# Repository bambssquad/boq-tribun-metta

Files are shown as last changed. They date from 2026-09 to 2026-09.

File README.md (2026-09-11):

# METTA — arsip desain, BOQ dan penawaran

RAB 11 September 2026: `tools.html#rab-11sep` compares all 50x100 hollow members at 1.6, 2.0 and 2.3 mm. Independent editable quantities/prices, stock audit, original Excel comparison and PDF/XLSX exports are available. The 361-cut schedule uses 101 six-metre bars at every thickness; section changes are budget studies and are not applied to Revit. The 6-mm connection plate uses five 1200x2400 sheets with unchanged connection blanks. `assets/r05/analisis-R05.md` records assumptions, sources and unresolved structural checks.

R04 (9 September 2026): `r04.html` is the selected all-in budget, with material, consumables, labor, logistics, overhead, profit and configurable output tax. Its purchasing-weight basis drives the Rp6,000/kg service toggle. Net theoretical and catalog purchasing weights have separate ledgers; unmeasured backing and concrete ties remain explicit provisional sums. Connections and stair supports are design proposals, not a fabrication release.

The current 3D projection contains 165 RHS members, 80 columns, 20 diagonals (10 X sets), 176 native stair plate parts and 310 native 2-mm cover parts. R04 overlays use saved Revit IDs/cut-length readbacks and common plate geometry; R03 source snapshots are retained unchanged. Rear/bottom covers are excluded. Four concrete columns are clipped from the 2-mm panel layout with 3-mm clearance. The archive opens on six current R04 CAD/PDF sheets followed by twelve clearly labeled R03 sheets. Revit sheet previews are under `assets/r04/revit/`.

R04 nesting compares 160 deterministic guillotine heuristics with 10-mm trim and 3-mm kerf: eight 3-mm sheets and twenty-six 2-mm sheets for the fixed current part list. This is the best searched arrangement, not a global optimality proof. `check_r04.py` verifies coverage, kerf/trim, stock capacity, native plate/cover dimensions and mass; `check_r04_web.py` verifies published IDs/counts and links. `r04_controller.test.cjs` checks loading, filters, service toggle, complete printing, sheet dialogs, exports and reset. Run these along with the existing validation and interaction tests. Browser visual parity is not asserted.

Web: https://bambssquad.github.io/boq-tribun-metta/

Halaman utama memuat Timeline, Surf, Indeks dan Proyek dalam hitam-putih tanpa musik. Menu membuka model 3D, gambar teknik interaktif, BOQ dan penawaran pada `tools.html`.

## BOQ dan jasa per kg

Buka **Menu → BOQ & biaya**, lalu aktifkan **Hitung jasa per kg**. Tarif awal Rp6.000/kg mencakup jasa fabrikasi dan pemasangan; material dihitung terpisah. Tarif dapat diubah. Menonaktifkan toggle mengeluarkan jasa dari total tanpa mengubah kuantitas atau harga material.

Dasar penagihan adalah berat pembelian: jumlah lonjor dibulatkan × panjang stok × kg/m, ditambah jumlah lembar dibulatkan × luas lembar × kg/m². Sisa potong termasuk sekali melalui jumlah stok. Saat input R02 dan allowance bawaan digunakan: 7.940,076 kg × Rp6.000 = Rp47.640.456 sebelum material, overhead dan pajak. Rincian setiap komponen dapat dibuka di panel jasa. Berat motif bordes belum terukur; sebagian item masih estimasi sebagaimana catatan BOQ.

**Buka template penawaran** menampilkan surat yang dapat diisi nama perusahaan, klien, nomor, tanggal, lingkup dan termin pembayaran. Nilai jasa mengikuti BOQ. Menu Ekspor menyediakan Excel berumus dengan lembar PENAWARAN, REKAP, INPUT, BOQ dan BERAT; sakelar Excel ada di INPUT!B14 (1 aktif, 0 nonaktif) dan tarif di INPUT!B13. PDF dibuat melalui dialog cetak browser.

Harga material yang kosong belum masuk total. Overhead dan pajak adalah input terpisah; tarif Rp6.000/kg bukan harga material. Spesifikasi dan validasi struktur tetap berada dalam lampiran teknis.

## Pengembangan

Gunakan Python 3.12+ dan Node 22+:

```sh
python -m pip install -r requirements.txt
python build_preview.py
python validate.py
node kg_pricing.test.cjs
node lookback.test.cjs
node panzoom.test.cjs
python publish_public.py
```

Commit sumber beserta hasil publikasi. GitHub Pages memakai berkas statis di root. Workflow memeriksa bahwa halaman terbit sesuai hasil build. Generator `src/` dipertahankan; `build_preview.py` menerapkan data model revisi, `kg_pricing.py` menambahkan tarif jasa, dan `lookback.py` membuat halaman arsip terpisah. `data/` mencatat kuantitas dan asal geometri. `assets/technical/` memuat 12 DXF/SVG, PDF gabungan dan ekspor sheet Revit.

Referensi visual: https://tlb.betteroff.studio/. Implementasi interaksi dan konten METTA dibuat terpisah; musik, font komersial dan kode referensi tidak disertakan.

R03: seluruh 12 gambar kini memiliki 136 dimensi CAD dan label LOD 200. Dimensi terdaftar pada assets/technical/dimensions-R03.json; python check_dimensions.py memeriksa entitas CAD, satuan, PDF dan dasar angka. Jalankan python technical.py untuk memperbarui gambar, lalu build_preview.py. URL unduhan R02 dipertahankan agar tautan lama tetap berfungsi; isi dokumennya telah direvisi R03. Geometri dan harga BOQ tetap. Revit menerima anotasi garis/teks native dan skema dimensi pendamping; belum berupa dimensi asosiatif ke model.

SAP branding: nama lengkap SELARAS ADHI PERKASA tampil pada awal, lalu beralih menjadi SAP ketika scroll dan navigasi; scroll balik mengembalikan nama lengkap. Judul proyek dua baris: ARSIP DESAIN METTA dan (09/2026). Header halaman teknis memakai SAP. Pengujian meliputi wheel, touch, keyboard, menu dan navigasi.

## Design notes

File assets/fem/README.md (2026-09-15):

# METTA - FEM rangka primer tersambung

Ini studi elastis linier 3D dengan enam derajat kebebasan per simpul. Implementasi Python memakai matriks balok Euler-Bernoulli 12 x 12, kekakuan aksial EA/L, torsi Saint-Venant GJ/L, dan dua sumbu lentur. Solver sparse langsung memakai penskalaan diagonal. Tidak ada weak spring atau penambahan tumpuan otomatis saat matriks singular.

## Lingkup dan batas

V1 berasal dari 245 batang RHS native R04. V2 Dasar mengambil native yang dipertahankan dan 54 batang infill R08 selebar 1.400 mm. A/C menambahkan jalur semua 30 tapak melalui 60 girder B02 yang sudah dihitung dalam RAB, 40 riser lap dan dukungan per tier. SHS B03 ditransfer sebagai balok sederhana tanpa kekakuan global. Luas A/C mencakup tambahan 5.999915 m² tapak; Dasar tidak memasukkan beban tangga sehingga bukan perbandingan luas identik. Matriks seluruh geometri singular: 14 batang V1 dan 6 batang V2 tidak memiliki jalur sambungan geometris ke kolom. `excludedSourceIds` mencatat setiap batang tersebut. Submodel yang dihitung hanya jaringan terhubung ke kolom. `grossDeckAreaM2`, `areaM2`, dan `excludedTributaryAreaM2` membedakan seluruh dek, area yang membebani submodel, dan area yang terlewat.

Sambungan dalam jarak sumbu 110 mm diidealkan kaku penuh, termasuk eksentrisitas. Transformasi offset eksak memakai u_slave = u_master + theta cross r. Node pada sumbu yang berjarak kurang dari 5 mm disatukan untuk menghindari elemen numerik sangat pendek; kedua ujung sumber tetap. Semua kontak ini tercantum di `rigidOffsets`. Kedekatan dua solid bukan bukti las atau sambungan: detail sambungan tetap perlu diperiksa insinyur. Kaki kolom dianggap jepit penuh untuk skenario utama, yaitu perkiraan kekakuan atas. Ini bukan bukti lantai atau angkur dapat memberi penjepitan. Sensitivitas `boundarySensitivity` membebaskan rotasi kaki namun tetap menahan semua translasi; skenario ini juga memerlukan angkur, bukan kaki bebas geser/angkat.

Penampang sudut tajam RHS 50x100 memakai tebal nominal 1.6, 2.0, 2.3 mm, E=200000 MPa dan nu=0.3. Orientasi batang horizontal tinggi 100 mm vertikal; kolom lebar 50 mm global X, tinggi penampang 100 mm global Y. Tebal efektif, radius sudut, variasi mutu, tekuk lokal, sambungan dan korosi tidak dihitung. V1/V2 Dasar mengecualikan tangga. A/C memasukkan B02 dan semua tapak, tetapi anggota sekunder SHS, pagar dan mesh tidak memberi kekakuan global; perubahan SHS tidak boleh diklaim mengubah hasil global ini.

Beban D=1.5 kPa dan L=5 kPa adalah skenario yang dipertahankan dari studi R06. D merupakan allowance total termasuk berat sendiri, sehingga berat rangka tidak ditambah lagi. Empat kasus D, L, D+L, 1.2D+1.6L tersedia untuk tiap versi dan tebal. Nilai 1.2D+1.6L hanya satu kombinasi gravitasi, bukan seluruh kombinasi desain. Permukaan dek disatukan per elevasi agar area tumpang tindih tidak dihitung dua kali, kemudian dikurangi footprint beton dengan celah 3 mm. Luas geometris ini tidak menggantikan kuantitas RAB. Permukaan dek dipotong pada batas tributari tengah antar batang yang menyentuh dek (sumbu sekitar 54 mm di bawah permukaan), dengan ukuran sel sepanjang batang maksimum 100 mm pada keluaran utama. Pelat penutup kecil tanpa batang kontak menggunakan sumbu terdekat. Gaya dan kopel dari centroid sel diteruskan ke simpul rangka agar gaya total dan momen global tekanan tetap persis. Transfer ini mengasumsikan pelat dapat memindahkan beban dan kopel tersebut; kekuatan/kekakuan pelat tidak diperiksa. Sensitivitas sel 400, 200 dan 100 mm tersedia di manifest. Konvergensi numerik tidak membuktikan jalur beban atau sambungan aktual; jangan pakai hasil ini untuk fabrikasi.

Tidak termasuk P-delta, nonlinearitas, tekuk global/lokal, kekuatan penampang, sambungan/angkur, gempa, angin, getaran, pondasi atau kapasitas beton. Tidak ada status aman atau lulus SNI. Hasil adalah studi kondisional, bukan analisis SAP2000/Tekla, dan bukan sertifikasi struktur.

## Koreksi sumbu dan diskretisasi

Empat balok diagonal dekat beton dahulu diambil dari bounding box sebagai batang lurus. Hal itu memutus hubungan numerik dan menghasilkan angka sekitar 24 mm. Sumbu sekarang direkonstruksi dari panjang potong, panjang sistem dan grid kolom; empat pengaku lama juga memakai offset ujung native. Bukti tersimpan dalam `data/member-axis-corrections.json`. Perbaikan model hitung ini bukan bukti bangunan pernah mengalami deformasi tersebut. Bounding box empat balok cocok dalam 0.022 mm; empat pengaku memakai panjang/offset audit dengan selisih terhadap kotak visual lama maksimum 2.72 mm.

RHS 2.3 mm, D+L=6.5 kPa, asumsi tumpuan seperti dijelaskan:

| Model | Sel 100 mm (tampilan) | Sel 50 mm (pembanding) | Perubahan |
|---|---:|---:|---:|
| V1 primer | 2.0802 mm | 2.0793 mm | 0.0403% |
| V2 Dasar primer | 1.2665 mm | 1.2696 mm | 0.2417% |
| V2 A termasuk dua tangga | 1.2674 mm | 1.2705 mm | 0.2401% |
| V2 C termasuk dua tangga | 1.2656 mm | 1.2687 mm | 0.2479% |

Semua 48 kasus memakai sel 100 mm. Ini sensitivitas numerik terhadap pembagian beban, bukan pembuktian kapasitas. Riser lap berada di luar sisi tapak supaya tidak menembus pelat; sambungan las sisi, cope antar batang dan kapasitas dinding RHS tetap perlu detail.

## Konvensi keluaran

Panjang mm, gaya N, momen Nmm, rotasi rad. Sumbu lokal x dari a ke b; z mengikuti global Z sejauh mungkin (kolom menggunakan global Y); y=z cross x. `i` dan `j` adalah gaya nodal lokal [N,Vy,Vz,T,My,Mz] di kedua ujung, sesuai matriks elemen. Scalar tiap komponen memilih nilai ujung dominan dengan tanda gaya ujung asli. Ini envelope gaya ujung, bukan diagram internal sepanjang batang kontinu. Deformasi display dapat dibesarkan tetapi data tetap mm aktual. Animasi perubahan faktor skala bukan analisis dinamik.

Model geometri tersedia dalam `model.json.gz`. Dua belas file `solution-v*-h*.json.gz` dikompresi gzip deterministik (mtime=0) dan berisi hasil untuk tekanan 1 kPa. Manifest `results.json` memuat 48 kasus, `solutionId` dan `resultScale`. Hasil perpindahan, gaya dan reaksi dikalikan faktor ini; summary kasus sudah diskalakan. Ini superposisi elastis linier eksak, bukan interpolasi hasil ketebalan.

## Reproduksi

Manifest menyimpan hash sumber solver dan geometri. `check_fem.py` menolak hasil lama bila sumber berubah; jalankan generator kembali setelah revisi geometri.

Dependensi: Python, numpy, scipy, shapely; sumber r04_model.py dan data R04/R08 di repositori.

```
python fem_model.py
python check_fem.py
```

Uji mencakup enam rigid-body modes, simetri, kantilever aksial/torsi/lentur dua arah, balok sendi-rol beban titik tengah, transformasi offset kaku, penolakan mekanisme bebas, keseimbangan gaya dan momen seluruh 48 kasus, area-tekanan, tren tebal dan perbedaan geometri V1/V2. Uji analitik membuktikan formulasi solver; tidak membuktikan asumsi sambungan dan beban bangunan.

## Referensi primer metode

- TU Delft, Euler-Bernoulli beam elements: https://interactivetextbooks.citg.tudelft.nl/computational-modelling/structural_linear/euler_bernouilli.html
- numgeo, beam formulation and local/global transformation: https://j-machacek.github.io/numgeo/theory/elements/beam.html
- TU Delft, 3D Euler beam stiffness research: https://pure.tudelft.nl/ws/portalfiles/portal/55207149/6.2019_3272.pdf

Referensi metode diperiksa pada 15 September 2026. Numgeo menjelaskan pula deformasi geser Timoshenko; implementasi ini memakai batas Euler-Bernoulli tanpa deformasi geser.

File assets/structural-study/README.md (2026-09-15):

# Perbandingan A/C - dua tangga penuh

Koreksi sumbu native menghilangkan putus sambungan numerik yang menghasilkan angka lama sekitar 24 mm. A/C bukan klaim bahwa penambahan material itu yang menghilangkan 24 mm.

A memakai rangka utama, 40 penghubung riser las, 10 cleat pendek dan dua header ke kolom beton pada landing tengah. C memakai 40 penghubung riser serta lima kotak penopang per tangga (40 kolom, 40 balok, 40 diagonal). Sebanyak 60 girder sisi B02 tetap berasal dari RAB dasar; tidak dihitung dua kali. Seluruh 30 tapak masuk beban A/C, sebesar 5.999915 m². Ini menggantikan percobaan kasar menumpuk seluruh beban flight hanya pada satu landing.

`options-spec.json` merupakan geometri usulan dan input RAB. `analysis.json` berisi tiga tebal RHS, tegangan gross, reaksi angkur (demand saja), pemeriksaan benturan, pemeriksaan SHS lokal serta beban horizontal fiktif 0.2%. Beban horizontal tersebut hanya uji kekakuan elastis orde pertama; bukan analisis langsung AISC, gempa, angin atau P-delta.

## Batas keputusan

- RHS1.6 mendekati Fy235 pada screening tegangan gross gabungan. Nilai di bawah Fy tidak membuktikan kapasitas setelah tekuk lokal/global, reduksi tebal, las dan sambungan.
- Semua kaki (80 kolom utama, infill dan kaki C) mengandalkan kapasitas lantai/angkur yang belum diketahui. Budget angkur tidak membuktikan tumpuan jepit. Pad karet10mm perlu verifikasi tekan dan slip.
- Railing SHS40x40 kantilever1100mm belum memenuhi target lendutan11mm untuk keempat tebal. Kandidat berikutnya A=SHS60x60x2.3; C=pengaku atau distribusi beban pegangan yang dihitung. Kandidat ini belum mengganti gambar/RAB pagar.
- SHS B03 diperiksa lokal sebagai balok550mm dengan tributari115mm dan kasus beban titik1.334kN. Pelat3mm, lipatan, luas kontak beban titik dan sambungan masih membutuhkan pemeriksaan pelat terpisah.
- Las pada riser lap166.7mm dan cleat45mm harus dibuktikan mampu meneruskan momen. Hardware/konsumsi las dalam RAB hanya allowance.
- Analisis stabilitas orde kedua, beban lokasi, gempa/angin, getaran kerumunan dan kapasitas beton belum lengkap. Tidak ada status siap fabrikasi atau aman terverifikasi.

## Reproduksi

```
python geometry_axes.py
python structural-study.py
python fem_model.py
python structural-study.py --analyse
python check_fem.py
node check_fem_viewer.cjs
```

Sumber primer metode dan pemeriksaan tersedia di analysis.json dan assets/fem/README.md. Semua asumsi harus ditinjau sebelum keputusan pelaksanaan.

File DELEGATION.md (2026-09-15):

# Delegation plan
Units: 3

Gate open: three independent units; user requested colony. Current correction replaces the sketched right stair strip with seating deck, and investigates structural improvements. V1 design remains archived, with corrected interpretation of native diagonal axes.

| # | Unit | Files (mine) | Worker | Acceptance | Status |
|---|---|---|---|---|---|
| 1 | Geometry, quantities, PDF, integration and publication | r08.py, r08_options.py, boq_revision_web.py, check_r08.py, r08.test.cjs, pdf-mass.test.cjs, r08-pdf.cjs, generated assets/r08 data/geometry/audit/csv/pdf, DELEGATION.md, workflow, publication copies | root | Sketched strip has no stairs; geometry and quantities reconcile; PDF and publication payload match | verified |
| 2 | Version display and technical drawings | r04_model.py, site_version.py, site-version.js, site-version-viewer.js, boq-revision.js, boq-revision-controller.js, r08_drawings.py, detail_drawings.py, check_site_version.cjs, check_detail_drawings.py, drawing-viewer.js, generated SVG and drawing manifests | drawings + root integration | V2 infill 1400 mm and two stair strips; V1 geometry retained with corrected member axes; browser and drawing tests pass | verified |
| 3 | Structural diagnosis and verified improvement study | fem_model.py, check_fem.py, geometry_axes.py, data/member-axis-corrections.json, assets/fem/*, fem-viewer.js, check_fem_viewer.cjs, structural-study.py, assets/structural-study/* | fem | Numerical benchmarks and equilibrium pass; improvement compared under identical loads; limitations explicit | verified |

## Evidence
User selected comparison A (main concrete columns) and C (independent frame). All three local acceptance units are verified; publication follows. No safety or fabrication approval is inferred from elastic deformation alone.

- Root independently ran `node check_site_version.cjs` and `python check_detail_drawings.py`; actual A/C member vertices, column counts, independent edits and XML sheets match. Browser front view confirms precisely two stair strips and continuous seating at the sketched strip. Root applied final component-label integration for main-floor anchors.
- Root independently checked eight reconstructed axis lengths against native Cut Length; four bearer bounding residuals below0.022mm and four brace residuals below2.712mm. Corrections describe geometry interpretation, not new steel.
- Root rendered and inspected all26 portrait RAB pages (base8,A9,C9). `python check_r08.py` reconciles source cut deltas, all thickness masses, removed struts, shared plate nesting, floor/RC anchor counts, and every PDF row and total.

- Root independently passed all 38 workflow checks, including 48 equilibrium/benchmark FEM cases, 540 RAB combinations and 30 PDF exports. Browser confirms A/C service displacements 1.267/1.266 mm at RHS 2.3, and 1.777 mm A at 1.6. Fixed stale FEM fetch and missing-model failure gating; targeted viewer tests passed again.

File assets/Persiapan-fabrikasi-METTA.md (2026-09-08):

# METTA — persiapan fabrikasi, belum terbit untuk produksi

## Revisi model 3D

Enam belas diagonal diberi Mark X01-A sampai X08-B. Titik bawah diubah dari +18 menjadi +150 mm terhadap LT4; titik atas tetap +2350 mm. Tujuannya memberi ruang dari zona dudukan. Potongan C-C telah diperiksa secara visual. Ini koreksi koordinasi, bukan ukuran sambungan yang sudah dihitung. Delapan pasangan dikelompokkan sebagai assembly koordinasi; jangan mengelas kedua diagonal pada persilangan hanya karena berada dalam satu assembly.

Daftar potong optimal diperbarui dari parameter model sesudah perubahan: 161 framing memerlukan minimum 75 batang stok 6 m untuk input studi ini. Panjang potongan 415.239 mm, kerf 483 mm, sisa 34.278 mm. Sisa termasuk kerf 7,725%. Hasil sebelumnya 7,389% sudah digantikan. Kolom, railing, plat, trimming stok dan allowance sambungan belum termasuk.

## Ketentuan dari web Bam

Sumber: https://bambssquad.github.io/boq-tribun-metta/ , salinan proyek dengan DATA.rev 9056af5e6b. Pembacaan daring ulang gagal; ketentuan di bawah dibaca dari salinan yang sudah tersimpan.

| Detail web | Isi sumber | Perlakuan pada revisi |
|---|---|---|
| Tumpuan | Base 150×150×8, karet 10; duduk lepas, tanpa angkur pelat lantai | Pertahankan prinsip tanpa pengeboran lantai; verifikasi reaksi dan geser/angkat melalui jalur ikatan kolom |
| D1 balok-kolom | 2 M12 grade 4.6 + pelat siku 6, atau las a=4 dua kali 80 | Pilihan detail harus sesuai gaya dan dinding RHS; belum instruksi produksi |
| D2 bracing-kolom | Buhul 6 mm 200×200; las a=4 dua sisi 40 | Web semula untuk bracing 40×40×2, kini model 50×100×2,3; tidak bisa langsung dianggap detail lolos |
| D3 strut-beton | Pelat 6, 2 dynabolt M10, kedalaman 80 | Hanya ke kolom beton. Produk, tulangan, tepi, kapasitas dan beban masih harus diverifikasi |
| D4 railing-dek | Las a=4 keliling | Dek berkurang 8 menjadi 4 mm; periksa transfer momen railing ke rangka, bukan plat saja |

Istilah las a=4 pada web perlu dipastikan: tebal tenggorokan atau panjang kaki las. Jangan menerjemahkannya diam-diam ke spesifikasi lain. Tidak ada gusset, lubang angkur atau simbol las final yang ditambahkan atas dasar angka web saja.

## Data yang ditunggu

Bam menyatakan spesifikasi material sudah dikonfirmasi dan akan memberikan sertifikat. Dokumen belum diterima pada saat pembaruan ini. Perlu tebal dasar bordes tanpa motif, standar/grade hollow, tebal aktual dan sertifikat yang terkait material yang dibeli. Untuk ikatan kolom beton diperlukan data struktur eksisting dan verifikasi insinyur struktur. Gambar arsitektur dan BOQ tidak menyediakan kapasitas tersebut.

Model dan daftar potong boleh dipakai untuk koordinasi dan estimasi. Jangan mulai pemotongan, pengelasan atau pengeboran dari paket ini sebelum detail serta perhitungan diselesaikan.

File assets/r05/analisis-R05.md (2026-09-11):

# METTA — verifikasi batang, kilogram dan RAB 11 September 2026

Status: perbandingan anggaran dan penyaringan awal struktur. Belum menjadi desain pelaksanaan yang telah memenuhi seluruh pemeriksaan standar.

## Keputusan yang digunakan

- Toggle 1,6 / 2,0 / 2,3 mm berlaku pada seluruh hollow 50×100: kolom, balok, pengaku, bracing dan usulan penyangga tangga. Dimensi luar, posisi, panjang potong dan jumlah tempat duduk tetap.
- Model Revit masih 2,3 mm. Versi 1,6 dan 2,0 mm adalah skenario perbandingan, belum diterapkan ke model native.
- Ukuran stok pelat sambungan 6 mm adalah 120×240 cm. Potongan kupingan 90×120 mm dan buhul 200×200 mm tetap.

## Mengapa 54 batang di Excel berbeda dari 101 di web

Lima baris hollow 50×100 pada Excel berjumlah 1.620 kg. Dibagi asumsi 30 kg/batang menghasilkan 54 batang. Dengan massa katalog 32,5 kg/batang, nilainya 49,85 batang ekuivalen. Keduanya belum membuktikan jumlah batang yang dapat dipotong menjadi seluruh anggota model.

| Lingkup | Potongan | Panjang bersih | Stok 6 m bila dipotong terpisah | Berat pembelian 2,3 mm |
|---|---:|---:|---:|---:|
| Rangka dan kolom Revit | 245 | 552,301 m | 97 | 3.152,50 kg |
| Penyangga tangga usulan | 116 | 37,837 m | 7 | 227,50 kg |
| Seluruhnya, sisa potong dipakai bersama | 361 | 590,138 m | 101 | 3.282,50 kg |

97 + 7 menjadi 101 saat dipotong bersama; sisa batang dari kelompok pertama digunakan untuk potongan kelompok lain. Angka 101 adalah solusi pola potong yang layak, bukan bukti optimum global. Sebanyak 361 ID potongan unik telah diperiksa. Tidak ada geometri RHS duplikat persis atau pengaku memanjang segaris yang menumpuk pada arsip geometri yang direkonsiliasi.

| Komponen | Potongan | Panjang model | Kg bersih penampang 2,3 mm | Kg pembelian teralokasi | Kg Excel |
|---|---:|---:|---:|---:|---:|
| Kolom tribun | 80 | 133,560 m | 686,96 | 738,95 | 637 |
| Balok tepi tier | 15 | 73,710 m | 379,12 | 409,49 | 416 |
| Pengaku longitudinal dek | 45 | 226,069 m | 1.162,78 | 1.243,32 | 416 |
| Rangka belakang | 4 | 17,396 m | 89,48 | 95,11 | 98 |
| Strut ke kolom beton | 16 | 2,172 m | 11,17 | 11,85 | 53 |
| Bracing X | 20 | 42,388 m | 218,02 | 235,70 | 62 (40×40×2) |
| Balok silang penumpu dek | 65 | 57,006 m | 293,21 | 314,04 | Tidak terpisah |
| Penyangga tangga / usulan | 116 | 37,837 m | 194,61 | 234,03 | Tidak terpisah |

Perbedaan utama adalah pengaku longitudinal: Excel 416 kg, sedangkan 45 anggota model memiliki panjang 226,069 m dan massa penampang bersih sekitar 1.162,78 kg. Sebanyak 65 balok silang dihitung terpisah. Bracing Excel memakai 40×40×2 mm, sedangkan bracing model aktif memakai 50×100×2,3 mm. Penyangga tangga 116 potongan masih usulan tambahan dan diberi label tersebut.

Berat bersih penampang memakai dimensi luar dan sudut membulat; berat pembelian memakai massa katalog stok. Nilai ini tidak boleh dicampur saat mengonversi kg menjadi jumlah batang. Berat timbang, sertifikat dan tebal aktual produk belum tersedia.

## Perbandingan tebal seluruh hollow 50×100

| Tebal | Jumlah stok | Kg/batang 6 m | Total kg pembelian | Harga/batang untuk anggaran | Dasar |
|---|---:|---:|---:|---:|---|
| 1,6 mm | 101 | 22,61 | 2.283,61 | Rp 302.278 | Estimasi: massa interpolasi katalog 1,5/1,8 mm dan harga/kg Excel 2,3 mm; bukan penawaran 1,6 mm. |
| 2,0 mm | 101 | 28,26 | 2.854,26 | Rp 373.900 | Katalog SMS Perkasa, harga tayang 27 Agustus; dibaca 11 September 2026. |
| 2,3 mm | 101 | 32,50 | 3.282,50 | Rp 434.500 | Katalog SMS Perkasa; sama dengan tarif Excel. |

Untuk 1,6 mm, massa 22,61 kg merupakan interpolasi katalog 1,5 dan 1,8 mm. Harga/kg memakai tarif 2,3 mm dalam Excel. Harga tersebut belum menjadi harga pemasok 1,6 mm. Untuk 2,0 dan 2,3 mm, massa dan harga berasal dari katalog SMS Perkasa yang menampilkan tanggal harga 27 Agustus 2026, dibaca 11 September 2026.

| Versi | Upah/jasa | Material | Total tanpa pelengkap | Total dengan pelengkap |
|---|---:|---:|---:|---:|
| 1,6 mm / studi | Rp 62.493.320 | Rp 159.639.227 | Rp 222.132.547 | Rp 251.647.547 |
| 2,0 mm / studi | Rp 65.917.221 | Rp 166.873.018 | Rp 232.790.239 | Rp 262.305.239 |
| 2,3 mm / model | Rp 68.486.661 | Rp 172.993.619 | Rp 241.480.280 | Rp 270.995.280 |

Semua total sebelum overhead, laba dan pajak tambahan. Pelengkap proyek Rp 29.515.000 mencakup backing/hardware, antiselip, clear coat, tekuk, transportasi, alat angkat, perancah, pengukuran, proteksi dan cadangan pemeriksaan desain/tumpuan. Alat kerja dan kawat las mengikuti pembagian biaya sumber; listrik disediakan METTA. Perubahan desain sambungan atau penguatan dapat mengubah biaya tersebut.

## Pelat sambungan: lembar 120×240 cm

- Stok: 5 lembar × 1,2 m × 2,4 m × 0,006 m × 7.850 kg/m³ = 678,24 kg teoritis.
- Potongan tetap: 464 kupingan tangga + 548 kupingan rangka berukuran 90×120 mm, serta 40 buhul 200×200 mm; total 1.052 bagian.
- Luas potongan 12,5296 m²; berat bersih 590,144 kg sebelum lubang. Berat beli mencakup seluruh sisa lembar sekali.
- Lima lembar dibuktikan dengan pola penempatan. Batas tepi 10 mm, celah potong 3 mm, semua bagian berada dalam lembar dan tidak bertumpuk.
- Nilai lama 700 kg menggunakan 5 × 140 kg katalog. Untuk stok tepat 1200×2400 mm, massa dihitung ulang menjadi 678,24 kg; tarif/kg tetap dari Excel. Ukuran buhul tidak diganti menjadi ukuran lembar.
- Berkas pola pelat dan pola batang tersedia sebagai CSV; berat batang dicantumkan hanya sekali per stok agar penjumlahan tidak berulang.

## Audit sumber model

- Revit 2027: 385 elemen dibaca, termasuk 175 framing, 165 kolom/tiang railing, 30 dek dan 15 papan pinus. Seluruh 165 ID RHS dan panjang potongnya cocok dengan R04.
- SHA256 model tersimpan sama dengan checkpoint R04. Ekspor IFC baru gagal transaksi; geometri arsip yang direkonsiliasi dan registri native tetap disebut sebagai sumber.
- Luas dek 82,345049121 m². Dua elemen 1686791 dan 1686827 mengembalikan luas nol; tidak diberikan luas fiktif.
- Pelat tangga 176 bagian dan penutup 310 bagian memakai registri native R04. Sebagian penyangga dan detail sambungan masih usulan anggaran.
- Family 10 rail horizontal masih bernama M_W Shapes dan menyimpan properti profil lama. Beberapa properti A/W kolom juga lama; biaya memakai panjang, penampang dan massa katalog yang dijelaskan, bukan berat family tersebut.

## Batas penyaringan struktur

Asumsi: E 200.000 MPa, Fy 235 MPa, massa jenis 7.850 kg/m³, radius luar 2t dan radius dalam t. Beban mati 1,5 kN/m², hidup 5 kN/m², titik 1,334 kN. Beban merata dan titik diperiksa sebagai alternatif bersama beban mati. Kombinasi gravitasi 1,2D+1,6L; batas lendutan L/360. Tebal 93% nominal hanya sensitivitas, bukan toleransi produk yang telah dibuktikan.

| Tebal nominal | Rasio lentur pengaku, 2 m | Rasio lentur balok silang | Kesimpulan terbatas |
|---|---:|---:|---|
| 1,6 mm | 0,533 | 1,004 | Balok silang melewati batas kasus |
| 2,0 mm | 0,435 | 0,820 | Lolos kasus batang ini; belum membuktikan rangka |
| 2,3 mm | 0,384 | 0,724 | Lolos kasus batang ini; belum membuktikan rangka |

Pengaku memakai lebar tributari 250 mm dan bentang minimal 2 m. Balok silang diuji bentang 1.060 mm dengan lebar tributari 1,77 m. Tumpuan dan pengekangan lateral disimpulkan dari geometri untuk studi; keduanya harus dibuktikan pada detail. Kapasitas kolom hanya dihitung untuk sensitivitas tekan murni K=1 dan K=2, tanpa rasio kelulusan karena gaya rangka belum ditentukan.

Versi 1,6/2,0/2,3 mm adalah perbandingan biaya untuk susunan yang sama. Versi seluruh rangka 1,6 mm tidak lolos kasus penyaringan balok silang pada tebal asumsi 1,488 mm. Tidak satu pun versi dinyatakan memenuhi seluruh pemeriksaan struktur.

Belum selesai: analisis rangka tiga dimensi, stabilitas/goyang, gempa, getaran akibat aktivitas serempak, diafragma, pelat/tapak lokal, dinding hollow pada reaksi, las/baut, angkur, transfer gaya melalui base plate/karet, dan kapasitas beton LT4. Data sertifikat baja, tebal aktual, mutu beton serta tulangan dibutuhkan untuk menutup pemeriksaan tersebut.

## Koreksi terhadap Excel sumber

- Subtotal upah I32 dan material J32 berhenti di baris 30, sehingga cat pada baris 31 terlewat. Rekap sumber lengkap: upah Rp 62.143.000, material Rp 156.653.686, total Rp 218.796.686.
- Label paket baut + mur + ring dipecah supaya tidak ditafsirkan ganda. Tangga memakai 488 baut, 488 mur dan 976 ring; rangka 693 baut, 693 mur dan 1.386 ring masih berdasarkan usulan sambungan.
- Karet mengikuti 80 titik dudukan. Pinus mengikuti volume 1,197016252 m³, menjadi 74,813516 m bersih dan 82,294867 m pembelian dengan sisa 10%.
- Cat mengikuti luas estimasi 626,0562 m². Nilai paket Excel Rp 28.885.500 dinormalisasi menjadi tarif/m²; penipisan dinding hollow tidak menurunkan luas permukaan cat.
- Angkur 32 buah M10 pada Excel diganti cadangan biaya ikatan beton karena jumlah dan kapasitasnya belum ditetapkan.

## Sumber primer

SNI 1727:2020 menjadi acuan beban; SNI 1729:2020 mengadopsi AISC 360-16 untuk baja struktural. SNI 7971:2013 digunakan bila produk/sistem berada dalam ruang lingkup baja canai dingin. Jalur standar harus mengikuti spesifikasi produk, bukan tebal saja. Gempa dan beton juga memerlukan SNI 1726:2019 serta SNI 2847:2019. Studi ini tidak menyatakan seluruh persyaratan tersebut telah dipenuhi.

- [SNI 1727:2020](https://pesta.bsn.go.id/produk/detail/12927-sni17272020)
- [SNI 1729:2020, adopsi AISC360-16](https://pesta.bsn.go.id/produk/detail/12882-sni17292020)
- [SNI 7971:2013; bila standar produk canai dingin berlaku](https://pesta.bsn.go.id/produk/detail/9714-sni79712013)
- [AISC360-16 B4, E3/E7, F7, G5](https://www.aisc.org/globalassets/aisc/publications/standards/a360-16-spec-and-commentary_june-2019_linked.pdf)
- [ICC300-2017 303; pembanding beban tribun](https://codes.iccsafe.org/content/ICC3002017/chapter-3-construction?site_type=public)
- [Katalog hollow50x100x1,6; tanpa harga/sertifikat](https://jualbesi.com/produk/besi-hollow-hitam-50x100x1-6/)
- [Harga dan massa stok pembanding1,5/1,8/2,3mm, 11 September2026](https://www.smsperkasa.com/produk/besi-hollow-hitam)

Tidak ada pemasok yang dihubungi dan tidak ada pembelian yang dilakukan.

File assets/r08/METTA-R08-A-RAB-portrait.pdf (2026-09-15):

# SAP / SELARAS ADHI PERKASA

## RENCANA ANGGARAN BIAYA - METTA

R08 - Infill sesuai gambar + mesh sisi / Hollow 2,3 mm / model / SHS acuan 2,0 / 2,8 mm / A / bantuan kolom beton / Mesh 25x25 /
2,0 mm | 2026-09-15 | Pembelian | Dengan biaya pelengkap

STUDI OPTIMASI. BELUM UNTUK FABRIKASI.

No. | Pekerjaan / spesifikasi | Volume | Sat. | Upah/sat. | Material/sat. | Jumlah upah | Jumlah material | Total
1 | Kolom tribun Hollow 50x100x2,3 mm | 738,9357 | kg | 6.000 | 13.369 | 4.433.614 | 9.879.002 | 14.312.616
2 | Balok tepi tier Hollow 50x100x2,3 mm | 405,2193 | kg | 6.000 | 13.369 | 2.431.316 | 5.417.470 | 7.848.786
3 | Pengaku longitudinal dek Hollow 50x100x2,3 mm | 1.249,7162 | kg | 6.000 | 13.369 | 7.498.297 | 16.707.745 | 24.206.042
4 | Rangka belakang Hollow 50x100x2,3 mm | 94,7112 | kg | 6.000 | 13.369 | 568.267 | 1.266.216 | 1.834.483
5 | Strut ke kolom beton Hollow 50x100x2,3 mm | 0 | kg | 6.000 | 13.369 | 0 | 0 | 0
6 | Bracing X Hollow 50x100x2,3 mm | 234,0089 | kg | 6.000 | 13.369 | 1.404.054 | 3.128.519 | 4.532.573
7 | Balok silang penumpu dek Hollow 50x100x2,3 mm | 312,9445 | kg | 6.000 | 13.369 | 1.877.667 | 4.183.827 | 6.061.494
Subtotal Rangka utama | | | | | | 18.213.215 | 40.582.779 | 58.795.994
8 | Penyangga tangga / usulan Hollow 50x100x2,3 mm | 108,1501 | kg | 6.000 | 13.369 | 648.901 | 1.445.884 | 2.094.785
9 | Pelat tekuk tangga Pelat polos 3 mm | 271,296 | kg | 6.000 | 12.286 | 1.627.776 | 3.333.065 | 4.960.841
10 | Pengaku tapak tangga / usulan SHS 40x40x2 mm | 168,1487 | kg | 6.000 | 12.987 | 1.008.892 | 2.183.691 | 3.192.583
11 | Baut tangga M12x40 kelas 8.8 | 84 | bh | 1.000 | 4.500 | 84.000 | 378.000 | 462.000
12 | Mur tangga M12 kelas 8 | 84 | bh | 1.000 | 1.500 | 84.000 | 126.000 | 210.000
13 | Ring tangga Ring datar keras M12 | 168 | bh | 50 | 750 | 8.400 | 126.000 | 134.400
Subtotal Tangga | | | | | | 3.461.969 | 7.592.640 | 11.054.609
14 | Rail atas / elemen horizontal SHS 40x40x2 mm | 30,14 | kg | 6.000 | 12.987 | 180.840 | 391.418 | 572.258
15 | Tiang railing dan pegangan SHS 40x40x2,8 mm | 379,8 | kg | 6.000 | 13.128 | 2.278.800 | 4.986.000 | 7.264.800
Subtotal Railing | | | | | | 2.459.640 | 5.377.418 | 7.837.058
16 | Pelat dek Bordes 4 mm | 3.074,688 | kg | 5.000 | 12.937 | 15.373.440 | 39.777.239 | 55.150.679
17 | Riser, fascia dan return Pelat polos 2 mm | 904,32 | kg | 6.000 | 12.296 | 5.425.920 | 11.119.787 | 16.545.707
18 | Papan pinus dudukan Lebar 400 mm; tebal 40 mm | 89,6765 | m | 25.000 | 90.000 | 2.241.913 | 8.070.887 | 10.312.800
19 | Panel kayu sandaran Lebar 400 mm; tebal 40 mm | 20,0475 | m | 25.000 | 90.000 | 501.188 | 1.804.275 | 2.305.463
20 | Cat dan coating baja Persiapan + cat; luas permukaan | 617,039 | m² | 13.183 | 32.956 | 8.134.131 | 20.335.327 | 28.469.458
Subtotal Dek, penutup dan finishing | | | | | | 31.676.592 | 81.107.515 | 112.784.107
21 | Base plate Pelat 150x150x8 mm | 146,6465 | kg | 6.000 | 11.695 | 879.879 | 1.715.058 | 2.594.937
22 | Pelat sambungan rangka, tangga dan buhul Pelat 6 mm; lembar 120x240 cm | 542,592 | kg | 5.000 | 12.543 | 2.712.960 | 6.805.654 | 9.518.614
23 | Baut rangka dan X M12x40 kelas 8.8 | 777 | bh | 1.000 | 4.500 | 777.000 | 3.496.500 | 4.273.500
24 | Mur rangka dan X M12 kelas 8 | 777 | bh | 1.000 | 1.500 | 777.000 | 1.165.500 | 1.942.500
25 | Ring rangka dan X Ring datar keras M12 | 1.554 | bh | 50 | 750 | 77.700 | 1.165.500 | 1.243.200
26 | Ikatan ke kolom beton / cadangan Angkur dan pelat: belum ditetapkan | 0 | ls | 0 | 2.500.000 | 0 | 0 | 0
METTA / Hollow 2,3 mm / model | 1 / 9

No. | Pekerjaan / spesifikasi | Volume | Sat. | Upah/sat. | Material/sat. | Jumlah upah | Jumlah material | Total
27 | Sekrup kayu ke baja + ring #12x65 / usulan | 540 | set | 300 | 1.500 | 162.000 | 810.000 | 972.000
28 | Sekrup penutup + ring EPDM #12x32 / usulan | 3.909 | set | 300 | 800 | 1.172.700 | 3.127.200 | 4.299.900
29 | Karet dudukan 150x150x10 mm | 80 | bh | 500 | 25.000 | 40.000 | 2.000.000 | 2.040.000
Subtotal Sambungan dan pengikat | | | | | | 6.599.239 | 20.285.412 | 26.884.651
30 | Backing riser depan dan hardware railing Backing penutup dan hardware railing / provisional sum | 1 | ls | 0 | 3.500.000 | 0 | 3.500.000 | 3.500.000
31 | Sistem antiselip tangga Sistem antiselip permukaan tangga | 5,9999 | m2 | 0 | 125.000 | 0 | 749.989 | 749.989
32 | Clear coat kayu Clear coat kayu | 20 | L | 0 | 100.000 | 0 | 2.000.000 | 2.000.000
33 | Jasa tekuk pelat Jasa press brake | 60 | tekuk | 20.000 | 0 | 1.200.000 | 0 | 1.200.000
34 | Angkut bengkel-lokasi + bongkar Biaya pelengkap proyek | 2 | rit | 1.500.000 | 0 | 3.000.000 | 0 | 3.000.000
35 | Hoist dan alat angkat LT4 Biaya pelengkap proyek | 7 | hari | 500.000 | 0 | 3.500.000 | 0 | 3.500.000
36 | Perancah dan penyangga sementara Biaya pelengkap proyek | 1 | ls | 2.500.000 | 0 | 2.500.000 | 0 | 2.500.000
37 | Pengukuran + kontrol mutu las/cat Biaya pelengkap proyek | 1 | ls | 2.000.000 | 0 | 2.000.000 | 0 | 2.000.000
38 | Pembersihan, APD dan proteksi Biaya pelengkap proyek | 1 | ls | 1.500.000 | 0 | 1.500.000 | 0 | 1.500.000
39 | Verifikasi desain + investigasi tumpuan Biaya pelengkap proyek | 1 | ls | 7.500.000 | 0 | 7.500.000 | 0 | 7.500.000
Subtotal Biaya pelengkap | | | | | | 21.200.000 | 6.249.989 | 27.449.989
40 | Kolom tambahan infill Hollow 50x100x2,3 mm | 140,2376 | kg | 6.000 | 13.369 | 841.425 | 1.874.868 | 2.716.293
41 | Balok memanjang infill Hollow 50x100x2,3 mm | 105,6237 | kg | 6.000 | 13.369 | 633.742 | 1.412.107 | 2.045.849
42 | Pengaku silang infill Hollow 50x100x2,3 mm | 185,4528 | kg | 6.000 | 13.369 | 1.112.717 | 2.479.362 | 3.592.079
43 | Base plate infill Pelat 8 mm / 140x150 mm | 34,2175 | kg | 6.000 | 11.695 | 205.305 | 400.180 | 605.485
44 | Angkur lantai infill M12 / allowance sambungan, mutu dan penanaman belum dipilih | 84 | set | 15.000 | 35.000 | 1.260.000 | 2.940.000 | 4.200.000
45 | Karet dudukan infill Karet 140x150x3 mm / allowance | 20 | bh | 500 | 25.000 | 10.000 | 500.000 | 510.000
46 | Angkur lantai kolom utama M12 / allowance; spesifikasi dan kapasitas belum ditetapkan | 336 | set | 15.000 | 35.000 | 5.040.000 | 11.760.000 | 16.800.000
Subtotal Infill baru | | | | | | 9.103.189 | 21.366.517 | 30.469.706
47 | Rangka panel mesh SHS 40x40x2 mm | 299,0213 | kg | 6.000 | 12.987 | 1.794.128 | 3.883.290 | 5.677.418
48 | Kawat loket penutup sisi Galvanis 25x25 mm / kawat 2.0 mm | 70 | kg | 0 | 30.000 | 0 | 2.100.000 | 2.100.000
49 | Strip penjepit tepi mesh Flat bar 30x3 mm / dua sisi vertikal dan horizontal per panel | 84,78 | kg | 6.000 | 15.000 | 508.680 | 1.271.700 | 1.780.380
50 | Pengikat mesh dan rangka panel M6 galvanis + mur + ring / allowance | 1.218 | set | 1.000 | 2.500 | 1.218.000 | 3.045.000 | 4.263.000
51 | Pemasangan dan potong mesh Panel kawat loket; ujung kawat ditutup strip | 13,8739 | m2 | 35.000 | 0 | 485.585 | 0 | 485.585
Subtotal Penutup mesh | | | | | | 4.006.393 | 10.299.990 | 14.306.383
52 | Angkur tambahan struktur / tangga M12 / allowance; produk dan kapasitas belum ditetapkan | 9 | set | 15.000 | 35.000 | 135.000 | 315.000 | 450.000

No. | Pekerjaan / spesifikasi | Volume | Sat. | Upah/sat. | Material/sat. | Jumlah upah | Jumlah material | Total
53 | Bahan habis pakai sambungan las tambahan Allowance bahan las; detail prosedur dan ukuran las belum disahkan | 30 | m | 0 | 10.000 | 0 | 300.000 | 300.000
Subtotal Pekerjaan lain | | | | | | 135.000 | 615.000 | 750.000
TOTAL | | | | | | 96.855.237 | 193.477.260 | 290.332.497

## SUBTOTAL PER KOMPONEN - REKAP BIAYA YANG SAMA

Komponen | Upah | Material | Gabungan
Kolom | 5.275.039 | 11.753.870 | 17.028.909
Balok | 5.510.992 | 12.279.620 | 17.790.612
Pengaku dek dan strut | 8.611.014 | 19.187.107 | 27.798.121
Bracing | 1.404.054 | 3.128.519 | 4.532.573
Tangga dan penyangga | 3.461.969 | 7.592.640 | 11.054.609
Rail horizontal | 180.840 | 391.418 | 572.258
Tiang railing dan pegangan | 2.278.800 | 4.986.000 | 7.264.800
Pelat dek | 15.373.440 | 39.777.239 | 55.150.679
Penutup | 5.425.920 | 11.119.787 | 16.545.707
Pelat sambungan dan base plate | 3.592.839 | 8.520.712 | 12.113.551
Sambungan dan pengikat | 3.006.400 | 11.764.700 | 14.771.100
Dek, penutup dan finishing | 10.877.232 | 30.210.489 | 41.087.721
Biaya pelengkap | 21.200.000 | 6.249.989 | 27.449.989
Penutup mesh dan rangkanya | 4.006.393 | 10.299.990 | 14.306.383
Tumpuan kolom tambahan | 1.475.305 | 3.840.180 | 5.315.485
Tumpuan kolom utama | 5.040.000 | 11.760.000 | 16.800.000
Pekerjaan lain | 135.000 | 615.000 | 750.000

## SUBTOTAL KG DAN BATANG PER PROFIL

Berat pembelian dari RAB aktif; kg = batang x kg/batang.

Profil / ketebalan terpilih | Kg / batang 6 m | Batang 6 m / ekuivalen | Subtotal kg
Hollow 50x100x2,3 mm | 32,5 | 110 | 3.575
SHS 40x40x2 mm | 15,07 | 33 | 497,31
SHS 40x40x2,8 mm | 21,1 | 18 | 379,8
Flat bar 30x3 mm / dua sisi vertikal dan horizontal per panel | 4,239 | 20 | 84,78
SUBTOTAL PROFIL BATANG | | 181 | 4.536,89
PELAT / BARIS KG LAIN | - | - | 5.043,76
TOTAL SEMUA BARIS KG | - | - | 9.580,65

Lingkup R08: pola 110 batang RHS. Tebal mengikuti pilihan aktif. Stok SHS dipisahkan per profil. Pecahan setelah edit atau pada berat bersih adalah ekuivalen, bukan pesanan stok. Pelat tidak dikonversi menjadi batang. Edit manual RAB tetap ikut; subtotal ini tidak menambah biaya.

## SUBTOTAL KG DAN ALOKASI BATANG PER KOMPONEN

Komponen (baris satuan kg) | Subtotal kg | Alokasi batang profil 6 m
Kolom | 879,173 | 27,0515
Balok | 918,499 | 28,2615
Pengaku dek dan strut | 1.435,169 | 44,159
Bracing | 234,009 | 7,2003
Tangga dan penyangga | 547,595 | 14,4855
Rail horizontal | 30,14 | 2
Tiang railing dan pegangan | 379,8 | 18
Pelat dek | 3.074,688 | -
Penutup | 904,32 | -
Pelat sambungan dan base plate | 689,238 | -
Penutup mesh dan rangkanya | 453,801 | 39,8422
Tumpuan kolom tambahan | 34,218 | -
TOTAL | 9.580,65 | 181

Alokasi batang komponen boleh pecahan karena satu stok dipakai bersama; jangan bulatkan tiap komponen.

## DASAR KUANTITAS DAN CATATAN

Kode | Pekerjaan | Dasar hitungan / status
X01 | Kolom tribun | R08 A: 133.559800 m; alokasi dari 110 stok bersama x 32.5 kg/batang. Minimum belum terbukti. Panjang Revit; berat dari penampang/katalog
X02 | Balok tepi tier | R08 A: 73.710000 m; alokasi dari 110 stok bersama x 32.5 kg/batang. Minimum belum terbukti. Panjang Revit; berat dari penampang/katalog
X03 | Pengaku longitudinal dek | R08 A: 226.069001 m; alokasi dari 110 stok bersama x 32.5 kg/batang. Minimum belum terbukti. Panjang Revit; berat dari penampang/katalog
X04 | Rangka belakang | R08 A: 17.396000 m; alokasi dari 110 stok bersama x 32.5 kg/batang. Minimum belum terbukti. Panjang Revit; berat dari penampang/katalog
X05 | Strut ke kolom beton | R08 A: 0.000000 m; alokasi dari 110 stok bersama x 32.5 kg/batang. Minimum belum terbukti. Panjang Revit; berat dari penampang/katalog
X06 | Bracing X | R08 A: 42.388000 m; alokasi dari 110 stok bersama x 32.5 kg/batang. Minimum belum terbukti. Panjang Revit; berat dari penampang/katalog
B01 | Balok silang penumpu dek | R08 A: 57.005998 m; alokasi dari 110 stok bersama x 32.5 kg/batang. Minimum belum terbukti. Panjang Revit; berat dari penampang/katalog
B02 | Penyangga tangga / usulan | R08 A: 19.639757 m; alokasi dari 110 stok bersama x 32.5 kg/batang. Minimum belum terbukti. Usulan belum dimodelkan
X07 | Rail atas / elemen horizontal | 10 elemen; 8.425400 m; 2 stok x6 m. Family aktif masih M_W Shapes; volume family tidak dipakai sebagai berat hollow. Model + pembelian
X08 | Tiang railing dan pegangan | 85 elemen; 97.498388 m; 18 stok. Harga 2,8 mm mengikuti katalog R04 karena spesifikasi Excel 2 mm berbeda. Model + pembelian
X09 | Pelat dek | R08: Dek 88.913631 m2; pembelian ceil(luas x 1,10 / 2,88) lembar 4 mm. Allowance luas, bukan nesting dek. Studi koordinasi; ukur dan sahkan sebelum fabrikasi
X10 | Riser, fascia dan return | R08: 286 potongan pelat depan/sisi infill; 20 lembar 2 mm 1200x2400 dari nesting. Studi koordinasi; ukur dan sahkan sebelum fabrikasi
X11 | Pelat tekuk tangga | R08: 30 tapak tekuk; 4 lembar 3 mm dari blank konservatif. Uji kupon tekuk diperlukan. Studi koordinasi; ukur dan sahkan sebelum fabrikasi
B03 | Pengaku tapak tangga / usulan | R08: 65.999868 m; alokasi pola 31 batang SHS bersama untuk tangga + panel. Railing lama tetap kelompok terpisah. Usulan belum dimodelkan
X13 | Base plate | R08 A: Base lama dan tambahan dinesting bersama; alokasi kg pembelian menurut luas. Studi koordinasi; ukur dan sahkan sebelum fabrikasi
X14 | Pelat sambungan rangka, tangga dan buhul | R08 A: Pelat ujung 90x120x6 mm dan buhul dinesting ulang. Ukuran allowance; tebal/las/baut dan penyaluran gaya belum disahkan. Studi koordinasi; ukur dan sahkan sebelum fabrikasi
X15 | Baut rangka dan X | R08 A: 2 baut per ujung tambahan; ujung batang yang dihapus dikurangi; 5% cadangan, 2 ring per baut beli. Studi koordinasi; ukur dan sahkan sebelum fabrikasi
X17 | Mur rangka dan X | R08 A: 2 baut per ujung tambahan; ujung batang yang dihapus dikurangi; 5% cadangan, 2 ring per baut beli. Studi koordinasi; ukur dan sahkan sebelum fabrikasi
X18 | Ring rangka dan X | R08 A: 2 baut per ujung tambahan; ujung batang yang dihapus dikurangi; 5% cadangan, 2 ring per baut beli. Studi koordinasi; ukur dan sahkan sebelum fabrikasi
B04 | Baut tangga | R08 A: Ujung penyangga yang diganti sambungan las dikurangi dari baut; 5% cadangan, dua ring per baut beli. Studi koordinasi; ukur dan sahkan sebelum fabrikasi
B05 | Mur tangga | R08 A: Ujung penyangga yang diganti sambungan las dikurangi dari baut; 5% cadangan, dua ring per baut beli. Studi koordinasi; ukur dan sahkan sebelum fabrikasi
B06 | Ring tangga | R08 A: Ujung penyangga yang diganti sambungan las dikurangi dari baut; 5% cadangan, dua ring per baut beli. Studi koordinasi; ukur dan sahkan sebelum fabrikasi
X16 | Ikatan ke kolom beton / cadangan | R08 A: Cadangan ikatan RC lama diganti daftar usulan A/C di bawah; kapasitas belum disahkan. Studi koordinasi; ukur dan sahkan sebelum fabrikasi

Kode | Pekerjaan | Dasar hitungan / status
X19 | Sekrup kayu ke baja + ring | R08: 500 set lama + 8 set per 5 tingkat infill; pola pengikat kayu harus dirinci. Studi koordinasi; ukur dan sahkan sebelum fabrikasi
X20 | Sekrup penutup + ring EPDM | R08: Keliling panel pelat / jarak maksimum 200 mm, cadangan 5%; pengikat mesh dihitung terpisah. Studi koordinasi; ukur dan sahkan sebelum fabrikasi
X21 | Karet dudukan | 80 dudukan aktif; satu karet per base plate. Model + pembelian
X22 | Papan pinus dudukan | R08: Papan baru setara 6.710599 m x 400x40 mm setelah takikan RC; allowance potong 10%. Studi koordinasi; ukur dan sahkan sebelum fabrikasi
X23 | Panel kayu sandaran | Luas 7,29 m² dari geometri arsip, bukan hasil ukur Revit baru. Pembelian+10%. Koreksi label 400x40 cm menjadi lebar 400 mm/tebal 40 mm. Geometri arsip / allowance
X24 | Cat dan coating baja | R08 A: Luas cat disesuaikan potongan RHS dan pelat baru/dihapus; kedua muka pelat +10%. Studi koordinasi; ukur dan sahkan sebelum fabrikasi
E01 | Backing riser depan dan hardware railing | R08: cadangan Rp3.500.000 untuk backing pelat depan, ujung railing dan penghubung yang belum terukur. Tidak mencakup rangka/penjepit mesh yang sudah dirinci pada M02-M04. Allowance anggaran
E02 | Sistem antiselip tangga | R08: Antiselip sesuai luas tapak tersisa; bukan bidang infill dudukan. Studi koordinasi; ukur dan sahkan sebelum fabrikasi
E03 | Clear coat kayu | R08: Cadangan clear coat 20 L untuk kayu lama + infill; konsumsi aktual mengikuti produk/uji lapangan. Studi koordinasi; ukur dan sahkan sebelum fabrikasi
E04 | Jasa tekuk pelat | R08: Dua tekukan per tapak; takikan RC dan kupon dibahas bengkel. Studi koordinasi; ukur dan sahkan sebelum fabrikasi
EL01 | Angkut bengkel-lokasi + bongkar | Bukan ongkir toko-bengkel; ukuran truk/jam akses diverifikasi. Allowance anggaran
EL02 | Hoist dan alat angkat LT4 | Allowance 7 hari, kapasitas/jalur angkat ditentukan metode kerja. Allowance anggaran
EL03 | Perancah dan penyangga sementara | Sewa, pengiriman dan pembongkaran. Allowance anggaran
EL04 | Pengukuran + kontrol mutu las/cat | Allowance ukur, inspeksi visual, DFT dan dokumentasi. Tidak termasuk uji beton laboratorium. Allowance anggaran
EL05 | Pembersihan, APD dan proteksi | Area LT4, alat keselamatan kerja dan serah terima. Allowance anggaran
EL06 | Verifikasi desain + investigasi tumpuan | Provisional sum pemeriksaan insinyur dan pengumpulan data beton; lingkup lab mengikuti temuan. Allowance anggaran
I01 | Kolom tambahan infill | R08 A: 25.700000 m; alokasi dari 110 stok bersama x 32.5 kg/batang. Minimum belum terbukti. R08: rangka infill usulan, belum elemen Revit
I02 | Balok memanjang infill | R08 A: 18.516698 m; alokasi dari 110 stok bersama x 32.5 kg/batang. Minimum belum terbukti. R08: rangka infill usulan, belum elemen Revit
I03 | Pengaku silang infill | R08 A: 33.600907 m; alokasi dari 110 stok bersama x 32.5 kg/batang. Minimum belum terbukti. R08: rangka infill usulan, belum elemen Revit
M02 | Rangka panel mesh | R08: 114.502857 m; alokasi pola 31 batang SHS bersama untuk tangga + panel. Railing lama tetap kelompok terpisah. Usulan belum dimodelkan
I04 | Base plate infill | R08 A: 20 base usulan 140x150x8 mm; dimensi/kapasitas belum disahkan. Usulan; tarif allowance bila dinyatakan
I05 | Angkur lantai infill | R08 A: 4 angkur lantai per base usulan + cadangan 5%; tumpuan lantai belum diverifikasi. Usulan; tarif allowance bila dinyatakan
I06 | Karet dudukan infill | R08 A: Karet 140x150x3 mm per base baru. Usulan; tarif allowance bila dinyatakan
I07 | Angkur lantai kolom utama | R08: 80 base kolom utama x 4 angkur + 5%. Baut M12x40 rangka bukan angkur beton. Cadangan ini melengkapi jalur tumpuan FEM; kekakuan base, karet 10 mm, lantai, mutu beton dan produk angkur harus diverifikasi. Usulan; tarif allowance bila dinyatakan
M01 | Kawat loket penutup sisi | R08: 1 roll 1.2x30 m x 70 kg. Luas mesh bersih 13.8739 m2. Harga allowance Rp30.000/kg, wajib diganti penawaran. https://www.pabrikbrc.net/2019/07/jual-wire-mesh-kawat-loket-merk-givro.html Usulan; tarif allowance bila dinyatakan

Kode | Pekerjaan | Dasar hitungan / status
M03 | Strip penjepit tepi mesh | R08: 240 potongan / 20 batang 6 m. Berat teoritis 4,239 kg/batang, tarif material allowance Rp15.000/kg. Usulan; tarif allowance bila dinyatakan
M04 | Pengikat mesh dan rangka panel | R08: Penjepit maksimum 200 mm + 4 pengikat panel per rangka. Jarak/kapasitas belum disahkan. Harga material allowance Rp2.500/set. Usulan; tarif allowance bila dinyatakan
M05 | Pemasangan dan potong mesh | R08: Allowance upah Rp35.000/m2; terpisah dari upah rangka, strip dan pengikat. Usulan; tarif allowance bila dinyatakan
S01 | Angkur tambahan struktur / tangga | R08 A: Jumlah dari jadwal titik usulan; cadangan 5%. Tarif material Rp35.000 + upah Rp15.000/set. Beton, jarak tepi, kedalaman dan produk harus diperiksa. Allowance studi; bukan desain fabrikasi
S02 | Bahan habis pakai sambungan las tambahan | R08 A: 50 penghubung pendek x dua keliling profil 0,30 m. Cadangan material Rp10.000/m; upah telah termasuk tarif RHS per kg. Ini panjang jalur nominal untuk biaya, bukan ukuran atau kapasitas las. Allowance studi; bukan desain fabrikasi

Opsi A - tangga terikat rangka utama dan beton.
Studi jalur beban lengkap dua tangga; sambungan kaku, las dan angkur belum dibuktikan kapasitasnya.
60 girder sisi B02 sudah berada dalam RAB dasar; tidak dibeli dua kali. Ditambah40penghubung vertikal antar tingkat tapak menjadi girder bertangga.
Delapan pengikat RC lama dihapus. Profil RHS tetap mengikuti tebal terpilih.
Beban seluruh30tapak diteruskan ke girder sisi sesuai keseimbangan transversal. SHS B03 dan pelat diperiksa terpisah; tidak diasumsikan menambah kekakuan global.
10cleatRHS45mm menghubungkan sisi dalam tangga kiri ke rangka infill. Duaheader700mm pada landing tengah ditambatkan ke muka beton; ujung lain mengandalkan sambungan ke baja utama.
R08 koreksi sketsa: strip x5450–6850 mm pada zona kiri 2 m menjadi dek dan dudukan selebar sekitar 1400 mm. Tangga kanan yang ditandai dihapus; tersisa dua jalur nominal 600 mm pada dua zona. Jumlah jalur bukan pengesahan kapasitas evakuasi. Lebar 600 mm belum dikurangi pegangan/finishing. Kapasitas evakuasi dan aksesibilitas belum lulus pemeriksaan. Tambahan kursi hanya studi modul 500 mm, bukan kapasitas operasi yang disahkan.
Rangka infill baru 20 kolom, balok, pengaku, base plate, karet dan angkur adalah usulan. RC ditakik dengan celah 3 mm. Tumpuan lantai, lendutan, stabilitas, las/baut dan akses pemasangan belum disahkan.
Mesh hanya penutup luar kanan/kiri. Riser depan tetap pelat. Mesh bukan pengganti railing, penahan kerumunan atau bracing; rangka panel dan penjepit tepi dihitung.
Harga mesh Rp30.000/kg, strip Rp15.000/kg, M6 Rp2.500/set, angkur Rp35.000/set dan upah baru adalah allowance perencanaan, bukan penawaran pemasok. Total RAB adalah estimasi dengan allowance.
Berat beli RHS/SHS mengikuti katalog dan varian tebal. Potongan digabung sesuai kelompok stok. Railing SHS tetap 2+18 batang terpisah. Batang layak dari nesting, minimum belum terbukti. Dek memakai allowance luas 10%, bukan pola potong final. Sambungan baru memerlukan pengesahan: pelat 90×120×6, base 140×150×8, M12, 4 angkur/kolom dan posisi kolom hanyalah dasar hitung biaya. Jangan bor lantai atau mulai fabrikasi dari paket ini.
Tahapan: ukur kondisi/akses dan lantai; sahkan struktur/evakuasi serta shop drawing; minta penawaran; kunci daftar potong; mock-up tekuk/mesh; fabrikasi dan QC; pasang dengan penyangga sementara; inspeksi dan serah terima. Dokumen R07 menjadi acuan proses umum, bukan gambar R08.
Sebelum overhead, laba dan pajak tambahan.
Surabaya, 2026-09-15 / ADIGHANI ILHAM

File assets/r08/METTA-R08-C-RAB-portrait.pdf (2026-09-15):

# SAP / SELARAS ADHI PERKASA

## RENCANA ANGGARAN BIAYA - METTA

R08 - Infill sesuai gambar + mesh sisi / Hollow 2,3 mm / model / SHS acuan 2,0 / 2,8 mm / C / rangka mandiri / Mesh 25x25 / 2,0 mm
| 2026-09-15 | Pembelian | Dengan biaya pelengkap

STUDI OPTIMASI. BELUM UNTUK FABRIKASI.

No. | Pekerjaan / spesifikasi | Volume | Sat. | Upah/sat. | Material/sat. | Jumlah upah | Jumlah material | Total
1 | Kolom tribun Hollow 50x100x2,3 mm | 737,4883 | kg | 6.000 | 13.369 | 4.424.930 | 9.859.651 | 14.284.581
2 | Balok tepi tier Hollow 50x100x2,3 mm | 404,9201 | kg | 6.000 | 13.369 | 2.429.520 | 5.413.470 | 7.842.990
3 | Pengaku longitudinal dek Hollow 50x100x2,3 mm | 1.246,1805 | kg | 6.000 | 13.369 | 7.477.083 | 16.660.475 | 24.137.558
4 | Rangka belakang Hollow 50x100x2,3 mm | 94,6044 | kg | 6.000 | 13.369 | 567.627 | 1.264.788 | 1.832.415
5 | Strut ke kolom beton Hollow 50x100x2,3 mm | 0 | kg | 6.000 | 13.369 | 0 | 0 | 0
6 | Bracing X Hollow 50x100x2,3 mm | 493,462 | kg | 6.000 | 13.369 | 2.960.772 | 6.597.207 | 9.557.979
7 | Balok silang penumpu dek Hollow 50x100x2,3 mm | 315,0199 | kg | 6.000 | 13.369 | 1.890.119 | 4.211.574 | 6.101.693
Subtotal Rangka utama | | | | | | 19.750.051 | 44.007.165 | 63.757.216
8 | Penyangga tangga / usulan Hollow 50x100x2,3 mm | 108,4085 | kg | 6.000 | 13.369 | 650.451 | 1.449.338 | 2.099.789
9 | Pelat tekuk tangga Pelat polos 3 mm | 271,296 | kg | 6.000 | 12.286 | 1.627.776 | 3.333.065 | 4.960.841
10 | Pengaku tapak tangga / usulan SHS 40x40x2 mm | 168,1487 | kg | 6.000 | 12.987 | 1.008.892 | 2.183.691 | 3.192.583
11 | Baut tangga M12x40 kelas 8.8 | 84 | bh | 1.000 | 4.500 | 84.000 | 378.000 | 462.000
12 | Mur tangga M12 kelas 8 | 84 | bh | 1.000 | 1.500 | 84.000 | 126.000 | 210.000
13 | Ring tangga Ring datar keras M12 | 168 | bh | 50 | 750 | 8.400 | 126.000 | 134.400
Subtotal Tangga | | | | | | 3.463.519 | 7.596.094 | 11.059.613
14 | Rail atas / elemen horizontal SHS 40x40x2 mm | 30,14 | kg | 6.000 | 12.987 | 180.840 | 391.418 | 572.258
15 | Tiang railing dan pegangan SHS 40x40x2,8 mm | 379,8 | kg | 6.000 | 13.128 | 2.278.800 | 4.986.000 | 7.264.800
Subtotal Railing | | | | | | 2.459.640 | 5.377.418 | 7.837.058
16 | Pelat dek Bordes 4 mm | 3.074,688 | kg | 5.000 | 12.937 | 15.373.440 | 39.777.239 | 55.150.679
17 | Riser, fascia dan return Pelat polos 2 mm | 904,32 | kg | 6.000 | 12.296 | 5.425.920 | 11.119.787 | 16.545.707
18 | Papan pinus dudukan Lebar 400 mm; tebal 40 mm | 89,6765 | m | 25.000 | 90.000 | 2.241.913 | 8.070.887 | 10.312.800
19 | Panel kayu sandaran Lebar 400 mm; tebal 40 mm | 20,0475 | m | 25.000 | 90.000 | 501.188 | 1.804.275 | 2.305.463
20 | Cat dan coating baja Persiapan + cat; luas permukaan | 662,4419 | m² | 13.183 | 32.956 | 8.732.656 | 21.831.641 | 30.564.297
Subtotal Dek, penutup dan finishing | | | | | | 32.275.117 | 82.603.829 | 114.878.946
21 | Base plate Pelat 150x150x8 mm | 212,7812 | kg | 6.000 | 11.695 | 1.276.687 | 2.488.516 | 3.765.203
22 | Pelat sambungan rangka, tangga dan buhul Pelat 6 mm; lembar 120x240 cm | 678,24 | kg | 5.000 | 12.543 | 3.391.200 | 8.507.067 | 11.898.267
23 | Baut rangka dan X M12x40 kelas 8.8 | 1.105 | bh | 1.000 | 4.500 | 1.105.000 | 4.972.500 | 6.077.500
24 | Mur rangka dan X M12 kelas 8 | 1.105 | bh | 1.000 | 1.500 | 1.105.000 | 1.657.500 | 2.762.500
25 | Ring rangka dan X Ring datar keras M12 | 2.210 | bh | 50 | 750 | 110.500 | 1.657.500 | 1.768.000
26 | Ikatan ke kolom beton / cadangan Angkur dan pelat: belum ditetapkan | 0 | ls | 0 | 2.500.000 | 0 | 0 | 0
METTA / Hollow 2,3 mm / model | 1 / 9

No. | Pekerjaan / spesifikasi | Volume | Sat. | Upah/sat. | Material/sat. | Jumlah upah | Jumlah material | Total
27 | Sekrup kayu ke baja + ring #12x65 / usulan | 540 | set | 300 | 1.500 | 162.000 | 810.000 | 972.000
28 | Sekrup penutup + ring EPDM #12x32 / usulan | 3.909 | set | 300 | 800 | 1.172.700 | 3.127.200 | 4.299.900
29 | Karet dudukan 150x150x10 mm | 80 | bh | 500 | 25.000 | 40.000 | 2.000.000 | 2.040.000
Subtotal Sambungan dan pengikat | | | | | | 8.363.087 | 25.220.283 | 33.583.370
30 | Backing riser depan dan hardware railing Backing penutup dan hardware railing / provisional sum | 1 | ls | 0 | 3.500.000 | 0 | 3.500.000 | 3.500.000
31 | Sistem antiselip tangga Sistem antiselip permukaan tangga | 5,9999 | m2 | 0 | 125.000 | 0 | 749.989 | 749.989
32 | Clear coat kayu Clear coat kayu | 20 | L | 0 | 100.000 | 0 | 2.000.000 | 2.000.000
33 | Jasa tekuk pelat Jasa press brake | 60 | tekuk | 20.000 | 0 | 1.200.000 | 0 | 1.200.000
34 | Angkut bengkel-lokasi + bongkar Biaya pelengkap proyek | 2 | rit | 1.500.000 | 0 | 3.000.000 | 0 | 3.000.000
35 | Hoist dan alat angkat LT4 Biaya pelengkap proyek | 7 | hari | 500.000 | 0 | 3.500.000 | 0 | 3.500.000
36 | Perancah dan penyangga sementara Biaya pelengkap proyek | 1 | ls | 2.500.000 | 0 | 2.500.000 | 0 | 2.500.000
37 | Pengukuran + kontrol mutu las/cat Biaya pelengkap proyek | 1 | ls | 2.000.000 | 0 | 2.000.000 | 0 | 2.000.000
38 | Pembersihan, APD dan proteksi Biaya pelengkap proyek | 1 | ls | 1.500.000 | 0 | 1.500.000 | 0 | 1.500.000
39 | Verifikasi desain + investigasi tumpuan Biaya pelengkap proyek | 1 | ls | 7.500.000 | 0 | 7.500.000 | 0 | 7.500.000
Subtotal Biaya pelengkap | | | | | | 21.200.000 | 6.249.989 | 27.449.989
40 | Kolom tambahan infill dan penguatan Hollow 50x100x2,3 mm | 391,799 | kg | 6.000 | 13.369 | 2.350.794 | 5.238.051 | 7.588.845
41 | Balok memanjang infill Hollow 50x100x2,3 mm | 216,5553 | kg | 6.000 | 13.369 | 1.299.332 | 2.895.178 | 4.194.510
42 | Pengaku silang infill Hollow 50x100x2,3 mm | 184,0621 | kg | 6.000 | 13.369 | 1.104.372 | 2.460.768 | 3.565.140
43 | Base plate kolom tambahan infill dan tangga Pelat 8 mm / 140x150 mm | 148,9468 | kg | 6.000 | 11.695 | 893.681 | 1.741.961 | 2.635.642
44 | Angkur lantai kolom tambahan infill dan tangga M12 / allowance sambungan, mutu dan penanaman belum dipilih | 252 | set | 15.000 | 35.000 | 3.780.000 | 8.820.000 | 12.600.000
45 | Karet dudukan kolom tambahan infill dan tangga Karet 140x150x3 mm / allowance | 60 | bh | 500 | 25.000 | 30.000 | 1.500.000 | 1.530.000
46 | Angkur lantai kolom utama M12 / allowance; spesifikasi dan kapasitas belum ditetapkan | 336 | set | 15.000 | 35.000 | 5.040.000 | 11.760.000 | 16.800.000
Subtotal Infill baru | | | | | | 14.498.179 | 34.415.958 | 48.914.137
47 | Rangka panel mesh SHS 40x40x2 mm | 299,0213 | kg | 6.000 | 12.987 | 1.794.128 | 3.883.290 | 5.677.418
48 | Kawat loket penutup sisi Galvanis 25x25 mm / kawat 2.0 mm | 70 | kg | 0 | 30.000 | 0 | 2.100.000 | 2.100.000
49 | Strip penjepit tepi mesh Flat bar 30x3 mm / dua sisi vertikal dan horizontal per panel | 84,78 | kg | 6.000 | 15.000 | 508.680 | 1.271.700 | 1.780.380
50 | Pengikat mesh dan rangka panel M6 galvanis + mur + ring / allowance | 1.218 | set | 1.000 | 2.500 | 1.218.000 | 3.045.000 | 4.263.000
51 | Pemasangan dan potong mesh Panel kawat loket; ujung kawat ditutup strip | 13,8739 | m2 | 35.000 | 0 | 485.585 | 0 | 485.585
Subtotal Penutup mesh | | | | | | 4.006.393 | 10.299.990 | 14.306.383

No. | Pekerjaan / spesifikasi | Volume | Sat. | Upah/sat. | Material/sat. | Jumlah upah | Jumlah material | Total
52 | Bahan habis pakai sambungan las tambahan Allowance bahan las; detail prosedur dan ukuran las belum disahkan | 28,8 | m | 0 | 10.000 | 0 | 288.000 | 288.000
Subtotal Pekerjaan lain | | | | | | 0 | 288.000 | 288.000
TOTAL | | | | | | 106.015.986 | 216.058.726 | 322.074.712

## SUBTOTAL PER KOMPONEN - REKAP BIAYA YANG SAMA

Komponen | Upah | Material | Gabungan
Kolom | 6.775.724 | 15.097.702 | 21.873.426
Balok | 6.186.598 | 13.785.010 | 19.971.608
Pengaku dek dan strut | 8.581.455 | 19.121.243 | 27.702.698
Bracing | 2.960.772 | 6.597.207 | 9.557.979
Tangga dan penyangga | 3.463.519 | 7.596.094 | 11.059.613
Rail horizontal | 180.840 | 391.418 | 572.258
Tiang railing dan pegangan | 2.278.800 | 4.986.000 | 7.264.800
Pelat dek | 15.373.440 | 39.777.239 | 55.150.679
Penutup | 5.425.920 | 11.119.787 | 16.545.707
Pelat sambungan dan base plate | 4.667.887 | 10.995.583 | 15.663.470
Sambungan dan pengikat | 3.695.200 | 14.224.700 | 17.919.900
Dek, penutup dan finishing | 11.475.757 | 31.706.803 | 43.182.560
Biaya pelengkap | 21.200.000 | 6.249.989 | 27.449.989
Penutup mesh dan rangkanya | 4.006.393 | 10.299.990 | 14.306.383
Tumpuan kolom tambahan | 4.703.681 | 12.061.961 | 16.765.642
Tumpuan kolom utama | 5.040.000 | 11.760.000 | 16.800.000
Pekerjaan lain | 0 | 288.000 | 288.000

## SUBTOTAL KG DAN BATANG PER PROFIL

Berat pembelian dari RAB aktif; kg = batang x kg/batang.

Profil / ketebalan terpilih | Kg / batang 6 m | Batang 6 m / ekuivalen | Subtotal kg
Hollow 50x100x2,3 mm | 32,5 | 129 | 4.192,5
SHS 40x40x2 mm | 15,07 | 33 | 497,31
SHS 40x40x2,8 mm | 21,1 | 18 | 379,8
Flat bar 30x3 mm / dua sisi vertikal dan horizontal per panel | 4,239 | 20 | 84,78
SUBTOTAL PROFIL BATANG | | 200 | 5.154,39
PELAT / BARIS KG LAIN | - | - | 5.360,272
TOTAL SEMUA BARIS KG | - | - | 10.514,662

Lingkup R08: pola 129 batang RHS. Tebal mengikuti pilihan aktif. Stok SHS dipisahkan per profil. Pecahan setelah edit atau pada berat bersih adalah ekuivalen, bukan pesanan stok. Pelat tidak dikonversi menjadi batang. Edit manual RAB tetap ikut; subtotal ini tidak menambah biaya.

## SUBTOTAL KG DAN ALOKASI BATANG PER KOMPONEN

Komponen (baris satuan kg) | Subtotal kg | Alokasi batang profil 6 m
Kolom | 1.129,287 | 34,7473
Balok | 1.031,1 | 31,7261
Pengaku dek dan strut | 1.430,243 | 44,0075
Bracing | 493,462 | 15,1834
Tangga dan penyangga | 547,853 | 14,4935
Rail horizontal | 30,14 | 2
Tiang railing dan pegangan | 379,8 | 18
Pelat dek | 3.074,688 | -
Penutup | 904,32 | -
Pelat sambungan dan base plate | 891,021 | -
Penutup mesh dan rangkanya | 453,801 | 39,8422
Tumpuan kolom tambahan | 148,947 | -
TOTAL | 10.514,662 | 200

Alokasi batang komponen boleh pecahan karena satu stok dipakai bersama; jangan bulatkan tiap komponen.

## DASAR KUANTITAS DAN CATATAN

Kode | Pekerjaan | Dasar hitungan / status
X01 | Kolom tribun | R08 C: 133.559800 m; alokasi dari 129 stok bersama x 32.5 kg/batang. Minimum belum terbukti. Panjang Revit; berat dari penampang/katalog
X02 | Balok tepi tier | R08 C: 73.710000 m; alokasi dari 129 stok bersama x 32.5 kg/batang. Minimum belum terbukti. Panjang Revit; berat dari penampang/katalog
X03 | Pengaku longitudinal dek | R08 C: 226.069001 m; alokasi dari 129 stok bersama x 32.5 kg/batang. Minimum belum terbukti. Panjang Revit; berat dari penampang/katalog
X04 | Rangka belakang | R08 C: 17.396000 m; alokasi dari 129 stok bersama x 32.5 kg/batang. Minimum belum terbukti. Panjang Revit; berat dari penampang/katalog
X05 | Strut ke kolom beton | R08 C: 0.000000 m; alokasi dari 129 stok bersama x 32.5 kg/batang. Minimum belum terbukti. Panjang Revit; berat dari penampang/katalog
X06 | Bracing X | R08 C: 89.722767 m; alokasi dari 129 stok bersama x 32.5 kg/batang. Minimum belum terbukti. Panjang Revit; berat dari penampang/katalog
B01 | Balok silang penumpu dek | R08 C: 57.005998 m; alokasi dari 129 stok bersama x 32.5 kg/batang. Minimum belum terbukti. Panjang Revit; berat dari penampang/katalog
B02 | Penyangga tangga / usulan | R08 C: 19.639757 m; alokasi dari 129 stok bersama x 32.5 kg/batang. Minimum belum terbukti. Usulan belum dimodelkan
X07 | Rail atas / elemen horizontal | 10 elemen; 8.425400 m; 2 stok x6 m. Family aktif masih M_W Shapes; volume family tidak dipakai sebagai berat hollow. Model + pembelian
X08 | Tiang railing dan pegangan | 85 elemen; 97.498388 m; 18 stok. Harga 2,8 mm mengikuti katalog R04 karena spesifikasi Excel 2 mm berbeda. Model + pembelian
X09 | Pelat dek | R08: Dek 88.913631 m2; pembelian ceil(luas x 1,10 / 2,88) lembar 4 mm. Allowance luas, bukan nesting dek. Studi koordinasi; ukur dan sahkan sebelum fabrikasi
X10 | Riser, fascia dan return | R08: 286 potongan pelat depan/sisi infill; 20 lembar 2 mm 1200x2400 dari nesting. Studi koordinasi; ukur dan sahkan sebelum fabrikasi
X11 | Pelat tekuk tangga | R08: 30 tapak tekuk; 4 lembar 3 mm dari blank konservatif. Uji kupon tekuk diperlukan. Studi koordinasi; ukur dan sahkan sebelum fabrikasi
B03 | Pengaku tapak tangga / usulan | R08: 65.999868 m; alokasi pola 31 batang SHS bersama untuk tangga + panel. Railing lama tetap kelompok terpisah. Usulan belum dimodelkan
X13 | Base plate | R08 C: Base lama dan tambahan dinesting bersama; alokasi kg pembelian menurut luas. Studi koordinasi; ukur dan sahkan sebelum fabrikasi
X14 | Pelat sambungan rangka, tangga dan buhul | R08 C: Pelat ujung 90x120x6 mm dan buhul dinesting ulang. Ukuran allowance; tebal/las/baut dan penyaluran gaya belum disahkan. Studi koordinasi; ukur dan sahkan sebelum fabrikasi
X15 | Baut rangka dan X | R08 C: 2 baut per ujung tambahan; ujung batang yang dihapus dikurangi; 5% cadangan, 2 ring per baut beli. Studi koordinasi; ukur dan sahkan sebelum fabrikasi
X17 | Mur rangka dan X | R08 C: 2 baut per ujung tambahan; ujung batang yang dihapus dikurangi; 5% cadangan, 2 ring per baut beli. Studi koordinasi; ukur dan sahkan sebelum fabrikasi
X18 | Ring rangka dan X | R08 C: 2 baut per ujung tambahan; ujung batang yang dihapus dikurangi; 5% cadangan, 2 ring per baut beli. Studi koordinasi; ukur dan sahkan sebelum fabrikasi
B04 | Baut tangga | R08 C: Ujung penyangga yang diganti sambungan las dikurangi dari baut; 5% cadangan, dua ring per baut beli. Studi koordinasi; ukur dan sahkan sebelum fabrikasi
B05 | Mur tangga | R08 C: Ujung penyangga yang diganti sambungan las dikurangi dari baut; 5% cadangan, dua ring per baut beli. Studi koordinasi; ukur dan sahkan sebelum fabrikasi
B06 | Ring tangga | R08 C: Ujung penyangga yang diganti sambungan las dikurangi dari baut; 5% cadangan, dua ring per baut beli. Studi koordinasi; ukur dan sahkan sebelum fabrikasi
X16 | Ikatan ke kolom beton / cadangan | R08 C: Cadangan ikatan RC lama diganti daftar usulan A/C di bawah; kapasitas belum disahkan. Studi koordinasi; ukur dan sahkan sebelum fabrikasi

Kode | Pekerjaan | Dasar hitungan / status
X19 | Sekrup kayu ke baja + ring | R08: 500 set lama + 8 set per 5 tingkat infill; pola pengikat kayu harus dirinci. Studi koordinasi; ukur dan sahkan sebelum fabrikasi
X20 | Sekrup penutup + ring EPDM | R08: Keliling panel pelat / jarak maksimum 200 mm, cadangan 5%; pengikat mesh dihitung terpisah. Studi koordinasi; ukur dan sahkan sebelum fabrikasi
X21 | Karet dudukan | 80 dudukan aktif; satu karet per base plate. Model + pembelian
X22 | Papan pinus dudukan | R08: Papan baru setara 6.710599 m x 400x40 mm setelah takikan RC; allowance potong 10%. Studi koordinasi; ukur dan sahkan sebelum fabrikasi
X23 | Panel kayu sandaran | Luas 7,29 m² dari geometri arsip, bukan hasil ukur Revit baru. Pembelian+10%. Koreksi label 400x40 cm menjadi lebar 400 mm/tebal 40 mm. Geometri arsip / allowance
X24 | Cat dan coating baja | R08 C: Luas cat disesuaikan potongan RHS dan pelat baru/dihapus; kedua muka pelat +10%. Studi koordinasi; ukur dan sahkan sebelum fabrikasi
E01 | Backing riser depan dan hardware railing | R08: cadangan Rp3.500.000 untuk backing pelat depan, ujung railing dan penghubung yang belum terukur. Tidak mencakup rangka/penjepit mesh yang sudah dirinci pada M02-M04. Allowance anggaran
E02 | Sistem antiselip tangga | R08: Antiselip sesuai luas tapak tersisa; bukan bidang infill dudukan. Studi koordinasi; ukur dan sahkan sebelum fabrikasi
E03 | Clear coat kayu | R08: Cadangan clear coat 20 L untuk kayu lama + infill; konsumsi aktual mengikuti produk/uji lapangan. Studi koordinasi; ukur dan sahkan sebelum fabrikasi
E04 | Jasa tekuk pelat | R08: Dua tekukan per tapak; takikan RC dan kupon dibahas bengkel. Studi koordinasi; ukur dan sahkan sebelum fabrikasi
EL01 | Angkut bengkel-lokasi + bongkar | Bukan ongkir toko-bengkel; ukuran truk/jam akses diverifikasi. Allowance anggaran
EL02 | Hoist dan alat angkat LT4 | Allowance 7 hari, kapasitas/jalur angkat ditentukan metode kerja. Allowance anggaran
EL03 | Perancah dan penyangga sementara | Sewa, pengiriman dan pembongkaran. Allowance anggaran
EL04 | Pengukuran + kontrol mutu las/cat | Allowance ukur, inspeksi visual, DFT dan dokumentasi. Tidak termasuk uji beton laboratorium. Allowance anggaran
EL05 | Pembersihan, APD dan proteksi | Area LT4, alat keselamatan kerja dan serah terima. Allowance anggaran
EL06 | Verifikasi desain + investigasi tumpuan | Provisional sum pemeriksaan insinyur dan pengumpulan data beton; lingkup lab mengikuti temuan. Allowance anggaran
I01 | Kolom tambahan infill dan penguatan | R08 C: 71.540000 m; alokasi dari 129 stok bersama x 32.5 kg/batang. Minimum belum terbukti. R08: rangka infill usulan, belum elemen Revit
I02 | Balok memanjang infill | R08 C: 35.006660 m; alokasi dari 129 stok bersama x 32.5 kg/batang. Minimum belum terbukti. R08: rangka infill usulan, belum elemen Revit
I03 | Pengaku silang infill | R08 C: 33.600907 m; alokasi dari 129 stok bersama x 32.5 kg/batang. Minimum belum terbukti. R08: rangka infill usulan, belum elemen Revit
M02 | Rangka panel mesh | R08: 114.502857 m; alokasi pola 31 batang SHS bersama untuk tangga + panel. Railing lama tetap kelompok terpisah. Usulan belum dimodelkan
I04 | Base plate kolom tambahan infill dan tangga | R08 C: 60 base usulan 140x150x8 mm; dimensi/kapasitas belum disahkan. Usulan; tarif allowance bila dinyatakan
I05 | Angkur lantai kolom tambahan infill dan tangga | R08 C: 4 angkur lantai per base usulan + cadangan 5%; tumpuan lantai belum diverifikasi. Usulan; tarif allowance bila dinyatakan
I06 | Karet dudukan kolom tambahan infill dan tangga | R08 C: Karet 140x150x3 mm per base baru. Usulan; tarif allowance bila dinyatakan
I07 | Angkur lantai kolom utama | R08: 80 base kolom utama x 4 angkur + 5%. Baut M12x40 rangka bukan angkur beton. Cadangan ini melengkapi jalur tumpuan FEM; kekakuan base, karet 10 mm, lantai, mutu beton dan produk angkur harus diverifikasi. Usulan; tarif allowance bila dinyatakan
M01 | Kawat loket penutup sisi | R08: 1 roll 1.2x30 m x 70 kg. Luas mesh bersih 13.8739 m2. Harga allowance Rp30.000/kg, wajib diganti penawaran. https://www.pabrikbrc.net/2019/07/jual-wire-mesh-kawat-loket-merk-givro.html Usulan; tarif allowance bila dinyatakan

Kode | Pekerjaan | Dasar hitungan / status
M03 | Strip penjepit tepi mesh | R08: 240 potongan / 20 batang 6 m. Berat teoritis 4,239 kg/batang, tarif material allowance Rp15.000/kg. Usulan; tarif allowance bila dinyatakan
M04 | Pengikat mesh dan rangka panel | R08: Penjepit maksimum 200 mm + 4 pengikat panel per rangka. Jarak/kapasitas belum disahkan. Harga material allowance Rp2.500/set. Usulan; tarif allowance bila dinyatakan
M05 | Pemasangan dan potong mesh | R08: Allowance upah Rp35.000/m2; terpisah dari upah rangka, strip dan pengikat. Usulan; tarif allowance bila dinyatakan
S02 | Bahan habis pakai sambungan las tambahan | R08 C: 48 penghubung pendek x dua keliling profil 0,30 m. Cadangan material Rp10.000/m; upah telah termasuk tarif RHS per kg. Ini panjang jalur nominal untuk biaya, bukan ukuran atau kapasitas las. Allowance studi; bukan desain fabrikasi

Opsi C - tangga dengan rangka kaki dan pengaku.
Studi jalur beban lengkap dua tangga; sambungan kaku, las dan angkur belum dibuktikan kapasitasnya.
60 girder sisi B02 sudah berada dalam RAB dasar; tidak dibeli dua kali. Ditambah40penghubung vertikal antar tingkat tapak menjadi girder bertangga.
Delapan pengikat RC lama dihapus. Profil RHS tetap mengikuti tebal terpilih.
Beban seluruh30tapak diteruskan ke girder sisi sesuai keseimbangan transversal. SHS B03 dan pelat diperiksa terpisah; tidak diasumsikan menambah kekakuan global.
Lima kotak penopang per tangga:40kolom,40balok dan40diagonal selain40link. Tanpa tambatan beton utama;40kaki memerlukan verifikasi angkur/lantai.
R08 koreksi sketsa: strip x5450–6850 mm pada zona kiri 2 m menjadi dek dan dudukan selebar sekitar 1400 mm. Tangga kanan yang ditandai dihapus; tersisa dua jalur nominal 600 mm pada dua zona. Jumlah jalur bukan pengesahan kapasitas evakuasi. Lebar 600 mm belum dikurangi pegangan/finishing. Kapasitas evakuasi dan aksesibilitas belum lulus pemeriksaan. Tambahan kursi hanya studi modul 500 mm, bukan kapasitas operasi yang disahkan.
Rangka infill baru 20 kolom, balok, pengaku, base plate, karet dan angkur adalah usulan. RC ditakik dengan celah 3 mm. Tumpuan lantai, lendutan, stabilitas, las/baut dan akses pemasangan belum disahkan.
Mesh hanya penutup luar kanan/kiri. Riser depan tetap pelat. Mesh bukan pengganti railing, penahan kerumunan atau bracing; rangka panel dan penjepit tepi dihitung.
Harga mesh Rp30.000/kg, strip Rp15.000/kg, M6 Rp2.500/set, angkur Rp35.000/set dan upah baru adalah allowance perencanaan, bukan penawaran pemasok. Total RAB adalah estimasi dengan allowance.
Berat beli RHS/SHS mengikuti katalog dan varian tebal. Potongan digabung sesuai kelompok stok. Railing SHS tetap 2+18 batang terpisah. Batang layak dari nesting, minimum belum terbukti. Dek memakai allowance luas 10%, bukan pola potong final. Sambungan baru memerlukan pengesahan: pelat 90×120×6, base 140×150×8, M12, 4 angkur/kolom dan posisi kolom hanyalah dasar hitung biaya. Jangan bor lantai atau mulai fabrikasi dari paket ini.
Tahapan: ukur kondisi/akses dan lantai; sahkan struktur/evakuasi serta shop drawing; minta penawaran; kunci daftar potong; mock-up tekuk/mesh; fabrikasi dan QC; pasang dengan penyangga sementara; inspeksi dan serah terima. Dokumen R07 menjadi acuan proses umum, bukan gambar R08.
Sebelum overhead, laba dan pajak tambahan.
Surabaya, 2026-09-15 / ADIGHANI ILHAM

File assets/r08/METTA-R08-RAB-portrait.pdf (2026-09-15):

# SAP / SELARAS ADHI PERKASA

## RENCANA ANGGARAN BIAYA - METTA

R08 - Infill sesuai gambar + mesh sisi / Hollow 2,3 mm / model / SHS acuan 2,0 / 2,8 mm / Dasar / Mesh 25x25 / 2,0 mm |
2026-09-15 | Pembelian | Dengan biaya pelengkap

STUDI OPTIMASI. BELUM UNTUK FABRIKASI.

No. | Pekerjaan / spesifikasi | Volume | Sat. | Upah/sat. | Material/sat. | Jumlah upah | Jumlah material | Total
1 | Kolom tribun Hollow 50x100x2,3 mm | 739,4508 | kg | 6.000 | 13.369 | 4.436.705 | 9.885.888 | 14.322.593
2 | Balok tepi tier Hollow 50x100x2,3 mm | 409,7865 | kg | 6.000 | 13.369 | 2.458.719 | 5.478.530 | 7.937.249
3 | Pengaku longitudinal dek Hollow 50x100x2,3 mm | 1.253,2668 | kg | 6.000 | 13.369 | 7.519.601 | 16.755.213 | 24.274.814
4 | Rangka belakang Hollow 50x100x2,3 mm | 94,7112 | kg | 6.000 | 13.369 | 568.267 | 1.266.216 | 1.834.483
5 | Strut ke kolom beton Hollow 50x100x2,3 mm | 8,074 | kg | 6.000 | 13.369 | 48.444 | 107.943 | 156.387
6 | Bracing X Hollow 50x100x2,3 mm | 234,7808 | kg | 6.000 | 13.369 | 1.408.685 | 3.138.839 | 4.547.524
7 | Balok silang penumpu dek Hollow 50x100x2,3 mm | 313,5958 | kg | 6.000 | 13.369 | 1.881.575 | 4.192.535 | 6.074.110
Subtotal Rangka utama | | | | | | 18.321.996 | 40.825.164 | 59.147.160
8 | Penyangga tangga / usulan Hollow 50x100x2,3 mm | 138,8108 | kg | 6.000 | 13.369 | 832.865 | 1.855.793 | 2.688.658
9 | Pelat tekuk tangga Pelat polos 3 mm | 271,296 | kg | 6.000 | 12.286 | 1.627.776 | 3.333.065 | 4.960.841
10 | Pengaku tapak tangga / usulan SHS 40x40x2 mm | 168,1487 | kg | 6.000 | 12.987 | 1.008.892 | 2.183.691 | 3.192.583
11 | Baut tangga M12x40 kelas 8.8 | 252 | bh | 1.000 | 4.500 | 252.000 | 1.134.000 | 1.386.000
12 | Mur tangga M12 kelas 8 | 252 | bh | 1.000 | 1.500 | 252.000 | 378.000 | 630.000
13 | Ring tangga Ring datar keras M12 | 504 | bh | 50 | 750 | 25.200 | 378.000 | 403.200
Subtotal Tangga | | | | | | 3.998.733 | 9.262.549 | 13.261.282
14 | Rail atas / elemen horizontal SHS 40x40x2 mm | 30,14 | kg | 6.000 | 12.987 | 180.840 | 391.418 | 572.258
15 | Tiang railing dan pegangan SHS 40x40x2,8 mm | 379,8 | kg | 6.000 | 13.128 | 2.278.800 | 4.986.000 | 7.264.800
Subtotal Railing | | | | | | 2.459.640 | 5.377.418 | 7.837.058
16 | Pelat dek Bordes 4 mm | 3.074,688 | kg | 5.000 | 12.937 | 15.373.440 | 39.777.239 | 55.150.679
17 | Riser, fascia dan return Pelat polos 2 mm | 904,32 | kg | 6.000 | 12.296 | 5.425.920 | 11.119.787 | 16.545.707
18 | Papan pinus dudukan Lebar 400 mm; tebal 40 mm | 89,6765 | m | 25.000 | 90.000 | 2.241.913 | 8.070.887 | 10.312.800
19 | Panel kayu sandaran Lebar 400 mm; tebal 40 mm | 20,0475 | m | 25.000 | 90.000 | 501.188 | 1.804.275 | 2.305.463
20 | Cat dan coating baja Persiapan + cat; luas permukaan | 619,0399 | m² | 13.183 | 32.956 | 8.160.508 | 20.401.269 | 28.561.777
Subtotal Dek, penutup dan finishing | | | | | | 31.702.969 | 81.173.457 | 112.876.426
21 | Base plate Pelat 150x150x8 mm | 146,6465 | kg | 6.000 | 11.695 | 879.879 | 1.715.058 | 2.594.937
22 | Pelat sambungan rangka, tangga dan buhul Pelat 6 mm; lembar 120x240 cm | 678,24 | kg | 5.000 | 12.543 | 3.391.200 | 8.507.067 | 11.898.267
23 | Baut rangka dan X M12x40 kelas 8.8 | 803 | bh | 1.000 | 4.500 | 803.000 | 3.613.500 | 4.416.500
24 | Mur rangka dan X M12 kelas 8 | 803 | bh | 1.000 | 1.500 | 803.000 | 1.204.500 | 2.007.500
25 | Ring rangka dan X Ring datar keras M12 | 1.606 | bh | 50 | 750 | 80.300 | 1.204.500 | 1.284.800
26 | Ikatan ke kolom beton / cadangan Angkur dan pelat: belum ditetapkan | 1 | ls | 0 | 2.500.000 | 0 | 2.500.000 | 2.500.000
METTA / Hollow 2,3 mm / model | 1 / 8

No. | Pekerjaan / spesifikasi | Volume | Sat. | Upah/sat. | Material/sat. | Jumlah upah | Jumlah material | Total
27 | Sekrup kayu ke baja + ring #12x65 / usulan | 540 | set | 300 | 1.500 | 162.000 | 810.000 | 972.000
28 | Sekrup penutup + ring EPDM #12x32 / usulan | 3.909 | set | 300 | 800 | 1.172.700 | 3.127.200 | 4.299.900
29 | Karet dudukan 150x150x10 mm | 80 | bh | 500 | 25.000 | 40.000 | 2.000.000 | 2.040.000
Subtotal Sambungan dan pengikat | | | | | | 7.332.079 | 24.681.825 | 32.013.904
30 | Backing riser depan dan hardware railing Backing penutup dan hardware railing / provisional sum | 1 | ls | 0 | 3.500.000 | 0 | 3.500.000 | 3.500.000
31 | Sistem antiselip tangga Sistem antiselip permukaan tangga | 5,9999 | m2 | 0 | 125.000 | 0 | 749.989 | 749.989
32 | Clear coat kayu Clear coat kayu | 20 | L | 0 | 100.000 | 0 | 2.000.000 | 2.000.000
33 | Jasa tekuk pelat Jasa press brake | 60 | tekuk | 20.000 | 0 | 1.200.000 | 0 | 1.200.000
34 | Angkut bengkel-lokasi + bongkar Biaya pelengkap proyek | 2 | rit | 1.500.000 | 0 | 3.000.000 | 0 | 3.000.000
35 | Hoist dan alat angkat LT4 Biaya pelengkap proyek | 7 | hari | 500.000 | 0 | 3.500.000 | 0 | 3.500.000
36 | Perancah dan penyangga sementara Biaya pelengkap proyek | 1 | ls | 2.500.000 | 0 | 2.500.000 | 0 | 2.500.000
37 | Pengukuran + kontrol mutu las/cat Biaya pelengkap proyek | 1 | ls | 2.000.000 | 0 | 2.000.000 | 0 | 2.000.000
38 | Pembersihan, APD dan proteksi Biaya pelengkap proyek | 1 | ls | 1.500.000 | 0 | 1.500.000 | 0 | 1.500.000
39 | Verifikasi desain + investigasi tumpuan Biaya pelengkap proyek | 1 | ls | 7.500.000 | 0 | 7.500.000 | 0 | 7.500.000
Subtotal Biaya pelengkap | | | | | | 21.200.000 | 6.249.989 | 27.449.989
40 | Kolom tambahan infill Hollow 50x100x2,3 mm | 141,0713 | kg | 6.000 | 13.369 | 846.428 | 1.886.015 | 2.732.443
41 | Balok memanjang infill Hollow 50x100x2,3 mm | 55,5556 | kg | 6.000 | 13.369 | 333.333 | 742.735 | 1.076.068
42 | Pengaku silang infill Hollow 50x100x2,3 mm | 185,8965 | kg | 6.000 | 13.369 | 1.115.379 | 2.485.293 | 3.600.672
43 | Base plate infill Pelat 8 mm / 140x150 mm | 34,2175 | kg | 6.000 | 11.695 | 205.305 | 400.180 | 605.485
44 | Angkur lantai infill M12 / allowance sambungan, mutu dan penanaman belum dipilih | 84 | set | 15.000 | 35.000 | 1.260.000 | 2.940.000 | 4.200.000
45 | Karet dudukan infill Karet 140x150x3 mm / allowance | 20 | bh | 500 | 25.000 | 10.000 | 500.000 | 510.000
46 | Angkur lantai kolom utama M12 / allowance; spesifikasi dan kapasitas belum ditetapkan | 336 | set | 15.000 | 35.000 | 5.040.000 | 11.760.000 | 16.800.000
Subtotal Infill baru | | | | | | 8.810.445 | 20.714.223 | 29.524.668
47 | Rangka panel mesh SHS 40x40x2 mm | 299,0213 | kg | 6.000 | 12.987 | 1.794.128 | 3.883.290 | 5.677.418
48 | Kawat loket penutup sisi Galvanis 25x25 mm / kawat 2.0 mm | 70 | kg | 0 | 30.000 | 0 | 2.100.000 | 2.100.000
49 | Strip penjepit tepi mesh Flat bar 30x3 mm / dua sisi vertikal dan horizontal per panel | 84,78 | kg | 6.000 | 15.000 | 508.680 | 1.271.700 | 1.780.380
50 | Pengikat mesh dan rangka panel M6 galvanis + mur + ring / allowance | 1.218 | set | 1.000 | 2.500 | 1.218.000 | 3.045.000 | 4.263.000
51 | Pemasangan dan potong mesh Panel kawat loket; ujung kawat ditutup strip | 13,8739 | m2 | 35.000 | 0 | 485.585 | 0 | 485.585
Subtotal Penutup mesh | | | | | | 4.006.393 | 10.299.990 | 14.306.383
TOTAL | | | | | | 97.832.255 | 198.584.615 | 296.416.870

## SUBTOTAL PER KOMPONEN - REKAP BIAYA YANG SAMA

Komponen | Upah | Material | Gabungan
Kolom | 5.283.133 | 11.771.903 | 17.055.036
Balok | 5.241.894 | 11.680.016 | 16.921.910
Pengaku dek dan strut | 8.683.424 | 19.348.449 | 28.031.873
Bracing | 1.408.685 | 3.138.839 | 4.547.524
Tangga dan penyangga | 3.998.733 | 9.262.549 | 13.261.282
Rail horizontal | 180.840 | 391.418 | 572.258
Tiang railing dan pegangan | 2.278.800 | 4.986.000 | 7.264.800
Pelat dek | 15.373.440 | 39.777.239 | 55.150.679
Penutup | 5.425.920 | 11.119.787 | 16.545.707
Pelat sambungan dan base plate | 4.271.079 | 10.222.125 | 14.493.204
Sambungan dan pengikat | 3.061.000 | 14.459.700 | 17.520.700
Dek, penutup dan finishing | 10.903.609 | 30.276.431 | 41.180.040
Biaya pelengkap | 21.200.000 | 6.249.989 | 27.449.989
Penutup mesh dan rangkanya | 4.006.393 | 10.299.990 | 14.306.383
Tumpuan kolom tambahan | 1.475.305 | 3.840.180 | 5.315.485
Tumpuan kolom utama | 5.040.000 | 11.760.000 | 16.800.000

## SUBTOTAL KG DAN BATANG PER PROFIL

Berat pembelian dari RAB aktif; kg = batang x kg/batang.

Profil / ketebalan terpilih | Kg / batang 6 m | Batang 6 m / ekuivalen | Subtotal kg
Hollow 50x100x2,3 mm | 32,5 | 110 | 3.575
SHS 40x40x2 mm | 15,07 | 33 | 497,31
SHS 40x40x2,8 mm | 21,1 | 18 | 379,8
Flat bar 30x3 mm / dua sisi vertikal dan horizontal per panel | 4,239 | 20 | 84,78
SUBTOTAL PROFIL BATANG | | 181 | 4.536,89
PELAT / BARIS KG LAIN | - | - | 5.179,408
TOTAL SEMUA BARIS KG | - | - | 9.716,298

Lingkup R08: pola 110 batang RHS. Tebal mengikuti pilihan aktif. Stok SHS dipisahkan per profil. Pecahan setelah edit atau pada berat bersih adalah ekuivalen, bukan pesanan stok. Pelat tidak dikonversi menjadi batang. Edit manual RAB tetap ikut; subtotal ini tidak menambah biaya.

## SUBTOTAL KG DAN ALOKASI BATANG PER KOMPONEN

Komponen (baris satuan kg) | Subtotal kg | Alokasi batang profil 6 m
Kolom | 880,522 | 27,093
Balok | 873,649 | 26,8815
Pengaku dek dan strut | 1.447,237 | 44,5304
Bracing | 234,781 | 7,224
Tangga dan penyangga | 578,255 | 15,4289
Rail horizontal | 30,14 | 2
Tiang railing dan pegangan | 379,8 | 18
Pelat dek | 3.074,688 | -
Penutup | 904,32 | -
Pelat sambungan dan base plate | 824,886 | -
Penutup mesh dan rangkanya | 453,801 | 39,8422
Tumpuan kolom tambahan | 34,218 | -
TOTAL | 9.716,298 | 181

Alokasi batang komponen boleh pecahan karena satu stok dipakai bersama; jangan bulatkan tiap komponen.

## DASAR KUANTITAS DAN CATATAN

Kode | Pekerjaan | Dasar hitungan / status
X01 | Kolom tribun | R08: 133.559800 m potongan; alokasi dari 110 stok bersama x 32.5 kg/batang. Pola layak, minimum belum terbukti. Panjang Revit; berat dari penampang/katalog
X02 | Balok tepi tier | R08: 73.710000 m potongan; alokasi dari 110 stok bersama x 32.5 kg/batang. Pola layak, minimum belum terbukti. Panjang Revit; berat dari penampang/katalog
X03 | Pengaku longitudinal dek | R08: 226.069001 m potongan; alokasi dari 110 stok bersama x 32.5 kg/batang. Pola layak, minimum belum terbukti. Panjang Revit; berat dari penampang/katalog
X04 | Rangka belakang | R08: 17.396000 m potongan; alokasi dari 110 stok bersama x 32.5 kg/batang. Pola layak, minimum belum terbukti. Panjang Revit; berat dari penampang/katalog
X05 | Strut ke kolom beton | R08: 1.475999 m potongan; alokasi dari 110 stok bersama x 32.5 kg/batang. Pola layak, minimum belum terbukti. Panjang Revit; berat dari penampang/katalog
X06 | Bracing X | R08: 42.388000 m potongan; alokasi dari 110 stok bersama x 32.5 kg/batang. Pola layak, minimum belum terbukti. Panjang Revit; berat dari penampang/katalog
B01 | Balok silang penumpu dek | R08: 57.005998 m potongan; alokasi dari 110 stok bersama x 32.5 kg/batang. Pola layak, minimum belum terbukti. Panjang Revit; berat dari penampang/katalog
B02 | Penyangga tangga / usulan | R08: 19.639757 m potongan; alokasi dari 110 stok bersama x 32.5 kg/batang. Pola layak, minimum belum terbukti. Usulan belum dimodelkan
X07 | Rail atas / elemen horizontal | 10 elemen; 8.425400 m; 2 stok x6 m. Family aktif masih M_W Shapes; volume family tidak dipakai sebagai berat hollow. Model + pembelian
X08 | Tiang railing dan pegangan | 85 elemen; 97.498388 m; 18 stok. Harga 2,8 mm mengikuti katalog R04 karena spesifikasi Excel 2 mm berbeda. Model + pembelian
X09 | Pelat dek | R08: Dek 88.913631 m2; pembelian ceil(luas x 1,10 / 2,88) lembar 4 mm. Allowance luas, bukan nesting dek. Studi koordinasi; ukur dan sahkan sebelum fabrikasi
X10 | Riser, fascia dan return | R08: 286 potongan pelat depan/sisi infill; 20 lembar 2 mm 1200x2400 dari nesting. Studi koordinasi; ukur dan sahkan sebelum fabrikasi
X11 | Pelat tekuk tangga | R08: 30 tapak tekuk; 4 lembar 3 mm dari blank konservatif. Uji kupon tekuk diperlukan. Studi koordinasi; ukur dan sahkan sebelum fabrikasi
B03 | Pengaku tapak tangga / usulan | R08: 65.999868 m; alokasi pola 31 batang SHS bersama untuk tangga + panel. Railing lama tetap kelompok terpisah. Usulan belum dimodelkan
X13 | Base plate | R08: 80 base lama 150x150x8 + 20 base infill dinesting bersama dalam 1 lembar; berat beli dialokasikan menurut luas. Studi koordinasi; ukur dan sahkan sebelum fabrikasi
X14 | Pelat sambungan rangka, tangga dan buhul | R08: 932 pelat 6 mm; 5 lembar nesting. Pelat 90x120 dan buhul 200x200 adalah allowance sambungan, belum desain baut/las. Studi koordinasi; ukur dan sahkan sebelum fabrikasi
X15 | Baut rangka dan X | R08: Dua baut per ujung balok; pengikat lama dikurangi 8 strut, tambah ujung infill, cadangan 5%. Dua ring per baut pembelian. Studi koordinasi; ukur dan sahkan sebelum fabrikasi
X17 | Mur rangka dan X | R08: Dua baut per ujung balok; pengikat lama dikurangi 8 strut, tambah ujung infill, cadangan 5%. Dua ring per baut pembelian. Studi koordinasi; ukur dan sahkan sebelum fabrikasi
X18 | Ring rangka dan X | R08: Dua baut per ujung balok; pengikat lama dikurangi 8 strut, tambah ujung infill, cadangan 5%. Dua ring per baut pembelian. Studi koordinasi; ukur dan sahkan sebelum fabrikasi
B04 | Baut tangga | R08: Dua baut per ujung penyangga tangga, cadangan 5%. Studi koordinasi; ukur dan sahkan sebelum fabrikasi
B05 | Mur tangga | R08: Dua baut per ujung penyangga tangga, cadangan 5%. Studi koordinasi; ukur dan sahkan sebelum fabrikasi
B06 | Ring tangga | R08: Dua baut per ujung penyangga tangga, cadangan 5%. Studi koordinasi; ukur dan sahkan sebelum fabrikasi
X16 | Ikatan ke kolom beton / cadangan | R08: 8 titik ikatan RC tersisa setelah 8 strut dihapus. Cadangan biaya proporsional 8/16 x Rp5.000.000; ukuran/kapasitas angkur belum dipilih. Studi koordinasi; ukur dan sahkan sebelum fabrikasi

Kode | Pekerjaan | Dasar hitungan / status
X19 | Sekrup kayu ke baja + ring | R08: 500 set lama + 8 set per 5 tingkat infill; pola pengikat kayu harus dirinci. Studi koordinasi; ukur dan sahkan sebelum fabrikasi
X20 | Sekrup penutup + ring EPDM | R08: Keliling panel pelat / jarak maksimum 200 mm, cadangan 5%; pengikat mesh dihitung terpisah. Studi koordinasi; ukur dan sahkan sebelum fabrikasi
X21 | Karet dudukan | 80 dudukan aktif; satu karet per base plate. Model + pembelian
X22 | Papan pinus dudukan | R08: Papan baru setara 6.710599 m x 400x40 mm setelah takikan RC; allowance potong 10%. Studi koordinasi; ukur dan sahkan sebelum fabrikasi
X23 | Panel kayu sandaran | Luas 7,29 m² dari geometri arsip, bukan hasil ukur Revit baru. Pembelian+10%. Koreksi label 400x40 cm menjadi lebar 400 mm/tebal 40 mm. Geometri arsip / allowance
X24 | Cat dan coating baja | R08: Luas luar hollow, strip, kedua muka pelat + 10% tepi; mesh galvanis tidak dicat. Tarif per m2 acuan R07 dipertahankan. Studi koordinasi; ukur dan sahkan sebelum fabrikasi
E01 | Backing riser depan dan hardware railing | R08: cadangan Rp3.500.000 untuk backing pelat depan, ujung railing dan penghubung yang belum terukur. Tidak mencakup rangka/penjepit mesh yang sudah dirinci pada M02-M04. Allowance anggaran
E02 | Sistem antiselip tangga | R08: Antiselip sesuai luas tapak tersisa; bukan bidang infill dudukan. Studi koordinasi; ukur dan sahkan sebelum fabrikasi
E03 | Clear coat kayu | R08: Cadangan clear coat 20 L untuk kayu lama + infill; konsumsi aktual mengikuti produk/uji lapangan. Studi koordinasi; ukur dan sahkan sebelum fabrikasi
E04 | Jasa tekuk pelat | R08: Dua tekukan per tapak; takikan RC dan kupon dibahas bengkel. Studi koordinasi; ukur dan sahkan sebelum fabrikasi
EL01 | Angkut bengkel-lokasi + bongkar | Bukan ongkir toko-bengkel; ukuran truk/jam akses diverifikasi. Allowance anggaran
EL02 | Hoist dan alat angkat LT4 | Allowance 7 hari, kapasitas/jalur angkat ditentukan metode kerja. Allowance anggaran
EL03 | Perancah dan penyangga sementara | Sewa, pengiriman dan pembongkaran. Allowance anggaran
EL04 | Pengukuran + kontrol mutu las/cat | Allowance ukur, inspeksi visual, DFT dan dokumentasi. Tidak termasuk uji beton laboratorium. Allowance anggaran
EL05 | Pembersihan, APD dan proteksi | Area LT4, alat keselamatan kerja dan serah terima. Allowance anggaran
EL06 | Verifikasi desain + investigasi tumpuan | Provisional sum pemeriksaan insinyur dan pengumpulan data beton; lingkup lab mengikuti temuan. Allowance anggaran
I01 | Kolom tambahan infill | R08: 25.700000 m potongan; alokasi dari 110 stok bersama x 32.5 kg/batang. Pola layak, minimum belum terbukti. R08: rangka infill usulan, belum elemen Revit
I02 | Balok memanjang infill | R08: 10.000000 m potongan; alokasi dari 110 stok bersama x 32.5 kg/batang. Pola layak, minimum belum terbukti. R08: rangka infill usulan, belum elemen Revit
I03 | Pengaku silang infill | R08: 33.600907 m potongan; alokasi dari 110 stok bersama x 32.5 kg/batang. Pola layak, minimum belum terbukti. R08: rangka infill usulan, belum elemen Revit
M02 | Rangka panel mesh | R08: 114.502857 m; alokasi pola 31 batang SHS bersama untuk tangga + panel. Railing lama tetap kelompok terpisah. Usulan belum dimodelkan
I04 | Base plate infill | R08: 20 pelat baru; berbagi 1 lembar 1200x2400 dengan 80 base lama, bukan dibulatkan terpisah. Tebal/dimensi dan tumpuan harus dihitung. Usulan; tarif allowance bila dinyatakan
I05 | Angkur lantai infill | R08: 4 angkur per 20 base plate + 5%; Rp35.000 material + Rp15.000 pemasangan/set adalah allowance, bukan harga katalog atau kapasitas sah. Usulan; tarif allowance bila dinyatakan
I06 | Karet dudukan infill | R08: 20 alas baru; lantai/tumpuan dan tekanan kontak belum diverifikasi. Usulan; tarif allowance bila dinyatakan
I07 | Angkur lantai kolom utama | R08: 80 base kolom utama x 4 angkur + 5%. Baut M12x40 rangka bukan angkur beton. Cadangan ini melengkapi jalur tumpuan FEM; kekakuan base, karet 10 mm, lantai, mutu beton dan produk angkur harus diverifikasi. Usulan; tarif allowance bila dinyatakan
M01 | Kawat loket penutup sisi | R08: 1 roll 1.2x30 m x 70 kg. Luas mesh bersih 13.8739 m2. Harga allowance Rp30.000/kg, wajib diganti penawaran. https://www.pabrikbrc.net/2019/07/jual-wire-mesh-kawat-loket-merk-givro.html Usulan; tarif allowance bila dinyatakan

Kode | Pekerjaan | Dasar hitungan / status
M03 | Strip penjepit tepi mesh | R08: 240 potongan / 20 batang 6 m. Berat teoritis 4,239 kg/batang, tarif material allowance Rp15.000/kg. Usulan; tarif allowance bila dinyatakan
M04 | Pengikat mesh dan rangka panel | R08: Penjepit maksimum 200 mm + 4 pengikat panel per rangka. Jarak/kapasitas belum disahkan. Harga material allowance Rp2.500/set. Usulan; tarif allowance bila dinyatakan
M05 | Pemasangan dan potong mesh | R08: Allowance upah Rp35.000/m2; terpisah dari upah rangka, strip dan pengikat. Usulan; tarif allowance bila dinyatakan

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

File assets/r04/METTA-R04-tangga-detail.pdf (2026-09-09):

17700

5000

DEK BORDES 4 mm / 6 X BELAKANG + 2 X SISI + 2 X DEK

## SAP / SELARAS ADHI PERKASA

# T-01 DENAH MODUL TANGGA / TUMPUAN

METTA / R04
09.09.2026
mm / NTS | LOD200 koordinasi; detail usulan terukur, belum rilis fabrikasi.

56 bidang sesuai outline IFC; luas setiap bidang cocok dengan audit Revit sebelum penggantian. Tapak 600 / 800 / 2000; pengaku SHS40x40x2, jarak bersih <=75; stringer RHS50x100x2,3. Stringer pada sisi dan antara: bentang pengaku <=800. Jalur ke rangka utama perlu koordinasi node.

266,7

50 luar

70,35 bersih

POTONGAN TAPAK / t3 / SHS40x40x2

800 / contoh

266.7

DENAH / 3 PENGAKU + 2 STRINGER MODUL

Landing466,6:5pengaku
Lebar2000:4garis stringer

# T-02 PELAT TEKUK 3 MM / PENGAKU TAPAK

Ukuran contoh tapak 800x266,7. Lebar lain600/2000; landing dalam466,6, lihat jadwal JSON. Dua tekukan90 derajat; dimensi luar flange50. Ri3 dan K0,40 adalah asumsi uji kupon bengkel. Celah bersih penyangga <=75; antiselip agregat di seluruh bidang injak, nosing warna kontras.

90

70 pitch | 120

25 tepi

RHS / ujung pada x20; baut pada x45

KUPINGAN SAMPING 6 | PELAT PENERIMA 6

2 x M12 - lubang14 / baut40 nominal

SKEMA PASANG / pelat sambungan di luar profil

Akses kunci >=30; detail penerima mengikuti node rangka

Dudukan gravitasi dan pengaku stabilitas diperiksa terpisah

# T-03 SAMBUNGAN BAUT / LAS BENGKEL

Usulan kupingan samping6mm 90x120:2bautM12 kelas8.8, lubang14, 2ring/baut; bukan end plate menutup RHS. Las sudut kaki3mm di bengkel; panjang efektif dan pelat penerima harus dihitung dari gaya node.
Baut mengikat kupingan di luar rongga RHS; jangan kencangkan langsung menekan dinding hollow2,3mm.

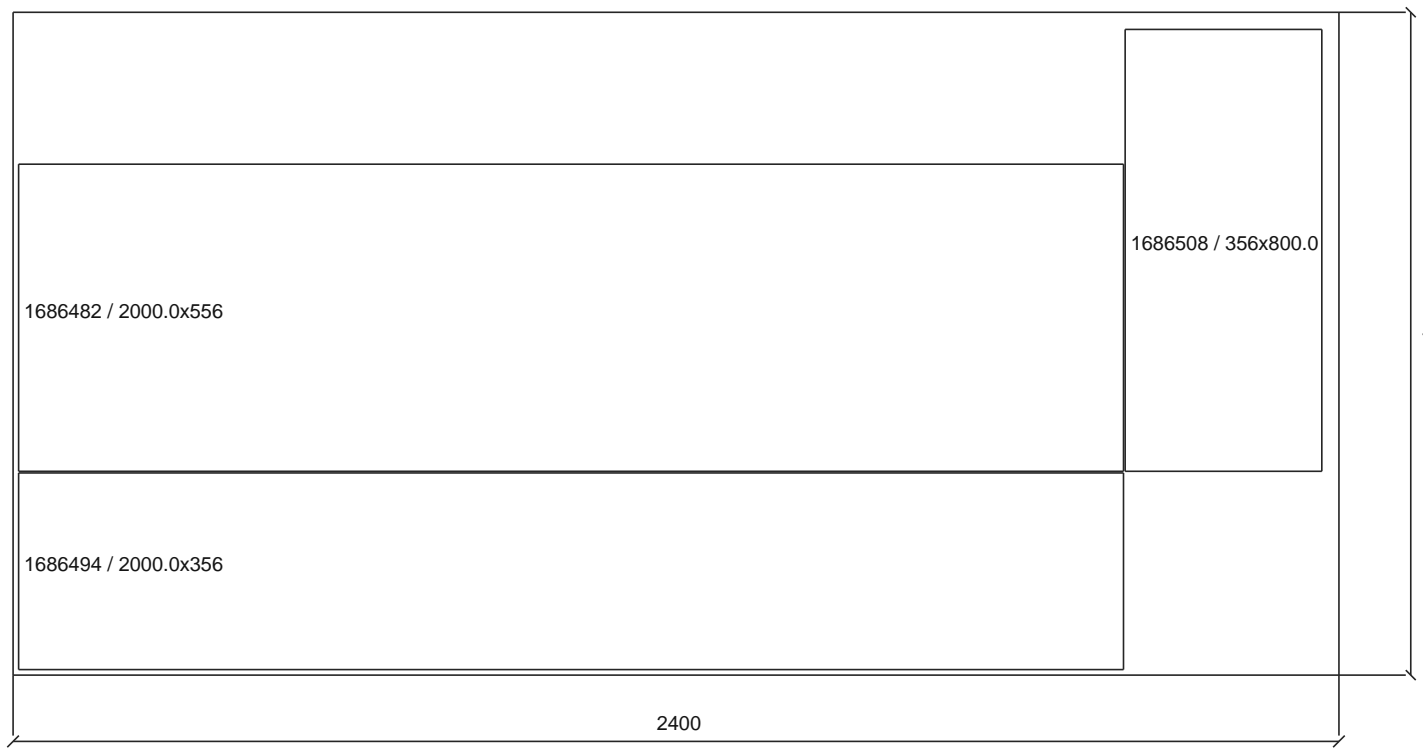
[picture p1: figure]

1200

56 BLANK / 8 LEMBAR / LUAS 16.484 m2

Contoh flat tapak266,7: 356 mm; landing466,6: 556 mm

BD = 5.403 mm per tekukan (asumsi)

# T-04 BENTANGAN / NESTING / URUTAN KERJA

Stok1200x2400, trim10mm, kerf3mm. Pilihan terbaik dari160varian potong lurus; bukan optimum global. BD pertekuk = 2(Ri+t) - pi/2(Ri+K.t); blank = D+2x50-2BD, dibulatkan ke atas1mm.
Ukur > kupon tekuk > potong dan bor > tekuk > las jig > trial fit > cat > baut lokasi > touch-up.

5519

2540 / 2500 + fascia40

SAMPING KIRI / PANEL DIPOTONG DI KOLOM BETON

506 / kolom500 + 2x3

40 fascia

25 return

DETAIL TEPI / t2 / pembesaran10x

# T-05 PENUTUP 2 MM / TAMPAK DAN TAKIKAN

Riser, fascia dan sisi tertutup; belakang dan bawah terbuka. Semua permukaan baja dicat.
Penutup di luar muka balok. Return25mm; empat kolom beton diberi celah3mm; tidak ditutup menembus beton. 310 bagian native / 62.978m2 / 988.750kg teoritis. Sekrup dan backing mengikuti detail pemasangan.

TAMPAK BELAKANG / NODE +150 DAN +2350

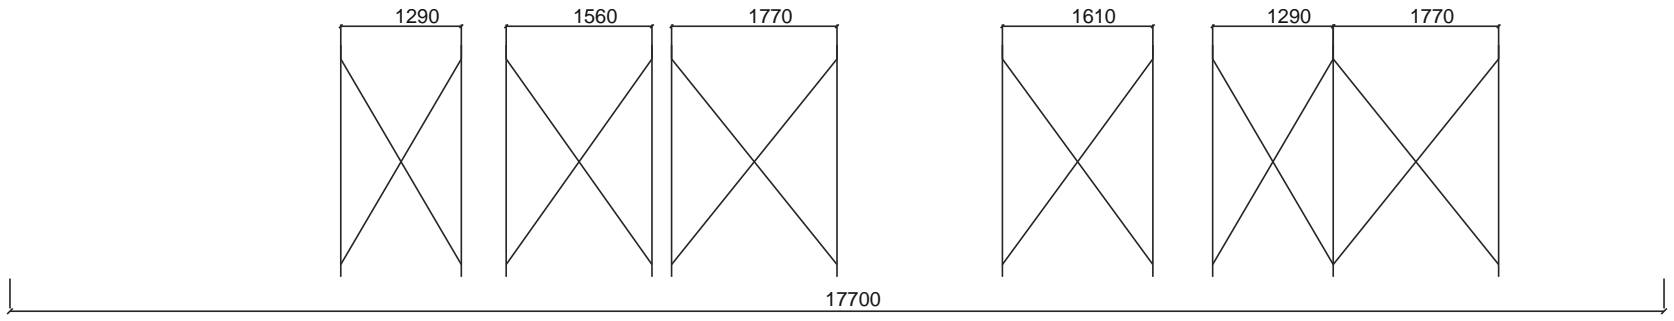
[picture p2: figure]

1290 | 1290

1000

DENAH X MENDATAR / DI BAWAH DEK +1500

# T-06 BRACING X / POSISI REVISI NATIVE

10setX:6belakang,2sisi tetap,2mendatar di bawah dek+1500.12diagonal belakang lama telah dihapus.
X belakang memakai bidangY4970/5030 agar diagonal bersilang tanpa bertabrakan. Sambungan ujung belum final. X mendatar: lapis atas1325..1375 dan bawah1265..1315; celah10mm. Ukuran profil RHS50x100x2,3.

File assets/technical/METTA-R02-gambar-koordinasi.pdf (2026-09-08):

GRID NOMINAL 1-11 / A-F; TUMPUAN TAMBAHAN MENGIKUTI MODEL

DEK 4 mm / ELEVASI TIER +500 / +1000 / +1500 / +2000 / +2500

# METTA / LT 04

# S-01 DENAH TRIBUN

R03 / 08.09.2026
LOD 200 / KOORDINASI

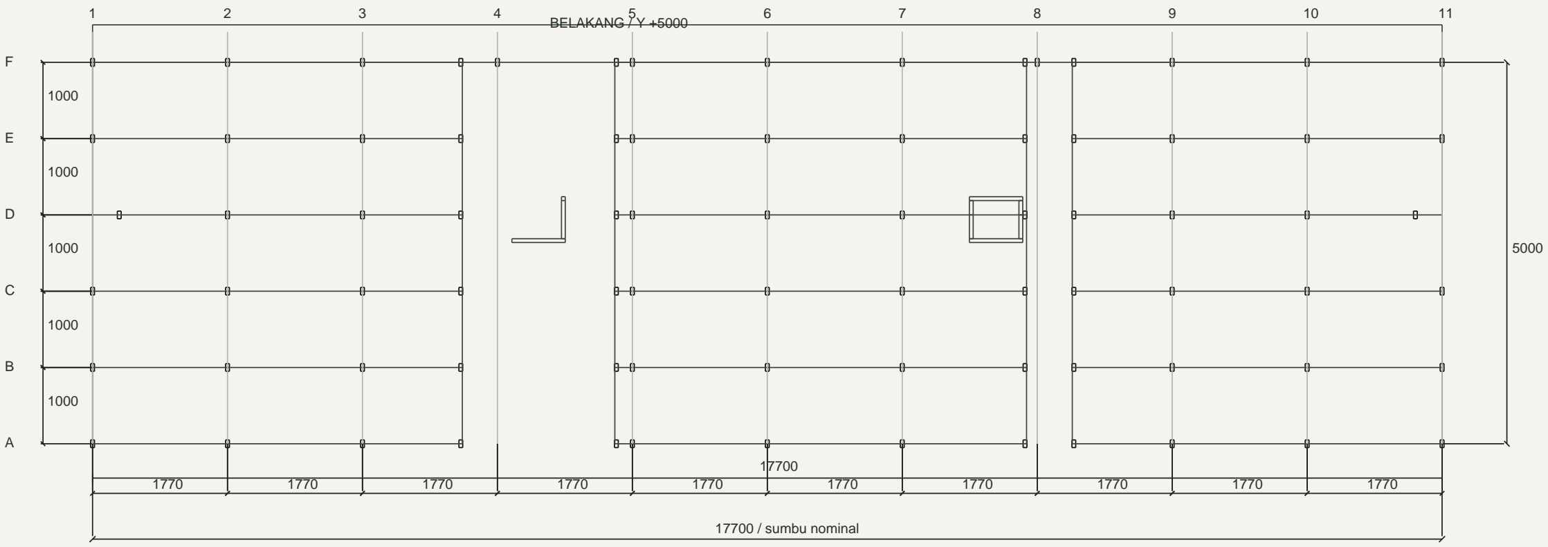
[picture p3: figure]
BELAKANG / Y +5000; 17700 / sumbu nominal

SATUAN: mm | PDF: FIT / NTS | DIMENSI NOMINAL KOORDINASI | DETAIL TERSEDIA DIPERTAHANKAN

Dek bordes 4 mm. Proyeksi batas luar model; bukaan di sekitar beton harus disurvei. Area BOQ 82,345 m2 dari parameter Revit; bukan luas proyeksi persegi gambar ini.

LOD 200: bentuk, ukuran dan posisi perkiraan. Detail sambungan mengikuti status masing-masing.

GRID NOMINAL 1-11 / A-F; TUMPUAN TAMBAHAN MENGIKUTI MODEL

DUDUKAN 150 x 150; PLAT 8 + KARET 10; DASAR KOLOM +18

# S-02 RENCANA TUMPUAN

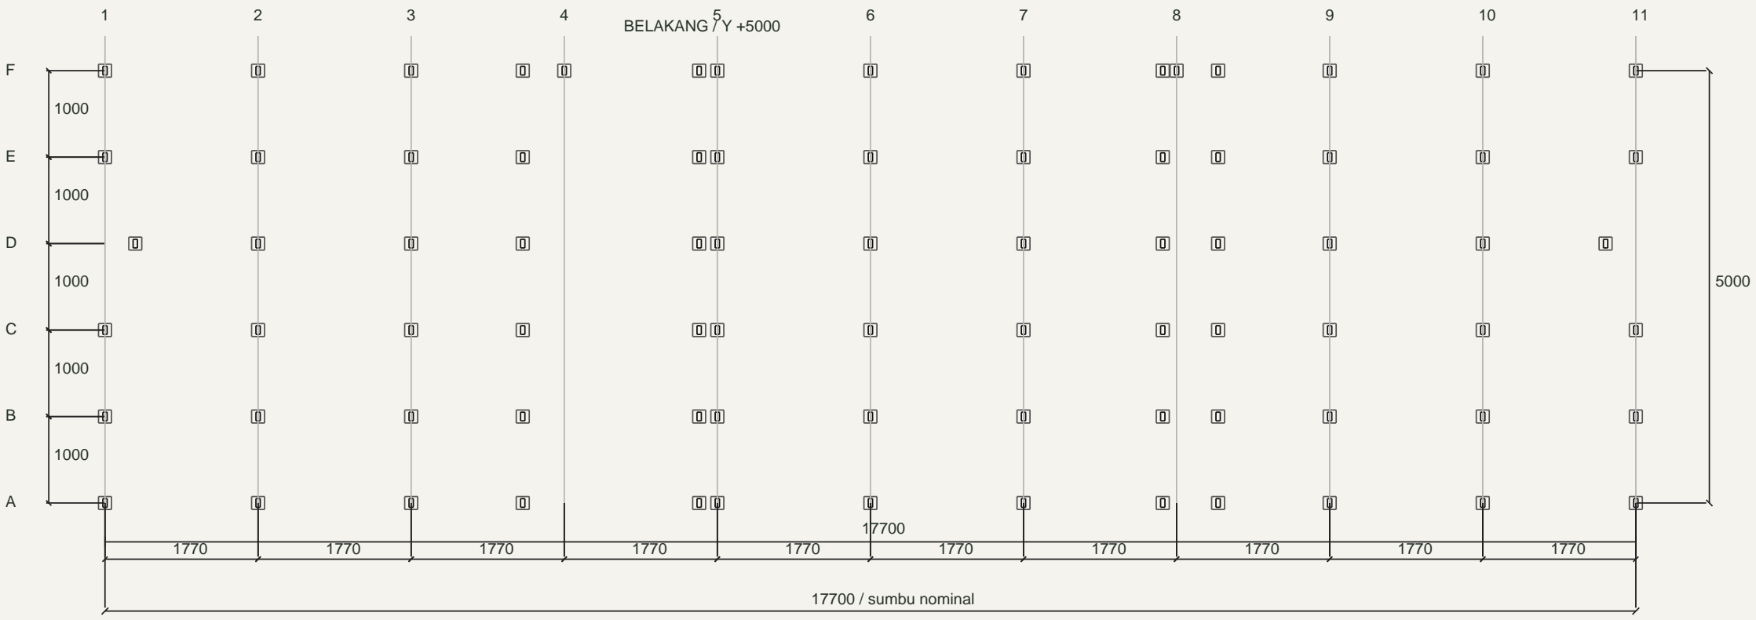
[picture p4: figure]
BELAKANG / Y +5000; 17700 / sumbu nominal

80 kolom, 80 base plate 150x150x8, 80 karet 150x150x10.
Dasar kolom +18 mm. Dudukan lepas tidak otomatis menjadi sendi yang menahan geser/angkat.

GRID NOMINAL 1-11 / A-F; TUMPUAN TAMBAHAN MENGIKUTI MODEL

RHS 50 x 100 x 2,3 / 8 X / NODE BAWAH +150 / TUMPUAN DEK: LIHAT S-06

# S-03 RENCANA RANGKA & X

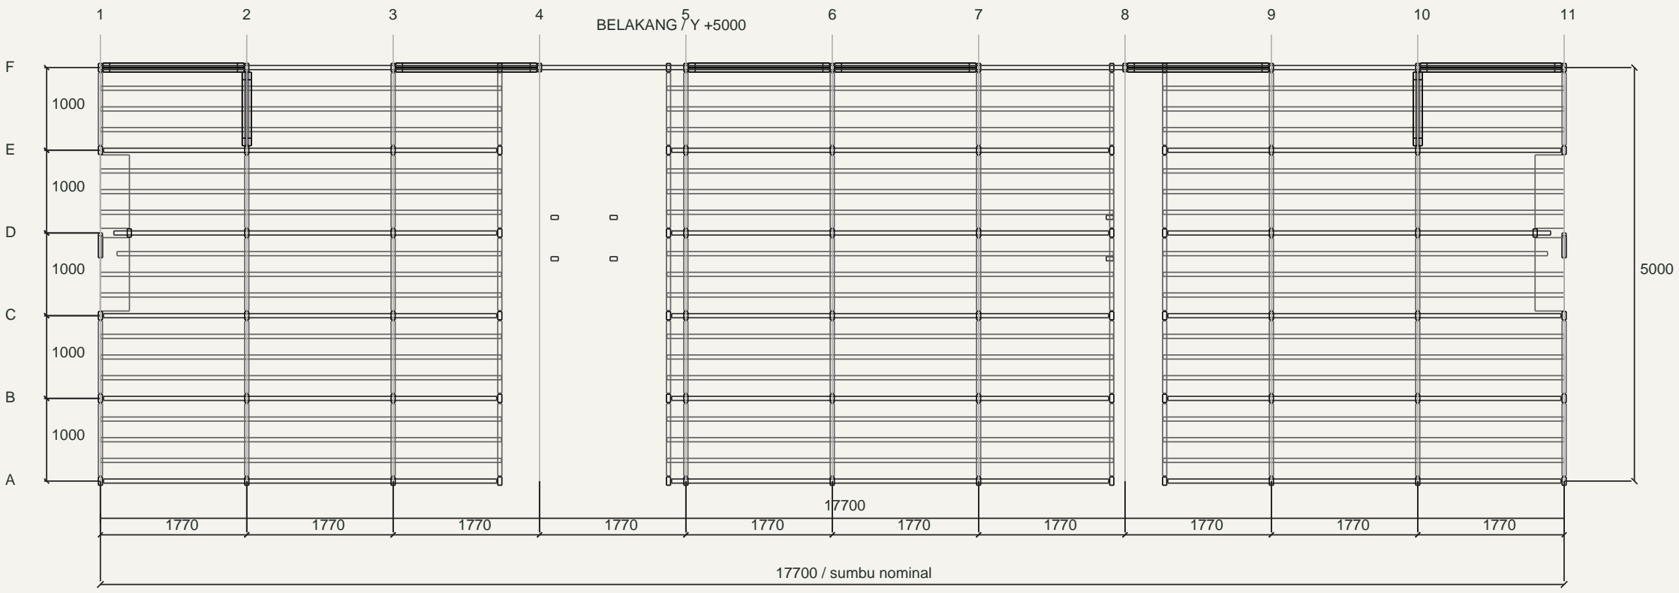
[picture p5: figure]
BELAKANG / Y +5000; 17700 / sumbu nominal

161 RHS 50x100x2,3 termasuk 16 diagonal / 8 X. Node bawah +150 mm.
45 joist longitudinal dan 65 balok silang mengikuti revisi model; celah sambungan belum final.

RHS 50 x 100 x 2,3 / DEK 4 / TINGGI NOMINAL DARI LT4 +0

# S-04 TAMPAK DEPAN

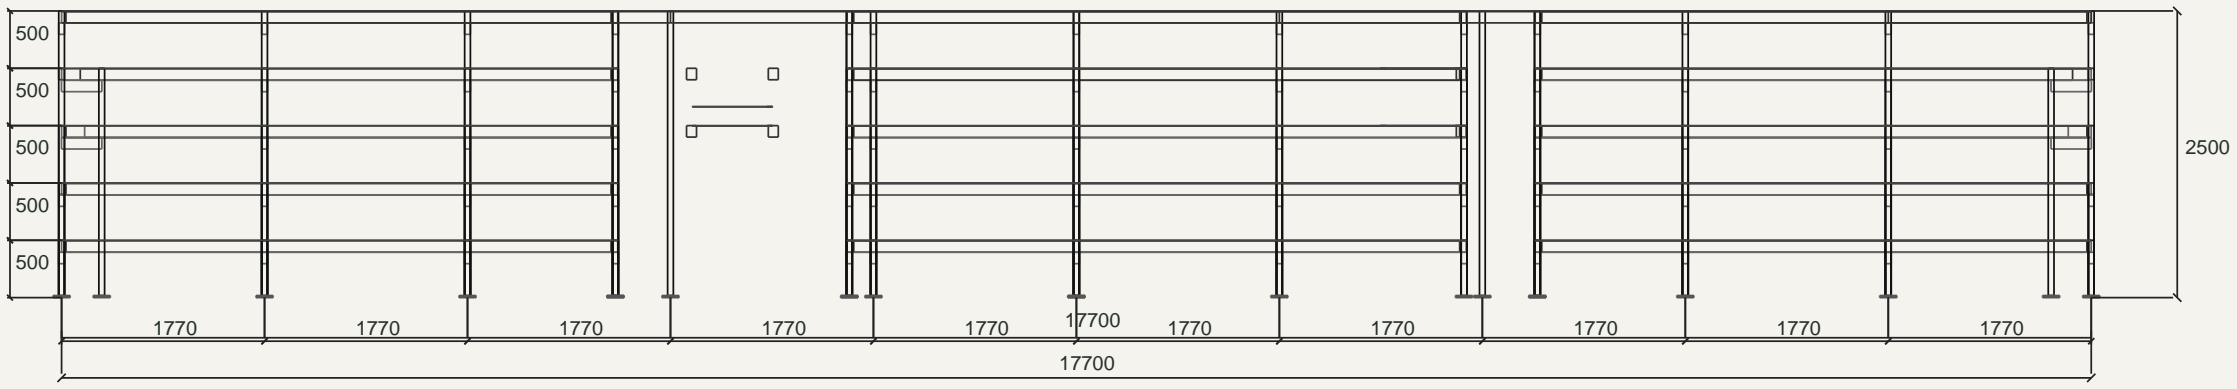
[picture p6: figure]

Proyeksi rangka dari lapangan. Semua tingkat terlihat transparan; garis belakang tidak dihapus. Finishing, railing dan tangga perlu dicocokkan dengan model arsitektur.

RHS 50 x 100 x 2,3 / DEK 4 / DASAR KOLOM +18

NODE X +150 / ELEVASI TERHADAP LT4 +0

# S-05 TAMPAK SAMPING

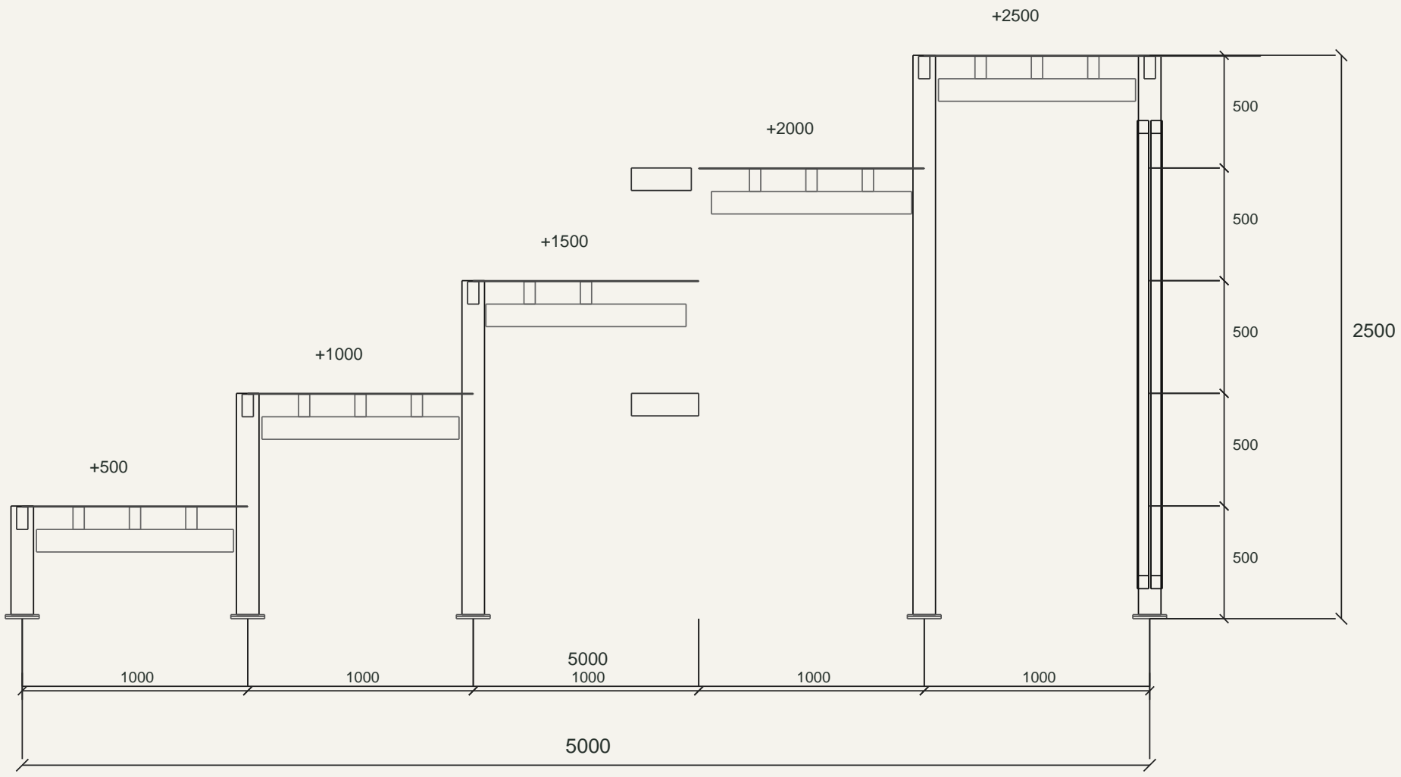
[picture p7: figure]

Potongan sisi x=0, toleransi seleksi 100 mm; tinggi tier nominal 500/1000/1500/2000/2500. X melintang tetap studi. Penyaluran gaya horizontal ke beton belum terverifikasi.

RHS 50 x 100 x 2,3 / DEK 4 / DASAR KOLOM +18

NODE X +150 / ELEVASI TERHADAP LT4 +0

250 | 250 | 250 | 250

SKEMA TARGET PENYANGGA DEK 250 mm

# S-06 POTONGAN PORTAL

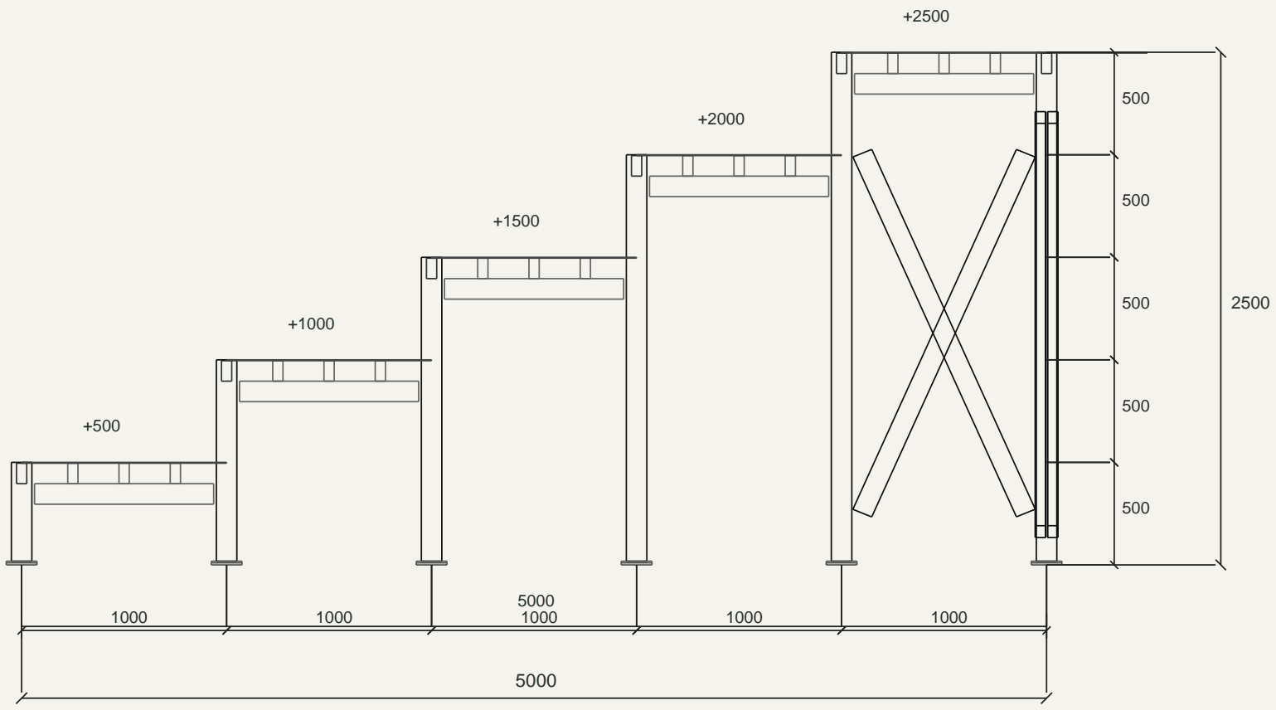
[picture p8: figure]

Potongan portal x=1770, toleransi seleksi 100 mm. Dek 4 mm; tumpuan utama mengikuti model. Jarak penyangga 250 mm adalah target studi dek, bukan bukti beban titik dan getaran lulus.

BORDES 4 mm / USULAN KOORDINASI

5 MODUL x 1000 / 15 KENAIKAN x 166,67 (NOMINAL)

# S-07 POTONGAN TANGGA

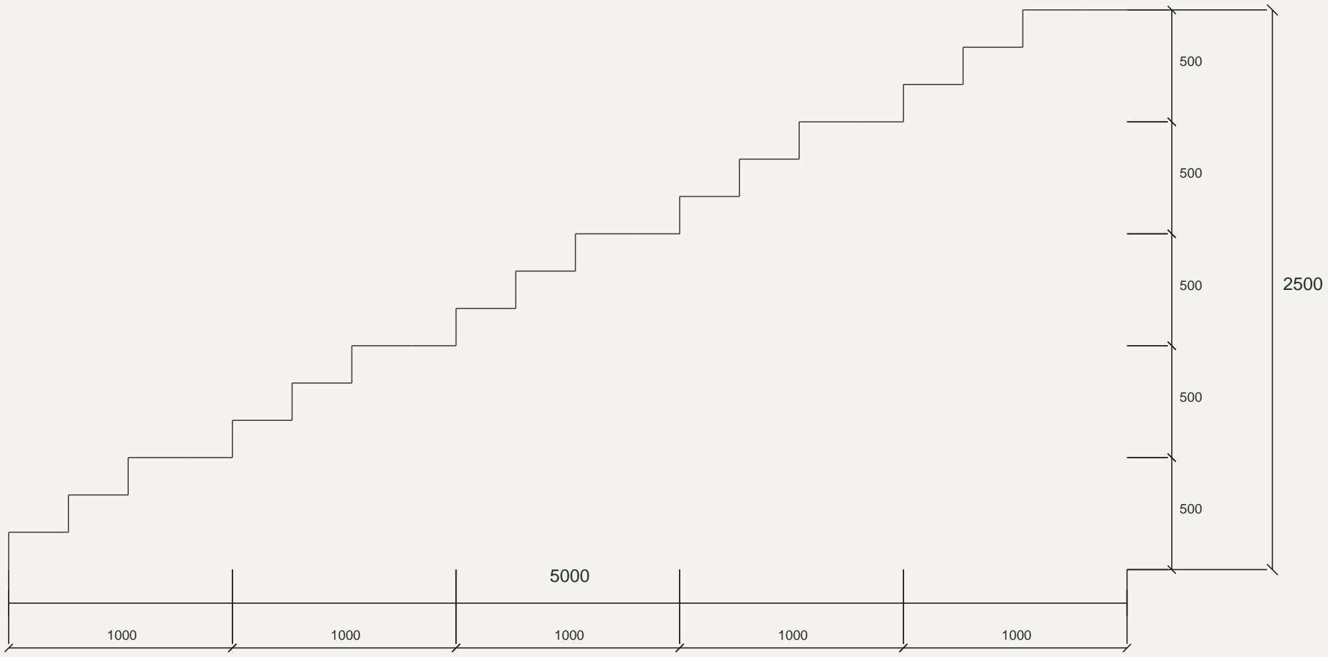
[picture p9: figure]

Geometri tangga dari web arsitektur; 5 tier, kenaikan per tier 500 mm.
Jalur 2000 mm terpotong kolom beton; jalur 600 mm belum dibuktikan memenuhi evakuasi.

1000

## BORDES 4 mm / USULAN KOORDINASI

267 | 267 | 267 | 199

166.67

166.67

166.67

500

## TAPAK 267 / LANDING 199 / DEK 4 mm

Radius tekuk dan panjang bentangan: belum ditetapkan

# S-08 DETAIL ANAK TANGGA

Satu modul usulan: 3 kenaikan 166,67 mm; tapak 267 mm, sisa landing 199 mm. Bordes 4 mm. Radius tekuk, bentangan potong dan rangka tangga belum ditetapkan.

2000 modul ilustrasi

1100

1000 | 1000

1100

100 bersih

RAILING SKEMATIS; PROFIL PADA MODEL DIPERTAHANKAN

# S-09 RAILING & BALUSTRADE

Skema koordinasi: tinggi 1100 mm, bukaan bersih baluster <=100 mm sebagai target studi. Beban pagar, pemanjatan, sambungan dan lebar jalur harus diperiksa; ukuran bukan persetujuan.

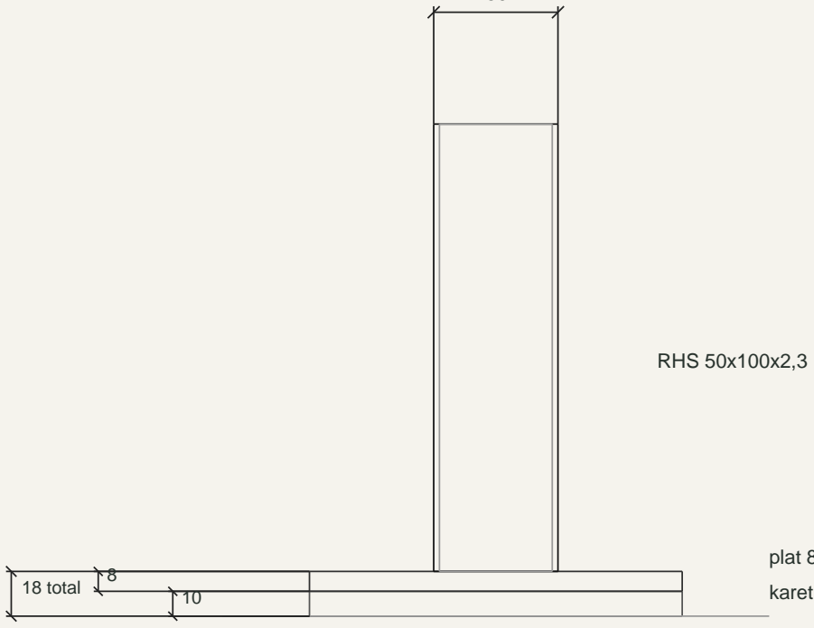
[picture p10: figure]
RHS 50x100x2,3; 18 total

karet 10

plat 8

150

50

150

150

DENAH DUDUKAN

PLAT 150 x 150 x 8

KARET 150 x 150 x 10

## RHS 50 x 100 x 2,3 / DIMENSI NOMINAL

# S-10 BASE PLATE & KARET

Dudukan sesuai model: karet 10, base plate 8, kolom mulai +18 mm.
Tanpa angkur ke pelat LT4 mengikuti konsep sumber. Las dan tahan geser/angkat belum dirancang.

D1 / BALOK-KOLOM

UKURAN SAMBUNGAN: HOLD

D2 / X-KOLOM

UKURAN SAMBUNGAN: HOLD

D3 / IKATAN BETON

UKURAN SAMBUNGAN: HOLD

D4 / RAILING-RANGKA

UKURAN SAMBUNGAN: HOLD

50

100

RHS 50 x 100 x 2,3

t = 2,3 nominal

50

100

RHS 50 x 100 x 2,3

t = 2,3 nominal

50

100

RHS 50 x 100 x 2,3

t = 2,3 nominal

50

100

RHS 50 x 100 x 2,3

t = 2,3 nominal

PENAMPANG RHS RUJUKAN; SKEMA D1-D4 TIDAK DIUKUR UNTUK PRODUKSI

Baut, angkur, gusset dan ukuran las: belum ditetapkan

# S-11 SAMBUNGAN D1-D4

D1 balok-kolom; D2 X-kolom; D3 ikatan ke beton; D4 railing-rangka.
Skema jalur gaya saja. Diameter baut, las, gusset dan angkur lama tidak berlaku otomatis.

# S-12 URUTAN PEMASANGAN

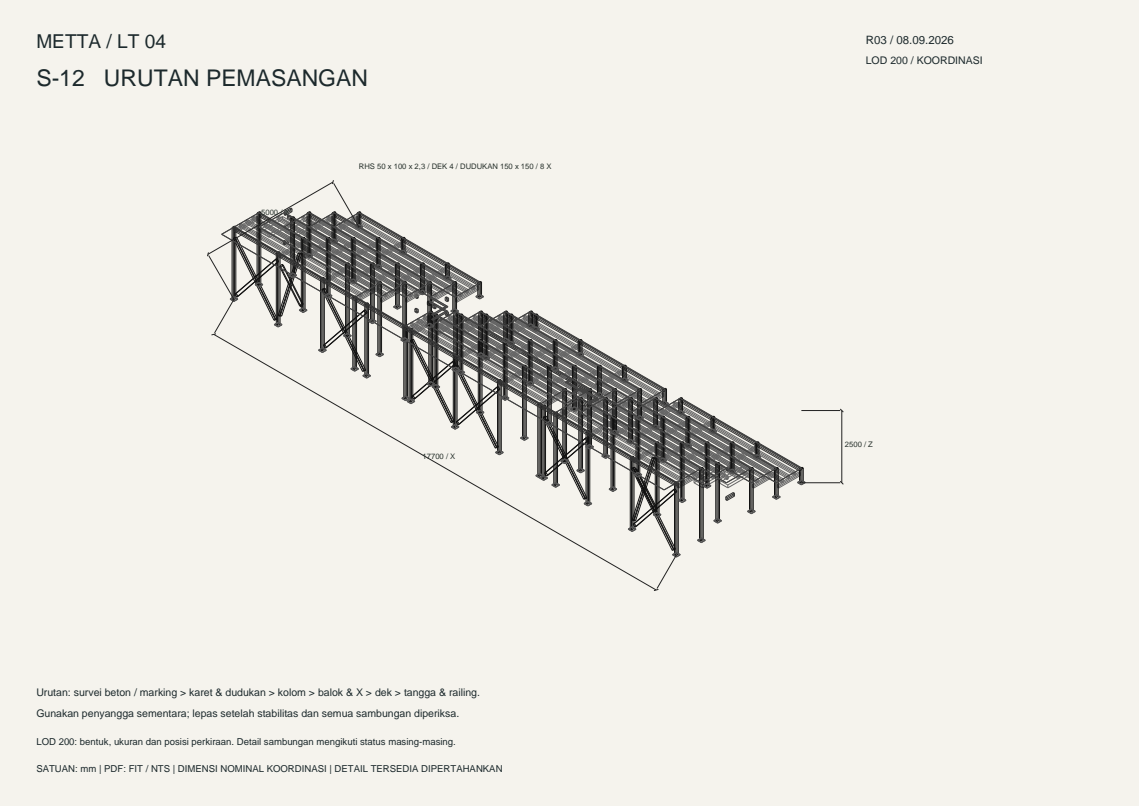
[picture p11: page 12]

RHS 50 x 100 x 2,3 / DEK 4 / DUDUKAN 150 x 150 / 8 X

Urutan: survei beton / marking > karet & dudukan > kolom > balok & X > dek > tangga & railing.
Gunakan penyangga sementara; lepas setelah stabilitas dan semua sambungan diperiksa.

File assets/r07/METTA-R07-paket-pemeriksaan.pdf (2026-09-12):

METTA R07 / UNTUK PEMERIKSAAN INSINYUR - BELUM UNTUK DIPOTONG / DIFABRIKASI | 1

# 01 / Dasar paket dan keputusan

Pilihan Bam:1 A/2 A/3 A. Bentuk, kapasitas dan posisi tangga model METTA tetap; profil dan sambungan boleh diperbaiki. Data lapangan belum lengkap. Insinyur struktur memeriksa sebelum fabrikasi.

R 07 adalah paket pemeriksaan menuju fabrikasi dan serah terima, bukan gambar yang telah disetujui untuk diproduksi. Jumlah pesanan final menunggu perubahan desain, pengukuran dan persetujuan tertulis.

Model kuantitas: pembacaan 545 elemen pada 11 September 2026;945 parameter cocok. Geometri penutup/pelat tangga masih arsip. Koordinat gambar memakai sumbu lokal tribun, bukan datum setting-out gedung.

Angka kapasitas orang tidak ditebak dari luas dek; pemilik/arsitek harus mencatat kapasitas yang disetujui tanpa menaikkannya.

METTA R07 / UNTUK PEMERIKSAAN INSINYUR - BELUM UNTUK DIPOTONG / DIFABRIKASI | 2

# 02 / Putusan 54 atau 101 batang

54 batang adalah 1620 kg Excel/30 kg perbatang, bukan daftar potong.54 x 6 m hanya 324 m. Model RHS saja memerlukan 552,30 m dan pola 97 batang; model+usulan 590,14 m memakai pola 101 batang.97 dan 101 adalah pola layak, bukan minimum global terbukti.

Gunakan 101 hanya sebagai acuan anggaran lingkup lengkap saat ini. Jangan memesan 54 untuk memenuhi model ini. Jangan memotong 101 sebelum revisi sambungan/tangga/railing dikunci.

Berat katalog RHS 50 x 100 x 2,3:32,5 kg/6 m.30 kg dari Bam adalah pembagi Excel, bukan hasil timbang. Jika produk aktual berbeda, cocokkan sertifikat dan dimensi, lalu revisi berat dan analisis; jangan mengganti kg/batang saja tanpa pemeriksaan produk.

Lingkup | Potongan | Panjang m | Batang6m | Kg pembelian
Excel / konversi | Tidak tersedia | 324 | 54 | 1620
Model RHS | 245 | 552,30 | 97 | 3152.5
Model R HS+usu lan | 361 | 590,14 | 101 | 3282.5

METTA R07 / UNTUK PEMERIKSAAN INSINYUR - BELUM UNTUK DIPOTONG / DIFABRIKASI | 3

# 03 / Hitungan struktur dan keputusan profil

Acuan kerja pemeriksaan: RHS 50 x 100 x 2,3 dipertahankan untuk rangka utama. Pilihan 1,6 seluruh rangka tidak diteruskan sebagai desain pelaksanaan karena balok silang tidak lolos screen.2,0 memiliki margin lebih kecil; penghematan campuran tetap alternatif, bukan defaultfabrikasi.

Asumsi R 06: E 200000 MPa,Fy 235 MPa,Fu 370 MPa,D 1,5 k Pa,L 5 k Pa,faktor tebal 0,93 sebagai sensitivitas. Beban dan faktor tebal harus dikonfirmasi terhadap kategori penggunaan serta standar produk nyata.

Beam sederhana: Mu=qu L^2/8; Vu=qu L/2; delta=5 q L^4/(384 EI). Untuk titik: Mu=PL/4; delta=PL^3/(48 EI). Rasio adalah maksimum pemeriksaan kapasitas/lendutan yang dihitung. Sambungan/tumpuan ideal pada screen belum membuktikan kekakuan nyata.

Luasdek 82,35 m 2; D 123,52 k N; L 411,73 k N; kombinasi 1,2 D+1,6 L=806,98 k N untuk asumsi ini. Reaksi tidak boleh dibagi rata ke 80 dudukan.

Masih wajib diselesaikan: rangka 3 D/stabilitas/P-delta, gaya bracing dan diafragma, gempa LT 4, lantai/angkur beton, getaran global/ritmis, jalur beban tangga dan pagar. R 06 memuat hitungan lokal untuk bahan review; bukan sertifikat kepatuhan menyeluruh.

Versi | Rasio pengaku | Rasio balok silang | Hasil terbatas
model-existing | 0,406 | 0,834 | Lolos screen lokal
h 20-existing | 0,460 | 0,945 | Lolos screen lokal
h 16-existing | 0,564 | 1,158 | Tidak lolos screen lokal

METTA R07 / UNTUK PEMERIKSAAN INSINYUR - BELUM UNTUK DIPOTONG / DIFABRIKASI | 4

# 04 / Revisi kritis sebelum fabrikasi

Tiangrailing 40 x 40 tidak lolos screen kantilever 1,1 m, bahkan 2,8 mm.60 x 60 x 2,3 adalah kandidat lokal untuk dikaji, belum pengganti yang disetujui. Base, isian, railhorizontal, celah dan akses harus diperiksa bersama.

Jarak kolom tidak otomatis diubah 1770 menjadi 1000. Model memiliki jarak bervariasi sampai 2040 pada sumbu inti; infill dapat bertabrakan dengan tangga dan menambah tumpuan pada lantai. Bentuk/kapasitas tetap, revisi hanya setelah analisis dan cek lapangan.

Setiap perubahan profil/sambungan mengubah daftar bahan, panjang potong, kg dan harga. Paket ini mempertahankan BOQ acuan agar delta perubahan dapat ditelusuri, bukan menganggap semua item sudah cocok untuk fabrikasi.

Tiang | Tebal mm | Rasio lentur | Lendutan mm | Hasil lokal
40 x 40 | 2.3 | 2,026 | 27,00 | Tidak lolos
40 x 40 | 2.8 | 1,751 | 23,34 | Tidak lolos
60 x 60 | 2.3 | 0,834 | 7,41 | Kandidat diperiksa

METTA R07 / UNTUK PEMERIKSAAN INSINYUR - BELUM UNTUK DIPOTONG / DIFABRIKASI | 5
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

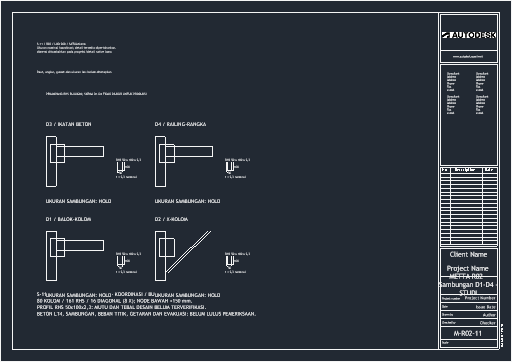
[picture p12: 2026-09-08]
assets/technical/revit/S-11.png

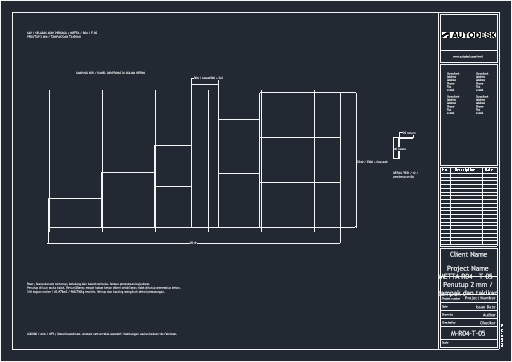
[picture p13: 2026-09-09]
assets/r04/revit/T-05.png

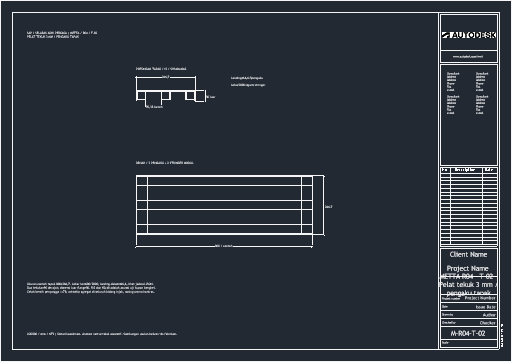
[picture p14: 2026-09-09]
assets/r04/revit/T-02.png

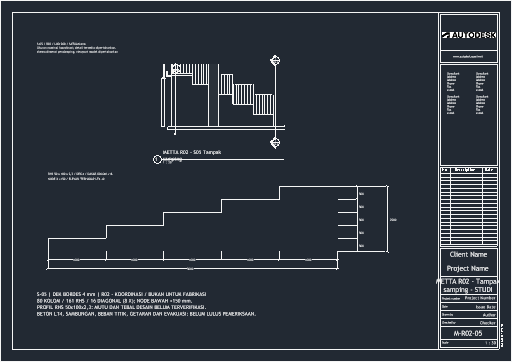
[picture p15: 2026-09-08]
assets/technical/revit/S-05.png

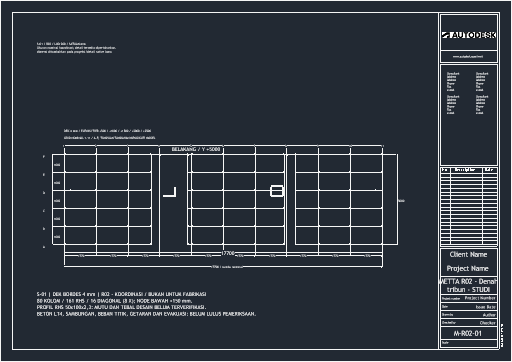
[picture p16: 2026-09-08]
assets/technical/revit/S-01.png

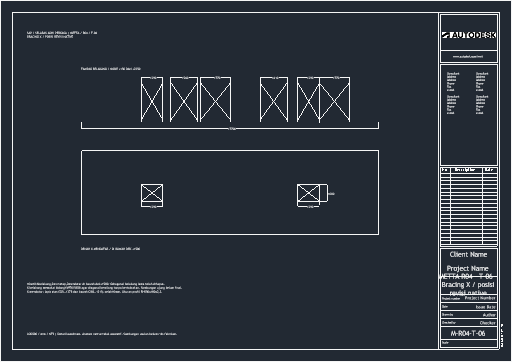
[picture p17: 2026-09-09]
assets/r04/revit/T-06.png

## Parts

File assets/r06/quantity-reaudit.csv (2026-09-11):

id | name | unit | excel_qty | excel_unit | net_qty | purchase_qty | verification | basis
X01 | Kolom tribun | kg | 637 | Kg | 686.95870361 | 738.94659187 | Panjang model dibaca ulang; kg bersih penampang, kg beli katalog | 80 elemen; panjang 133.559800 m. Berat pembelian dialokasikan dari stok bersama menurut panjang potongan pada setiap batang.
X02 | Balok tepi tier | kg | 416 | Kg | 379.12400549 | 409.49441845 | Panjang model dibaca ulang; kg bersih penampang, kg beli katalog | 15 elemen; panjang 73.710000 m. Berat pembelian dialokasikan dari stok bersama menurut panjang potongan pada setiap batang.
X03 | Pengaku longitudinal dek | kg | 416 | Kg | 1162.77553756 | 1243.32282044 | Panjang model dibaca ulang; kg bersih penampang, kg beli katalog | 45 elemen; panjang 226.069001 m. Berat pembelian dialokasikan dari stok bersama menurut panjang potongan pada setiap batang.
X04 | Rangka belakang | kg | 98 | Kg | 89.47552821 | 95.11486506 | Panjang model dibaca ulang; kg bersih penampang, kg beli katalog | 4 elemen; panjang 17.396000 m. Berat pembelian dialokasikan dari stok bersama menurut panjang potongan pada setiap batang.
X05 | Strut ke kolom beton | kg | 53 | Kg | 11.17157882 | 11.8546678 | Panjang model dibaca ulang; kg bersih penampang, kg beli katalog | 16 elemen; panjang 2.171999 m. Berat pembelian dialokasikan dari stok bersama menurut panjang potongan pada setiap batang. Angkur dan pelat ikatan beton dihitung pada item tersendiri.
X06 | Bracing X | kg | 62 | Kg | 218.02073262 | 235.69913457 | Panjang model dibaca ulang; kg bersih penampang, kg beli katalog | 20 elemen; panjang 42.388000 m. Berat pembelian dialokasikan dari stok bersama menurut panjang potongan pada setiap batang.
B01 | Balok silang penumpu dek | kg |  |  | 293.2077378 | 314.04168361 | Panjang model dibaca ulang; kg bersih penampang, kg beli katalog | 65 elemen; panjang 57.005998 m. Berat pembelian dialokasikan dari stok bersama menurut panjang potongan pada setiap batang.
B02 | Penyangga tangga / usulan | kg |  |  | 194.61493102 | 234.02581821 | Usulan atau allowance; aritmetika diperiksa, kebutuhan final belum ditetapkan | 116 elemen; panjang 37.837400 m. Berat pembelian dialokasikan dari stok bersama menurut panjang potongan pada setiap batang. Penyangga belum menjadi elemen native dan jalur tumpuannya belum final.
X07 | Rail atas / elemen horizontal | kg | 435 | Kg | 19.4250817 | 30.14 | Panjang model dibaca ulang; kg bersih penampang, kg beli katalog | 10 elemen; 8.425400 m; 2 stok ×6 m. Family aktif masih M_W Shapes; volume family tidak dipakai sebagai berat hollow.
X08 | Tiang railing dan pegangan | kg | 313 | Kg | 303.42811106 | 379.8 | Panjang model dibaca ulang; kg bersih penampang, kg beli katalog | 85 elemen; 97.498388 m; 18 stok. Harga 2,8 mm mengikuti katalog R04 karena spesifikasi Excel 2 mm berbeda.
X09 | Pelat dek | kg | 2850 | Kg | 2585.63454241 | 2893.824 | Jumlah/luas/volume model dibaca ulang; stok atau allowance dihitung terpisah | Area 30 floor=82.345049121 m²; pembelian 32 lembar 1200×2400, allowance 10%. Berat motif bordes belum terukur.
X10 | Riser, fascia dan return | kg | 1000 | Kg | 733.46923624 | 872.08933196 | Geometri dan pola potong arsip; bukan pembacaan ulang semua pelat native | Luas 46.717786 m². Alokasi proporsional dari 26 lembar bersama penutup sisi; bukan tambahan terhadap 26 lembar. Stok tepat 1200×2400 mm, t=2 mm; 26 lembar bersama = 1175.616 kg teoritis (7850 kg/m³). Bukan berat timbang; bukan lembar 4×8 kaki.
X11 | Pelat tekuk tangga | kg | 982 | Kg | 375.88520065 | 542.592 | Geometri dan pola potong arsip; bukan pembacaan ulang semua pelat native | 56 bidang/176 bagian native;8 lembar. Penyangga RHS dan pengaku SHS dipisah agar tidak terhitung dua kali. Stok tepat 1200×2400 mm, t=3 mm; 8 lembar bersama = 542.592 kg teoritis (7850 kg/m³). Bukan berat timbang; bukan lembar 4×8 kaki.
B03 | Pengaku tapak tangga / usulan | kg |  |  | 329.69194673 | 406.89 | Usulan atau allowance; aritmetika diperiksa, kebutuhan final belum ditetapkan | 143.000000 m dari usulan pengaku tapak;27 stok. Belum menjadi rangka native.
X12 | Penutup kedua sisi | kg | 104 | Kg | 255.28058333 | 303.52666804 | Geometri dan pola potong arsip; bukan pembacaan ulang semua pelat native | Luas 16.259910 m²; bagian dari total 26 lembar penutup. Belakang dan bawah terbuka. Stok tepat 1200×2400 mm, t=2 mm; 26 lembar bersama = 1175.616 kg teoritis (7850 kg/m³). Bukan berat timbang; bukan lembar 4×8 kaki.
X13 | Base plate | kg | 187 | Kg | 113.04 | 180.864 | Jumlah/luas/volume model dibaca ulang; stok atau allowance dihitung terpisah | 80 dudukan; satu stok 1200×2400×8 mm = 180,864 kg teoritis; sisa stok termasuk sekali. Stok tepat 1200×2400 mm, t=8 mm; 1 lembar bersama = 180.864 kg teoritis (7850 kg/m³). Bukan berat timbang; bukan lembar 4×8 kaki.
X14 | Pelat sambungan rangka, tangga dan buhul | kg | 700 | kg | 590.14416 | 678.24 | Usulan atau allowance; aritmetika diperiksa, kebutuhan final belum ditetapkan | 5 lembar 1200×2400×6 mm = 678,24 kg teoritis. Potongan tetap: 232 pasangan kupingan tangga + 274 pasangan rangka 90×120 mm + 40 buhul 200×200 mm. Pola potong 1052 bagian, tepi 10 mm dan celah potong 3 mm sudah diperiksa. Tarif/kg dari Excel. Stok tepat 1200×2400 mm, t=6 mm; 5 lembar bersama = 678.240 kg teoritis (7850 kg/m³). Bukan berat timbang; bukan lembar 4×8 kaki.
X15 | Baut rangka dan X | bh | 693 | bh | 660.0 | 693.0 | Usulan atau allowance; aritmetika diperiksa, kebutuhan final belum ditetapkan | 165 framing termasuk 20 diagonal;2 ujung x 2 baut +5%cadangan. Menggantikan komponen baut paket M14; bagian yang dilas dikurangi setelah joint ditetapkan. Baut, mur dan ring adalah komponen terpisah.
X17 | Mur rangka dan X | bh | 693 | bh | 660.0 | 693.0 | Usulan atau allowance; aritmetika diperiksa, kebutuhan final belum ditetapkan | Satu mur per baut M14 B; bukan tambahan terhadap paket M14 lama. Baut, mur dan ring adalah komponen terpisah.
X18 | Ring rangka dan X | bh | 1386 | bh | 1320.0 | 1386.0 | Usulan atau allowance; aritmetika diperiksa, kebutuhan final belum ditetapkan | Dua ring per baut M14 B; paket M14 lama dihapus agar tidak dihitung ganda. Baut, mur dan ring adalah komponen terpisah.
B04 | Baut tangga | bh |  |  | 464.0 | 488.0 | Usulan atau allowance; aritmetika diperiksa, kebutuhan final belum ditetapkan | 232 titik x 2 baut +5% cadangan; grip 2 pelat 6 mm, verifikasi panjang. Baut, mur dan ring adalah komponen terpisah.
B05 | Mur tangga | bh |  |  | 464.0 | 488.0 | Usulan atau allowance; aritmetika diperiksa, kebutuhan final belum ditetapkan | Satu mur per baut; sudah terpisah dari harga batang baut. Baut, mur dan ring adalah komponen terpisah.
B06 | Ring tangga | bh |  |  | 928.0 | 976.0 | Usulan atau allowance; aritmetika diperiksa, kebutuhan final belum ditetapkan | Dua ring per baut. Baut, mur dan ring adalah komponen terpisah.
X16 | Ikatan ke kolom beton / cadangan | ls | 32 | bh | 1.0 | 1.0 | Usulan atau allowance; aritmetika diperiksa, kebutuhan final belum ditetapkan | Mengganti hitungan 32 dynaboltM10 yang belum terverifikasi. Anggaran R04 untuk 16 titik termasuk desain, pelat, angkur dan pemasangan; bukan jumlah angkur final.
X19 | Sekrup kayu ke baja + ring | set | 500 | bh | 500.0 | 500.0 | Usulan atau allowance; aritmetika diperiksa, kebutuhan final belum ditetapkan | Papan 40 mm ke RHS2,3 mm;500 set allowance. Tipe wood-to-steel, kapasitas bor dan panjang ulir harus sesuai katalog produsen; ukuran 65 mm adalah usulan pengadaan, bukan stok terkonfirmasi.
X20 | Sekrup penutup + ring EPDM | set | 2449 | bh | 2332.0 | 2449.0 | Usulan atau allowance; aritmetika diperiksa, kebutuhan final belum ditetapkan | 234 panel vertikal, kisi perimeter<=300 mm, inset 15 mm: 2332 titik +5%cadangan. Return dan potongan kecil dilas. Panel 2 mm + RHS2,3 mm: minta kapasitas bor minimal 4,3 mm dan data pull-out. Ukuran 32 mm usulan, stok belum dikonfirmasi.
X21 | Karet dudukan | bh | 100 | bh | 80.0 | 80.0 | Jumlah/luas/volume model dibaca ulang; stok atau allowance dihitung terpisah | 80 dudukan aktif; satu karet per base plate.
X22 | Papan pinus dudukan | m | 200 | m1 | 74.81351575 | 82.29486733 | Jumlah/luas/volume model dibaca ulang; stok atau allowance dihitung terpisah | Volume 15 floor=1.197016252 m³ ÷(0,4×0,04); pembelian+10%. Bukan 200 m tanpa dasar geometri.
X23 | Panel kayu sandaran | m | 20 | m1 | 18.225 | 20.0475 | Usulan atau allowance; aritmetika diperiksa, kebutuhan final belum ditetapkan | Luas 7,29 m² dari geometri arsip, bukan hasil ukur Revit baru. Pembelian+10%. Koreksi label 400×40 cm menjadi lebar 400 mm/tebal 40 mm.
X24 | Cat dan coating baja | m² | 8253 | kg | 626.05615443 | 626.05615443 | Usulan atau allowance; aritmetika diperiksa, kebutuhan final belum ditetapkan | Estimasi permukaan 626.0562 m²; nilai paket cat Excel Rp 28,885,500 dibagi luas. Penipisan hollow tidak mengurangi luas cat. Tarif ini normalisasi paket Excel, bukan harga/m² pemasok.
E01 | Backing penutup dan hardware railing | ls |  |  | 1.0 | 1.0 | Usulan atau allowance; aritmetika diperiksa, kebutuhan final belum ditetapkan | Cadangan material backing/tab penutup, kupingan railing dan penyambung rel yang belum terukur. Di luar SDS M16 dan sekrup kayu M15. Berat belum masuk dasar jasa; sesuaikan saat detail dirilis.
E02 | Sistem antiselip tangga | m2 |  |  | 15.0 | 15.0 | Usulan atau allowance; aritmetika diperiksa, kebutuhan final belum ditetapkan | Sistem agregat antiselip di atas pelat polos; material dan pemasangan spesialis termasuk, pola nosing kontras.
E03 | Clear coat kayu | L |  |  | 19.0 | 19.0 | Usulan atau allowance; aritmetika diperiksa, kebutuhan final belum ditetapkan | Dua sisi bidang utama,2 lapis,10 m 2/L,25%loss; belum mengurangi bidang tertutup.
E04 | Jasa tekuk pelat | tekuk |  |  | 112.0 | 112.0 | Usulan atau allowance; aritmetika diperiksa, kebutuhan final belum ditetapkan | 112 tekukan; mesin bengkel vendor, di luar tarif las/ereksi.
EL01 | Angkut bengkel-lokasi + bongkar | rit |  |  | 2.0 | 2.0 | Usulan atau allowance; aritmetika diperiksa, kebutuhan final belum ditetapkan | Bukan ongkir toko-bengkel; ukuran truk/jam akses diverifikasi.
EL02 | Hoist dan alat angkat LT4 | hari |  |  | 7.0 | 7.0 | Usulan atau allowance; aritmetika diperiksa, kebutuhan final belum ditetapkan | Allowance 7 hari, kapasitas/jalur angkat ditentukan metode kerja.
EL03 | Perancah dan penyangga sementara | ls |  |  | 1.0 | 1.0 | Usulan atau allowance; aritmetika diperiksa, kebutuhan final belum ditetapkan | Sewa, pengiriman dan pembongkaran.
EL04 | Pengukuran + kontrol mutu las/cat | ls |  |  | 1.0 | 1.0 | Usulan atau allowance; aritmetika diperiksa, kebutuhan final belum ditetapkan | Allowance ukur, inspeksi visual, DFT dan dokumentasi. Tidak termasuk uji beton laboratorium.
EL05 | Pembersihan, APD dan proteksi | ls |  |  | 1.0 | 1.0 | Usulan atau allowance; aritmetika diperiksa, kebutuhan final belum ditetapkan | Area LT4, alat keselamatan kerja dan serah terima.
EL06 | Verifikasi desain + investigasi tumpuan | ls |  |  | 1.0 | 1.0 | Usulan atau allowance; aritmetika diperiksa, kebutuhan final belum ditetapkan | Provisional sum pemeriksaan insinyur dan pengumpulan data beton; lingkup lab mengikuti temuan.

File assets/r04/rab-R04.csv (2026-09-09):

Kode | Kategori | Uraian | Volume | Satuan | Harga | Jumlah | Basis | Status | Sumber | Pemasok | Spesifikasi | Dasar harga
M01 | Material | RHS 50x100x2,3 / 6 m | 101 | btg | 434500 | 43884500 | Rangka native165 termasuk20diagonal + kolom80 + usulan stringer tangga; pola potong gabungan FFD. | Katalog / penyangga tangga usulan | https://www.smsperkasa.com/produk/besi-hollow-hitam
M02 | Material | SHS 40x40x2 / 6 m | 29 | btg | 194800 | 5649200 | 27 stok pengaku tapak + 2 stok rail atas 8,425 m. | Katalog | https://www.smsperkasa.com/produk/besi-hollow-hitam
M03 | Material | SHS 40x40x2,8 / 6 m | 18 | btg | 277000 | 4986000 | 85 tiang railing 97,498 m + pembulatan dan sisa. | Katalog | https://www.smsperkasa.com/produk/besi-hollow-hitam
M04 | Material | Bordes dek 4 mm / 1200x2400 | 32 | lbr | 1273000 | 40736000 | 82,345 m2 + allowance nesting 10%; motif belum ditimbang. | Harga acuan 07.09; nesting allowance | https://dutamerpati.com/distributor/plat-bordes-40mm-1200x-2400-di-babat
M05 | Material | Pelat tekuk tangga 3 mm / 1200x2400 | 8 | lbr | 860000 | 6880000 | 56 blank; 16.484 m2; 2 tekukan 50 mm. Pola nesting tersedia. | Katalog 4x8; pesan usable >=1200x2400 | https://www.smsperkasa.com/produk/plat-besi-hitam
M06 | Material | Pelat penutup seluruh riser dan sisi 2 mm | 26 | lbr | 578000 | 15028000 | 310panel; 62.977696m2; nesting kerf3mm, trim10mm; belakang/bawah terbuka. | Katalog / dimensi usulan | https://www.smsperkasa.com/produk/plat-besi-hitam
M07 | Material | Pelat sambungan 6 mm | 5 | lbr | 1756000 | 8780000 | 232pasangan kupingan tangga +274pasangan rangka90x120 +40buhul200x200; cadangan10%.16ikatan beton tercakup M17. | Katalog / sambungan usulan | https://www.smsperkasa.com/produk/plat-besi-hitam
M08 | Material | Base plate 8 mm / stok | 1 | lbr | 2187000 | 2187000 | 80 x150x150; sisa stok untuk detail seketebalan. | Katalog | https://www.smsperkasa.com/produk/plat-besi-hitam
M09 | Material | Papan pinus 40 mm + sandaran | 1.637 | m3 | 6500000 | 10640500 | Volume pinus Revit + panel sandaran arsip;10% sisa. Harga budget. | Allowance anggaran
M10 | Material | Karet dudukan 150x150x10 | 80 | bh | 18000 | 1440000 | 80 dudukan, tanpa angkur ke pelat LT4. | Allowance anggaran
M11 | Material | Baut M12 kelas8.8 panjang40 / tangga | 488 | bh | 4500 | 2196000 | 232 titik x2 baut +5% cadangan; grip2pelat6mm, verifikasi panjang. | Usulan spesifikasi / harga estimasi | https://www.sentralmurbaut.com/product-detail?name=hexagonal-bolts-nuts | Sentral Mur Baut Surabaya | Baja karbon; lapis seng untuk pengadaan indoor. Baut kelas8.8, mur kelas8 dan ring keras kompatibel; panjang/grip, sertifikat dan detail joint harus dicocokkan. | Estimasi anggaran per bh; bukan harga penawaran pemasok. Ditinjau 09.09.2026.
M12 | Material | Mur M12 kelas8 / tangga | 488 | bh | 1500 | 732000 | Satu mur per baut; sudah terpisah dari harga batang baut. | Usulan spesifikasi / harga estimasi | https://www.sentralmurbaut.com/product-detail?name=hexagonal-bolts-nuts | Sentral Mur Baut Surabaya | Baja karbon; lapis seng untuk pengadaan indoor. Baut kelas8.8, mur kelas8 dan ring keras kompatibel; panjang/grip, sertifikat dan detail joint harus dicocokkan. | Estimasi anggaran per bh; bukan harga penawaran pemasok. Ditinjau 09.09.2026.
M13 | Material | Ring datar keras M12 / tangga | 976 | bh | 750 | 732000 | Dua ring per baut. | Usulan spesifikasi / harga estimasi | https://www.sentralmurbaut.com/product-detail?name=hexagonal-bolts-nuts | Sentral Mur Baut Surabaya | Baja karbon; lapis seng untuk pengadaan indoor. Baut kelas8.8, mur kelas8 dan ring keras kompatibel; panjang/grip, sertifikat dan detail joint harus dicocokkan. | Estimasi anggaran per bh; bukan harga penawaran pemasok. Ditinjau 09.09.2026.
M14B | Material | Baut hex M12 x40 kelas 8.8 / rangka dan X | 693 | bh | 4500 | 3118500 | 165framing termasuk20diagonal;2ujung x2baut +5%cadangan. Menggantikan komponen baut paket M14; bagian yang dilas dikurangi setelah joint ditetapkan. | Usulan spesifikasi / harga estimasi | https://www.sentralmurbaut.com/product-detail?name=hexagonal-bolts-nuts | Sentral Mur Baut Surabaya | Baja karbon; lapis seng untuk pengadaan indoor. Baut kelas8.8, mur kelas8 dan ring keras kompatibel; panjang/grip, sertifikat dan detail joint harus dicocokkan. | Estimasi anggaran per bh; bukan harga penawaran pemasok. Ditinjau 09.09.2026.
M14N | Material | Mur hex M12 kelas 8 / rangka dan X | 693 | bh | 1500 | 1039500 | Satu mur per baut M14B; bukan tambahan terhadap paket M14 lama. | Usulan spesifikasi / harga estimasi | https://www.sentralmurbaut.com/product-detail?name=hexagonal-bolts-nuts | Sentral Mur Baut Surabaya | Baja karbon; lapis seng untuk pengadaan indoor. Baut kelas8.8, mur kelas8 dan ring keras kompatibel; panjang/grip, sertifikat dan detail joint harus dicocokkan. | Estimasi anggaran per bh; bukan harga penawaran pemasok. Ditinjau 09.09.2026.
M14W | Material | Ring datar keras M12 / rangka dan X | 1386 | bh | 750 | 1039500 | Dua ring per baut M14B; paket M14 lama dihapus agar tidak dihitung ganda. | Usulan spesifikasi / harga estimasi | https://www.sentralmurbaut.com/product-detail?name=hexagonal-bolts-nuts | Sentral Mur Baut Surabaya | Baja karbon; lapis seng untuk pengadaan indoor. Baut kelas8.8, mur kelas8 dan ring keras kompatibel; panjang/grip, sertifikat dan detail joint harus dicocokkan. | Estimasi anggaran per bh; bukan harga penawaran pemasok. Ditinjau 09.09.2026.
M15 | Material | Sekrup drilling wood ke baja #12 x65 + ring / usulan | 500 | set | 1500 | 750000 | Papan40mm ke RHS2,3mm;500set allowance. Tipe wood-to-steel, kapasitas bor dan panjang ulir harus sesuai katalog produsen; ukuran65mm adalah usulan pengadaan, bukan stok terkonfirmasi. | Usulan spesifikasi / harga estimasi | https://www.ptjayametal.com/ | PT Jaya Metal Surabaya | Baja karbon dikeraskan, lapis antikarat; mutu dan kapasitas mengikuti datasheet SDS produsen. Bukan pengganti baut struktural. Jenis produk pemasok tersedia; ukuran dan kapasitas pilihan belum terverifikasi. | Estimasi anggaran per set; bukan harga penawaran pemasok. Ditinjau 09.09.2026.
M16 | Material | Sekrup SDS hex #12 x32 + ring EPDM / usulan | 2449 | set | 800 | 1959200 | 234panel vertikal, kisi perimeter<=300mm, inset15mm: 2332titik +5%cadangan. Return dan potongan kecil dilas. Panel2mm + RHS2,3mm: minta kapasitas bor minimal4,3mm dan data pull-out. Ukuran32mm usulan, stok belum dikonfirmasi. | Usulan spesifikasi / harga estimasi | https://www.ptjayametal.com/ | PT Jaya Metal Surabaya | Baja karbon dikeraskan, lapis antikarat; mutu dan kapasitas mengikuti datasheet SDS produsen. Bukan pengganti baut struktural. Jenis produk pemasok tersedia; ukuran dan kapasitas pilihan belum terverifikasi. | Estimasi anggaran per set; bukan harga penawaran pemasok. Ditinjau 09.09.2026.
M17 | Material | Ikatan ke kolom beton / provisional sum | 1 | ls | 5000000 | 5000000 | Cadangan desain, pelat, angkur dan pemasangan16titik; jumlah/diameter/kapasitas belum dipilih. Tidak ke pelat lantai. | Allowance anggaran
M18 | Material | Cat alkyd 2-in-1 hitam / 2 lapis | 157.5 | L | 130000 | 20475000 | 626.06 m2 x2lapis /10m2/L x1,25loss, bulat2,5L. Menggantikan primer+finish terpisah. | Konsumsi produsen / harga allowance | https://www.nipponpaint-indonesia.com/products/kayu-besi/decorative/bodelac-2-in-1-anti-karat
M19 | Material | Thinner kompatibel + pembersih | 16 | L | 35000 | 560000 | Allowance10%volume cat; pengenceran akhir mengikuti TDS produk. | Allowance anggaran | https://www.tokocatsurabaya.com/
M20 | Material | Sistem antiselip permukaan tangga | 15 | m2 | 125000 | 1875000 | Sistem agregat antiselip di atas pelat polos; material dan pemasangan spesialis termasuk, pola nosing kontras. | Allowance anggaran
M21 | Material | Clear coat kayu | 19 | L | 100000 | 1900000 | Dua sisi bidang utama,2lapis,10m2/L,25%loss; belum mengurangi bidang tertutup. | Allowance anggaran
M22 | Material | Backing penutup dan hardware railing / provisional sum | 1 | ls | 3500000 | 3500000 | Cadangan material backing/tab penutup, kupingan railing dan penyambung rel yang belum terukur. Di luar SDS M16 dan sekrup kayu M15. Berat belum masuk dasar jasa; sesuaikan saat detail dirilis. | Allowance anggaran
C01 | Bahan habis pakai | Elektroda / kawat las kompatibel | 15 | kg | 35000 | 525000 | Panjang las budget233.2m; kaki3mm, efisiensi0,65, starts15%, bulat5kg. WPS memilih proses. | Allowance anggaran
C02 | Bahan habis pakai | Cakram potong | 38 | bh | 18000 | 684000 | Produktivitas budget15potong/cakram. | Allowance anggaran
C03 | Bahan habis pakai | Flap disc + sikat kawat | 53 | set | 28000 | 1484000 | Satu set/12m2 permukaan, allowance persiapan. | Allowance anggaran
C04 | Bahan habis pakai | Mata bor + pelumas | 7 | set | 150000 | 1050000 | 150lubang/set budget, 4lubang/titik pada2pelat. | Allowance anggaran
C05 | Bahan habis pakai | Kuas, roller, masking dan kain | 1 | ls | 850000 | 850000 | Satu paket pekerjaan coating. | Allowance anggaran
C06 | Bahan habis pakai | Listrik bengkel | 500 | kWh | 2000 | 1000000 | Allowance500kWh; termasuk las, gerinda, bor. Tarifbudget. | Allowance anggaran
C07 | Bahan habis pakai | Gas / bahan bantu pemotongan pelat | 1 | ls | 750000 | 750000 | Biaya mesin/laser diletakkan pada upah proses, gas allowance terpisah. | Allowance anggaran
U01 | Upah | Fabrikasi + pemasangan baja | 9662.154 | kg | 6000 | 57972924 | Kesepakatan Bam: berat pembelian stok termasuk sisa; upah potong, las, bor dan ereksi. Consumables terpisah. | Allowance anggaran
U02 | Upah | Jasa press brake | 112 | tekuk | 20000 | 2240000 | 112tekukan; mesin bengkel vendor, di luar tarif las/ereksi. | Allowance anggaran
U03 | Upah | Persiapan permukaan + aplikasi cat baja | 626.0562 | m2 | 25000 | 15651405 | Upah coating terpisah dari tarif fabrikasi. | Allowance anggaran
U04 | Upah | Pemasangan + finishing kayu | 1 | ls | 3500000 | 3500000 | Anggaran tukang kayu; bahan clear coat sudah M21. | Allowance anggaran
L01 | Peralatan dan logistik | Angkut bengkel-lokasi + bongkar | 2 | rit | 1500000 | 3000000 | Bukan ongkir toko-bengkel; ukuran truk/jam akses diverifikasi. | Allowance anggaran
L02 | Peralatan dan logistik | Hoist dan alat angkat LT4 | 7 | hari | 500000 | 3500000 | Allowance 7hari, kapasitas/jalur angkat ditentukan metode kerja. | Allowance anggaran
L03 | Peralatan dan logistik | Perancah dan penyangga sementara | 1 | ls | 2500000 | 2500000 | Sewa, pengiriman dan pembongkaran. | Allowance anggaran
L04 | Peralatan dan logistik | Pengukuran + kontrol mutu las/cat | 1 | ls | 2000000 | 2000000 | Allowance ukur, inspeksi visual, DFT dan dokumentasi. Tidak termasuk uji beton laboratorium. | Allowance anggaran
L05 | Peralatan dan logistik | Pembersihan, APD dan proteksi | 1 | ls | 1500000 | 1500000 | Area LT4, alat keselamatan kerja dan serah terima. | Allowance anggaran
L06 | Peralatan dan logistik | Verifikasi desain + investigasi tumpuan | 1 | ls | 7500000 | 7500000 | Provisional sum pemeriksaan insinyur dan pengumpulan data beton; lingkup lab mengikuti temuan. | Allowance anggaran

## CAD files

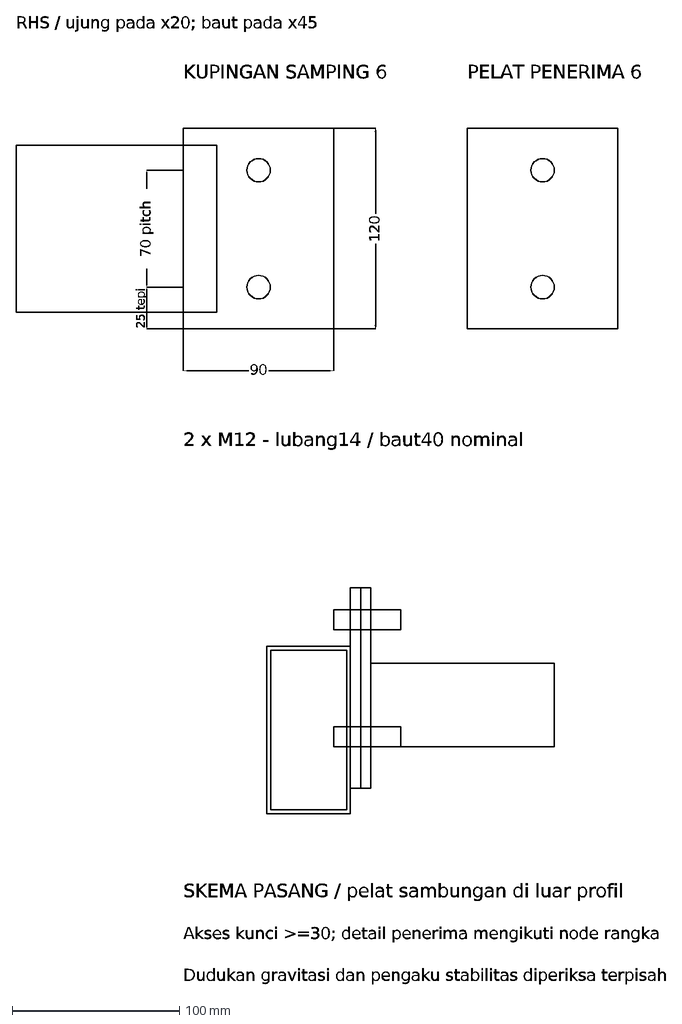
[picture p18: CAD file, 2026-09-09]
assets/r04/T-03.dxf
90
120
70 pitch
25 tepi
RHS / ujung pada x20; baut pada x45
KUPINGAN SAMPING 6
PELAT PENERIMA 6
2 x M12 - lubang14 / baut40 nominal
SKEMA PASANG / pelat sambungan di luar profil
Akses kunci >=30; detail penerima mengikuti node rangka
Dudukan gravitasi dan pengaku stabilitas diperiksa terpisah

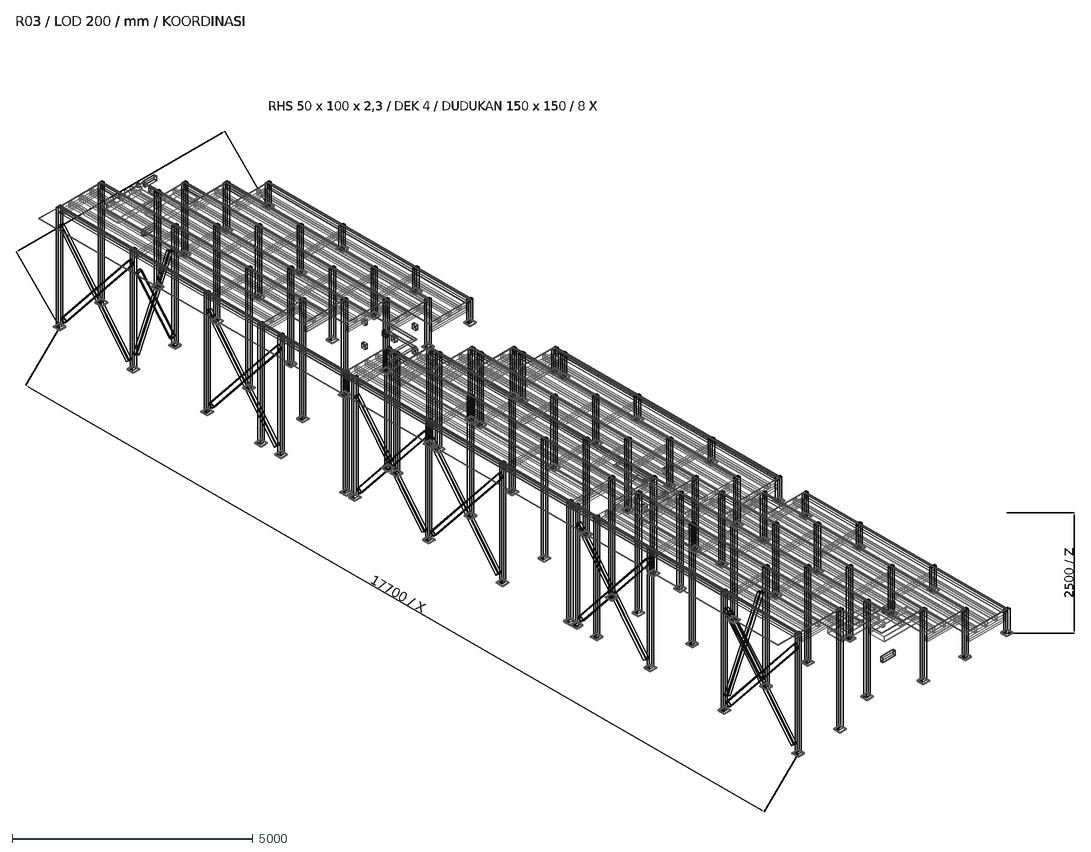
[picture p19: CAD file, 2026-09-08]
assets/technical/S-12.dxf
17700 / X
5000 / Y
2500 / Z
RHS 50 x 100 x 2,3 / DEK 4 / DUDUKAN 150 x 150 / 8 X
R03 / LOD 200 / mm / KOORDINASI

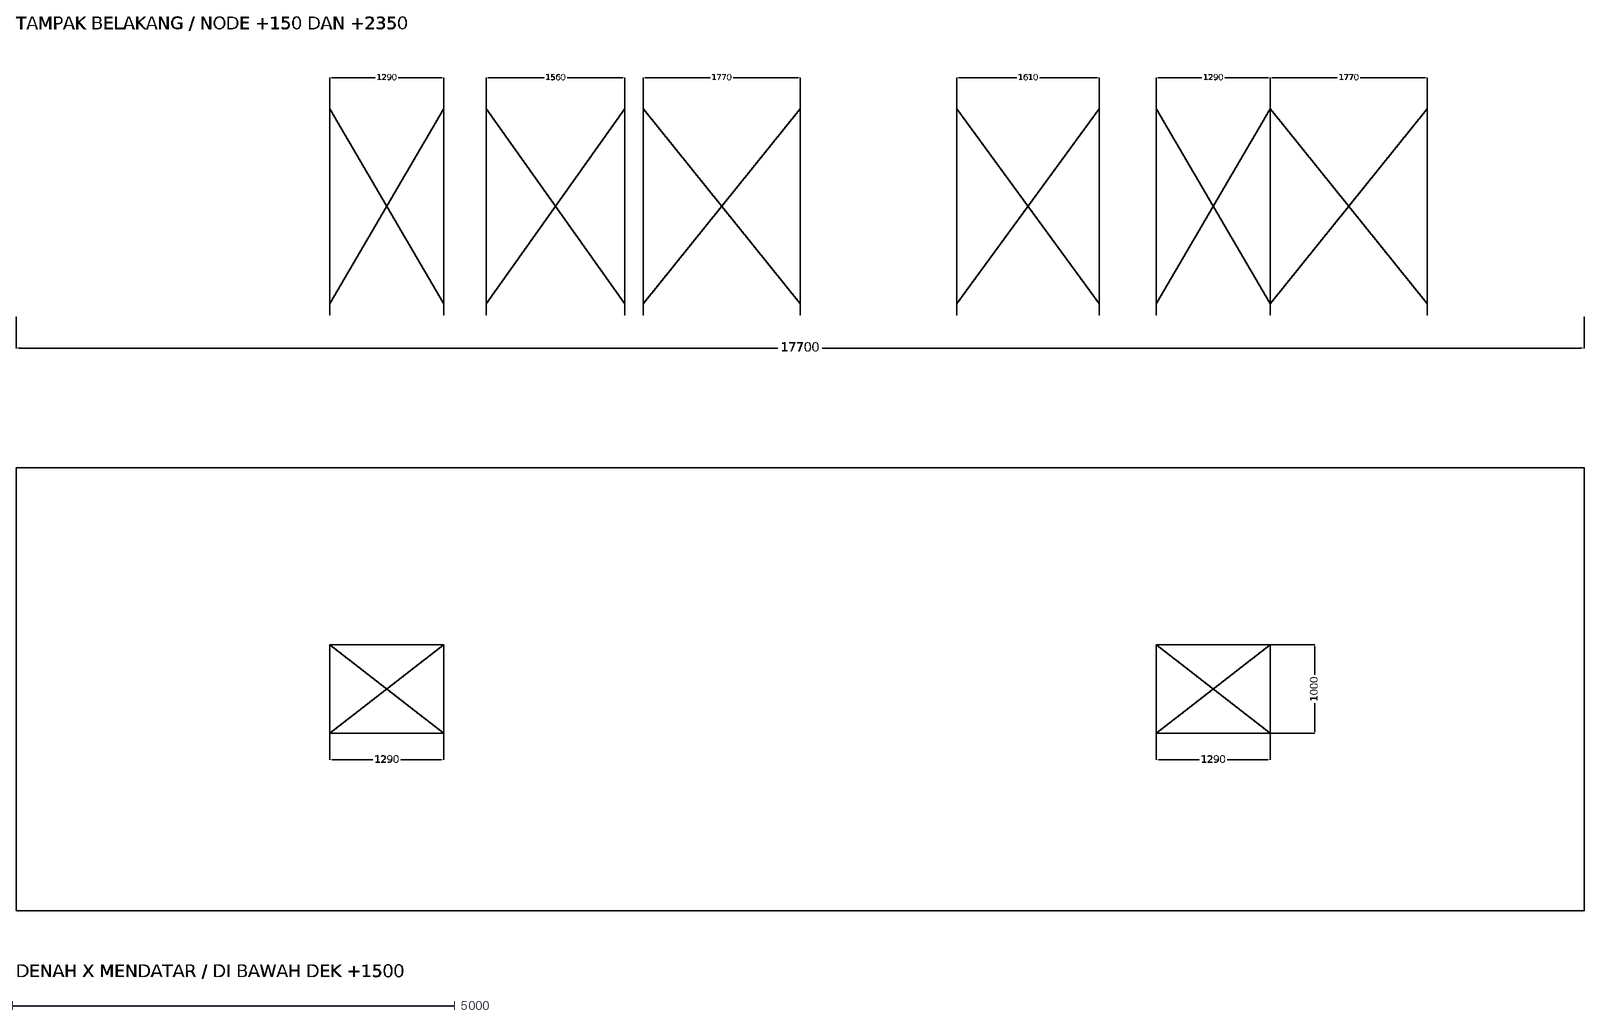
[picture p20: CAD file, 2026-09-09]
assets/r04/T-06.dxf
17700
1290
1560
1770
1610
1000
TAMPAK BELAKANG / NODE +150 DAN +2350
DENAH X MENDATAR / DI BAWAH DEK +1500

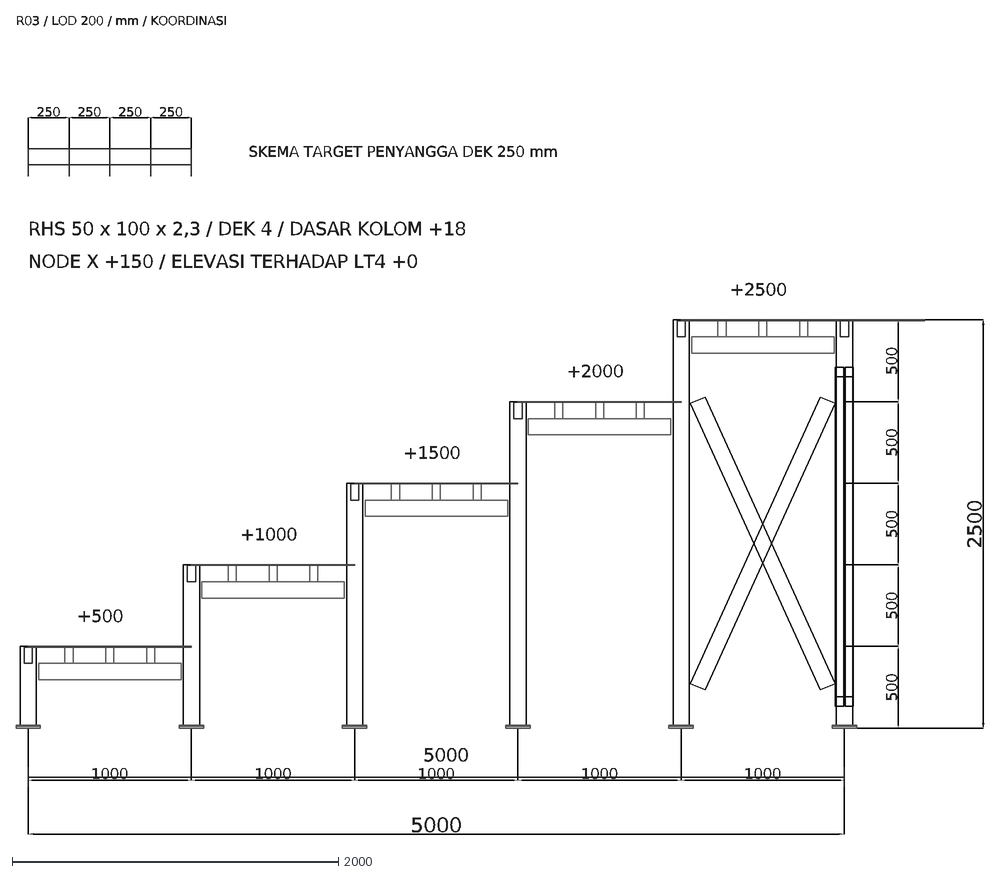
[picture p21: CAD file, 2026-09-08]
assets/technical/S-06.dxf
5000
1000
500
2500
250
+500
+1000
+1500
+2000
+2500
RHS 50 x 100 x 2,3 / DEK 4 / DASAR KOLOM +18
NODE X +150 / ELEVASI TERHADAP LT4 +0
SKEMA TARGET PENYANGGA DEK 250 mm
R03 / LOD 200 / mm / KOORDINASI

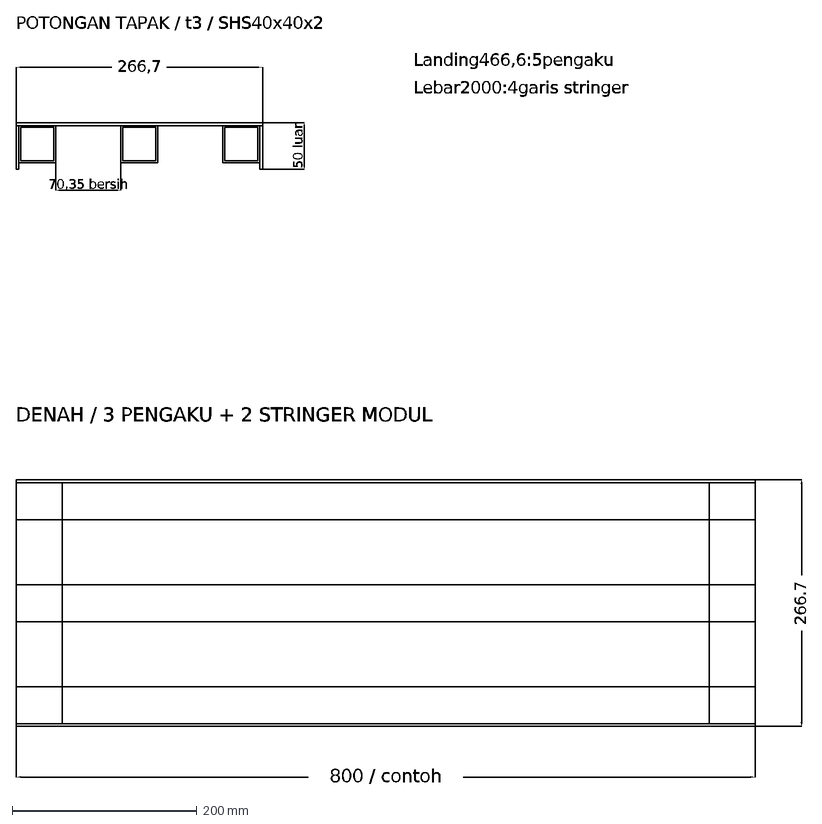
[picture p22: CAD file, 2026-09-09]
assets/r04/T-02.dxf
266,7
50 luar
70,35 bersih
800 / contoh
266.7
POTONGAN TAPAK / t3 / SHS40x40x2
DENAH / 3 PENGAKU + 2 STRINGER MODUL
Landing466,6:5pengaku
Lebar2000:4garis stringer

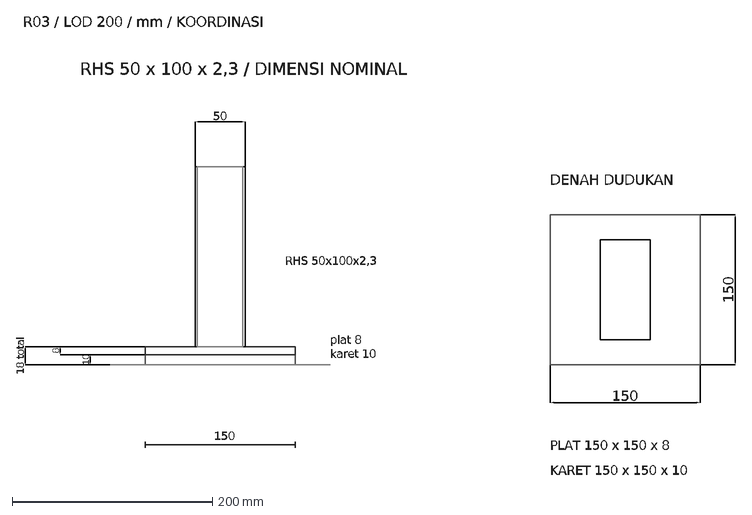
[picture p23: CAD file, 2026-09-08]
assets/technical/S-10.dxf
10
8
18 total
50
150
karet 10
plat 8
RHS 50x100x2,3
DENAH DUDUKAN
PLAT 150 x 150 x 8
KARET 150 x 150 x 10
RHS 50 x 100 x 2,3 / DIMENSI NOMINAL
R03 / LOD 200 / mm / KOORDINASI

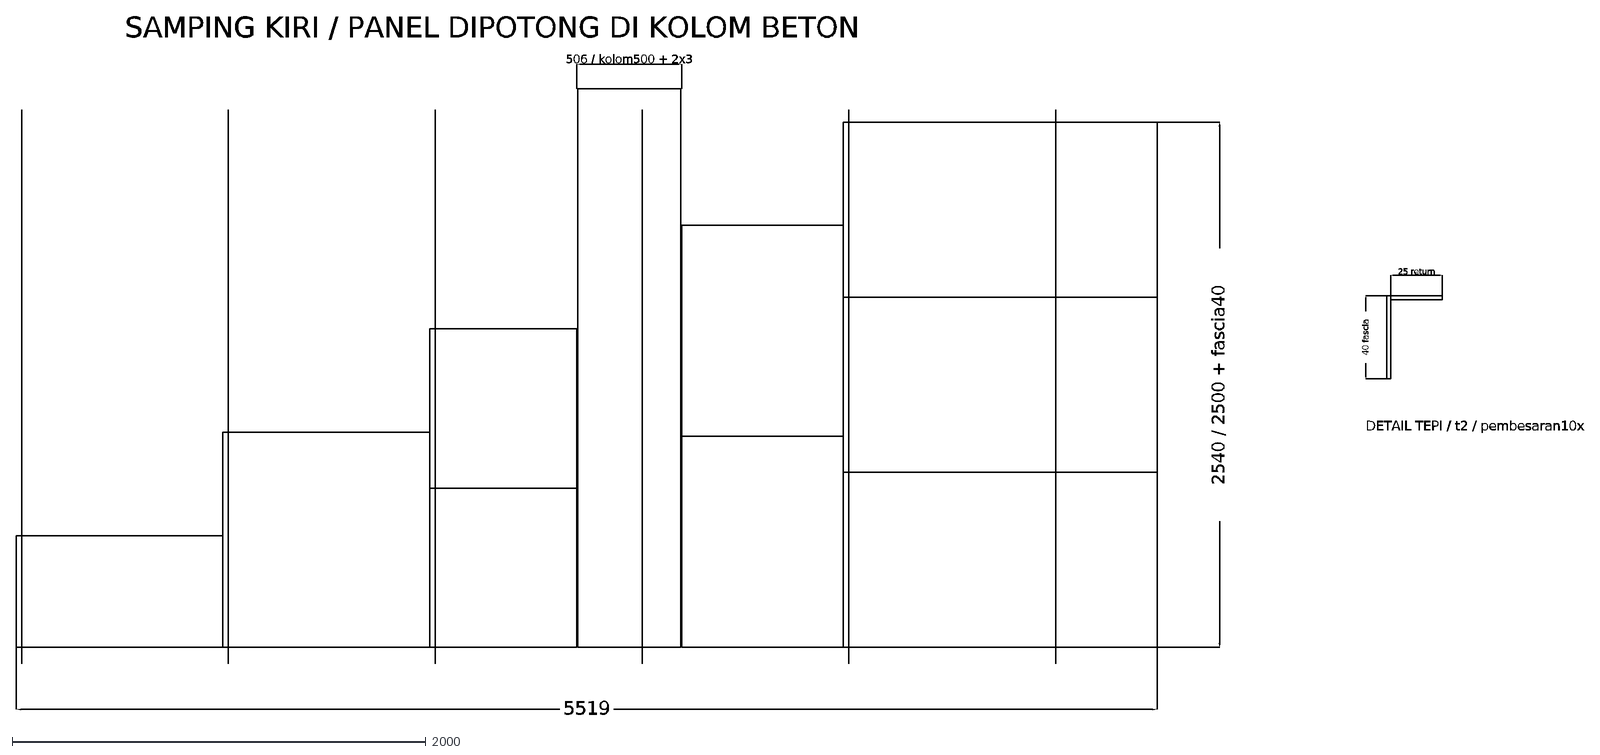
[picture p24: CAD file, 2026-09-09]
assets/r04/T-05.dxf
5519
2540 / 2500 + fascia40
506 / kolom500 + 2x3
40 fascia
25 return
SAMPING KIRI / PANEL DIPOTONG DI KOLOM BETON
DETAIL TEPI / t2 / pembesaran10x

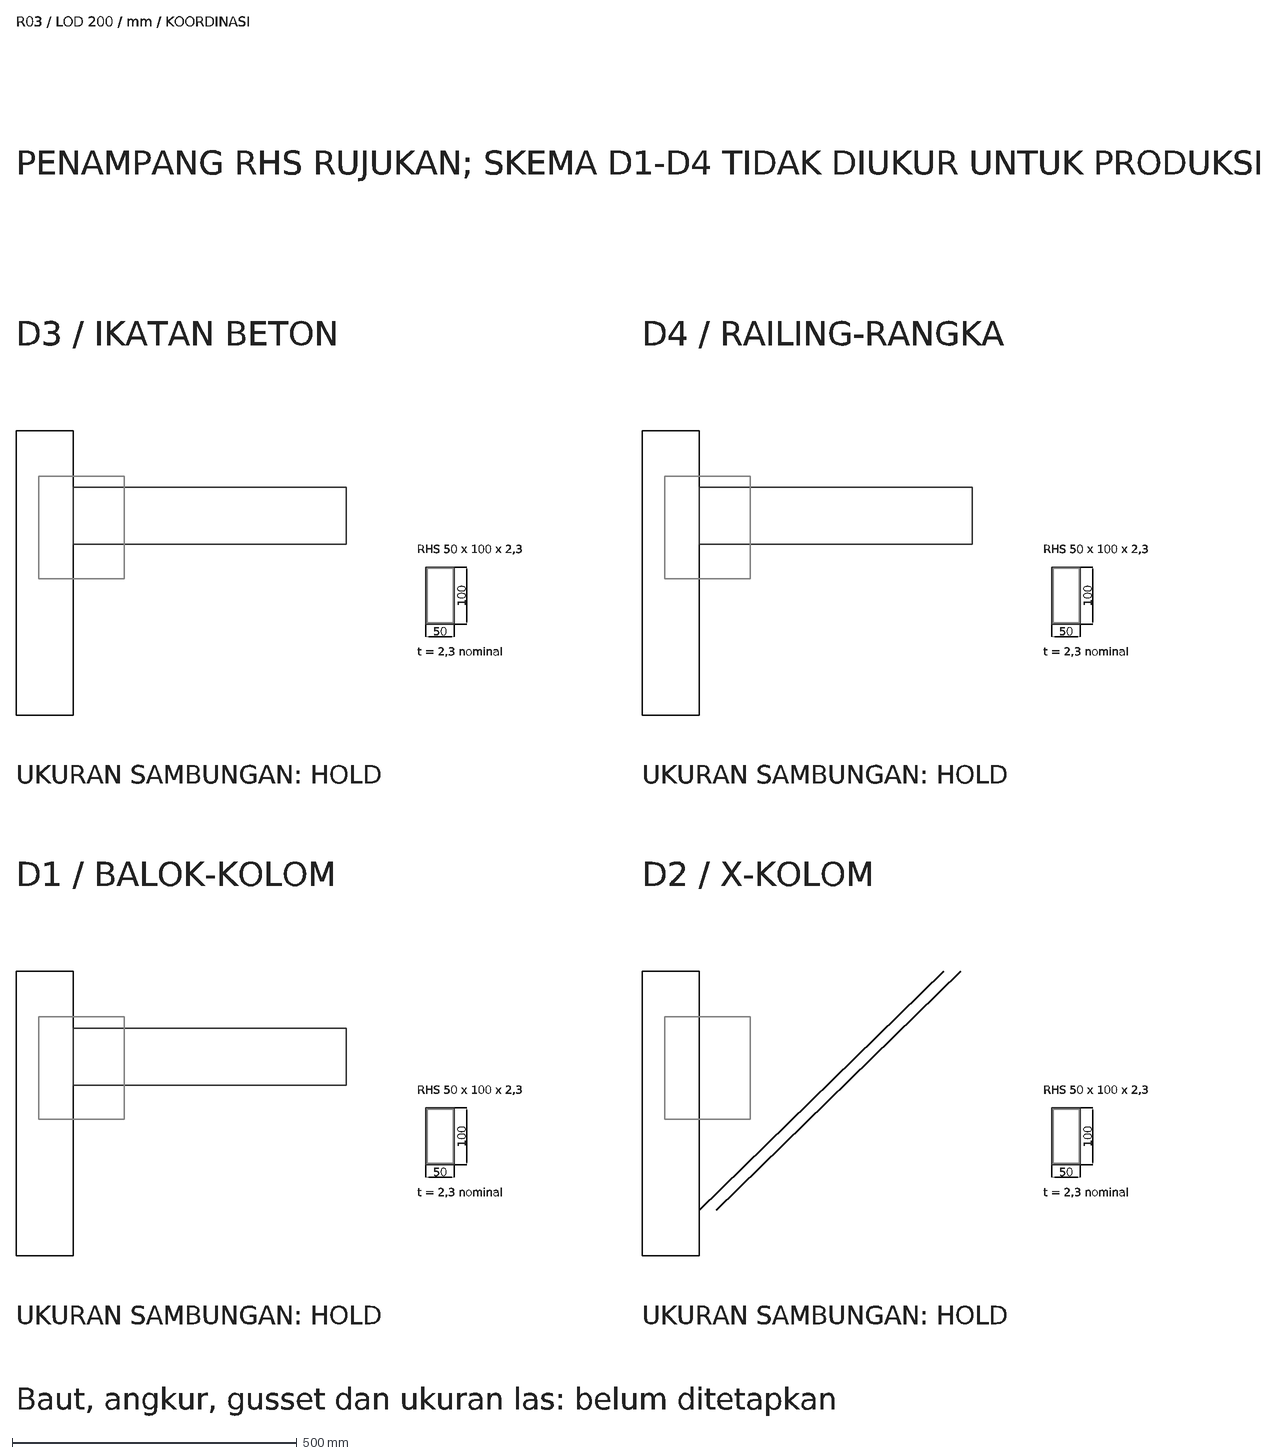
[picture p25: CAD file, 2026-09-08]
assets/technical/S-11.dxf
50
100
D1 / BALOK-KOLOM
UKURAN SAMBUNGAN: HOLD
D2 / X-KOLOM
D3 / IKATAN BETON
D4 / RAILING-RANGKA
RHS 50 x 100 x 2,3
t = 2,3 nominal
PENAMPANG RHS RUJUKAN; SKEMA D1-D4 TIDAK DIUKUR UNTUK PRODUKSI
Baut, angkur, gusset dan ukuran las: belum ditetapkan
R03 / LOD 200 / mm / KOORDINASI

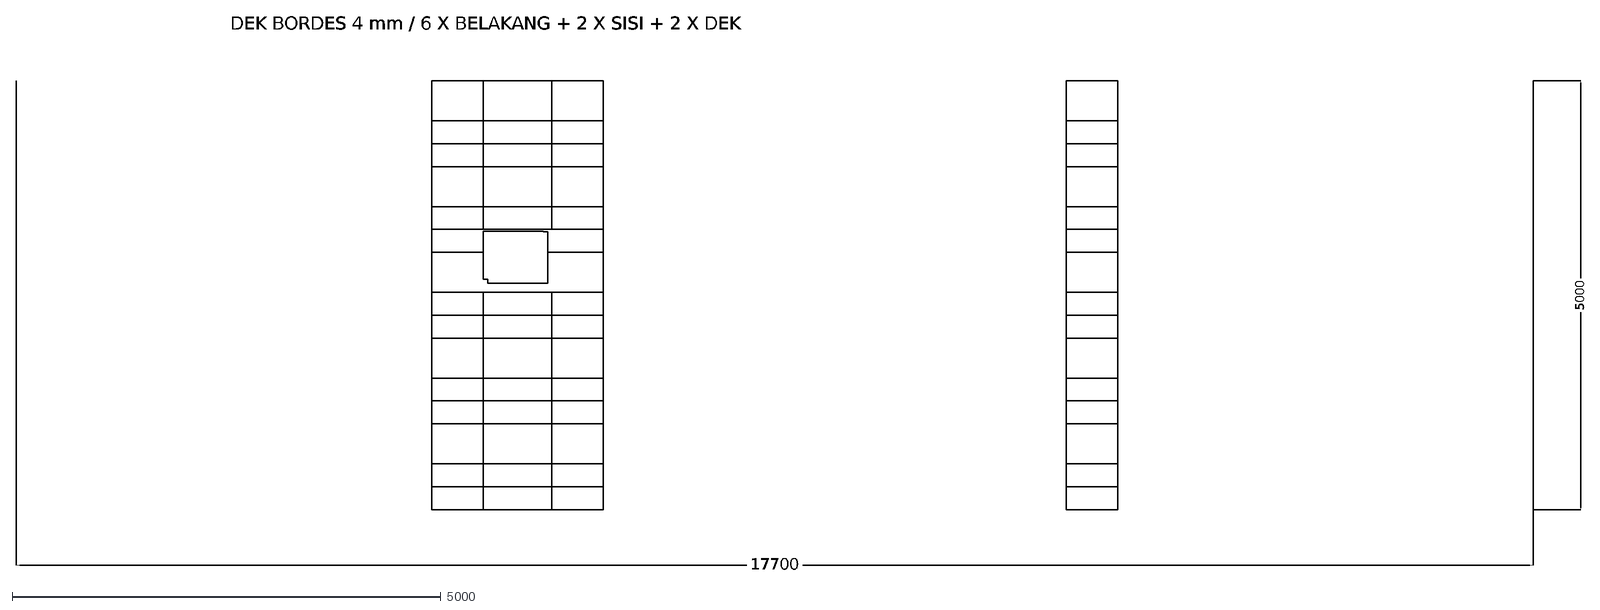
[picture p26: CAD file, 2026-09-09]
assets/r04/T-01.dxf
17700
5000
DEK BORDES 4 mm / 6 X BELAKANG + 2 X SISI + 2 X DEK

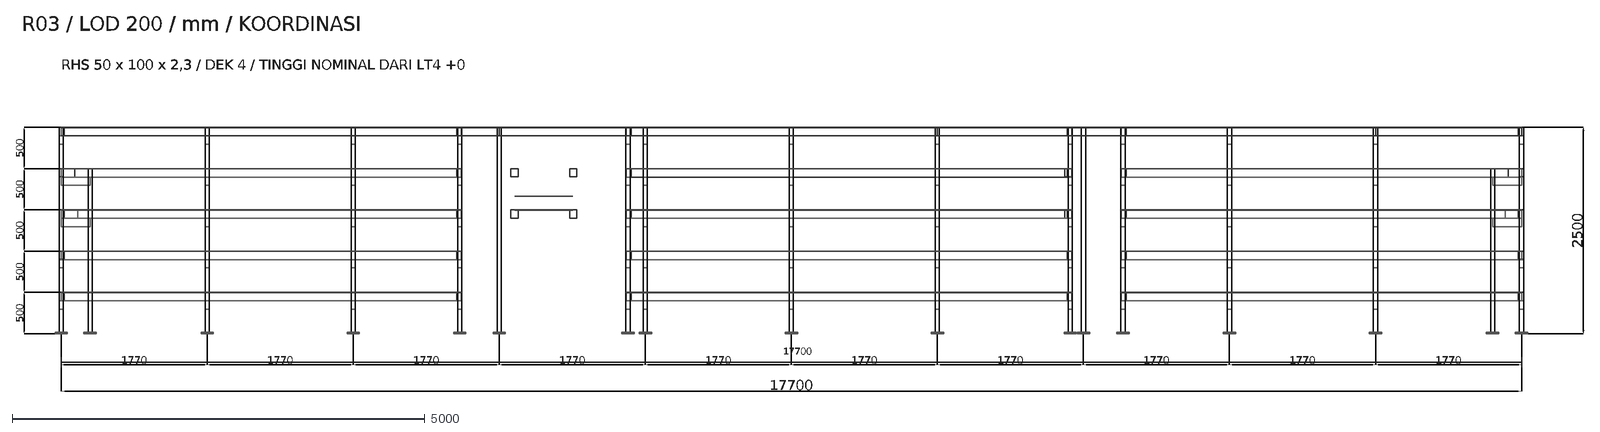
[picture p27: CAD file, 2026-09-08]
assets/technical/S-04.dxf
17700
1770
2500
500
RHS 50 x 100 x 2,3 / DEK 4 / TINGGI NOMINAL DARI LT4 +0
R03 / LOD 200 / mm / KOORDINASI

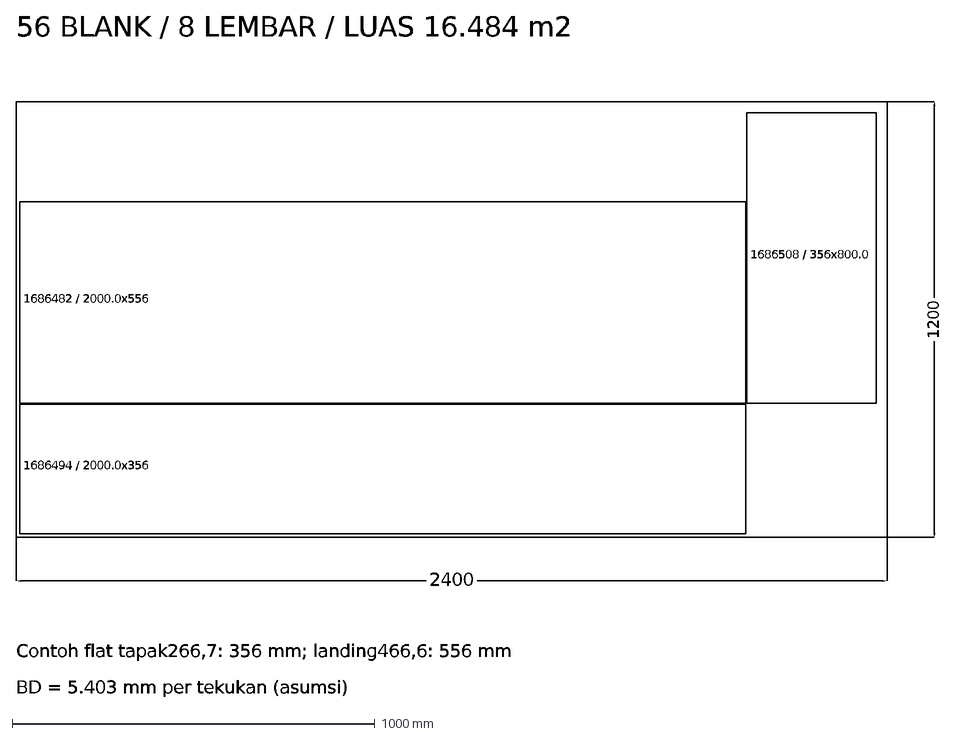
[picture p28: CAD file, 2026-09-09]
assets/r04/T-04.dxf
2400
1200
1686494 / 2000.0x356
1686482 / 2000.0x556
1686508 / 356x800.0
56 BLANK / 8 LEMBAR / LUAS 16.484 m2
Contoh flat tapak266,7: 356 mm; landing466,6: 556 mm
BD = 5.403 mm per tekukan (asumsi)

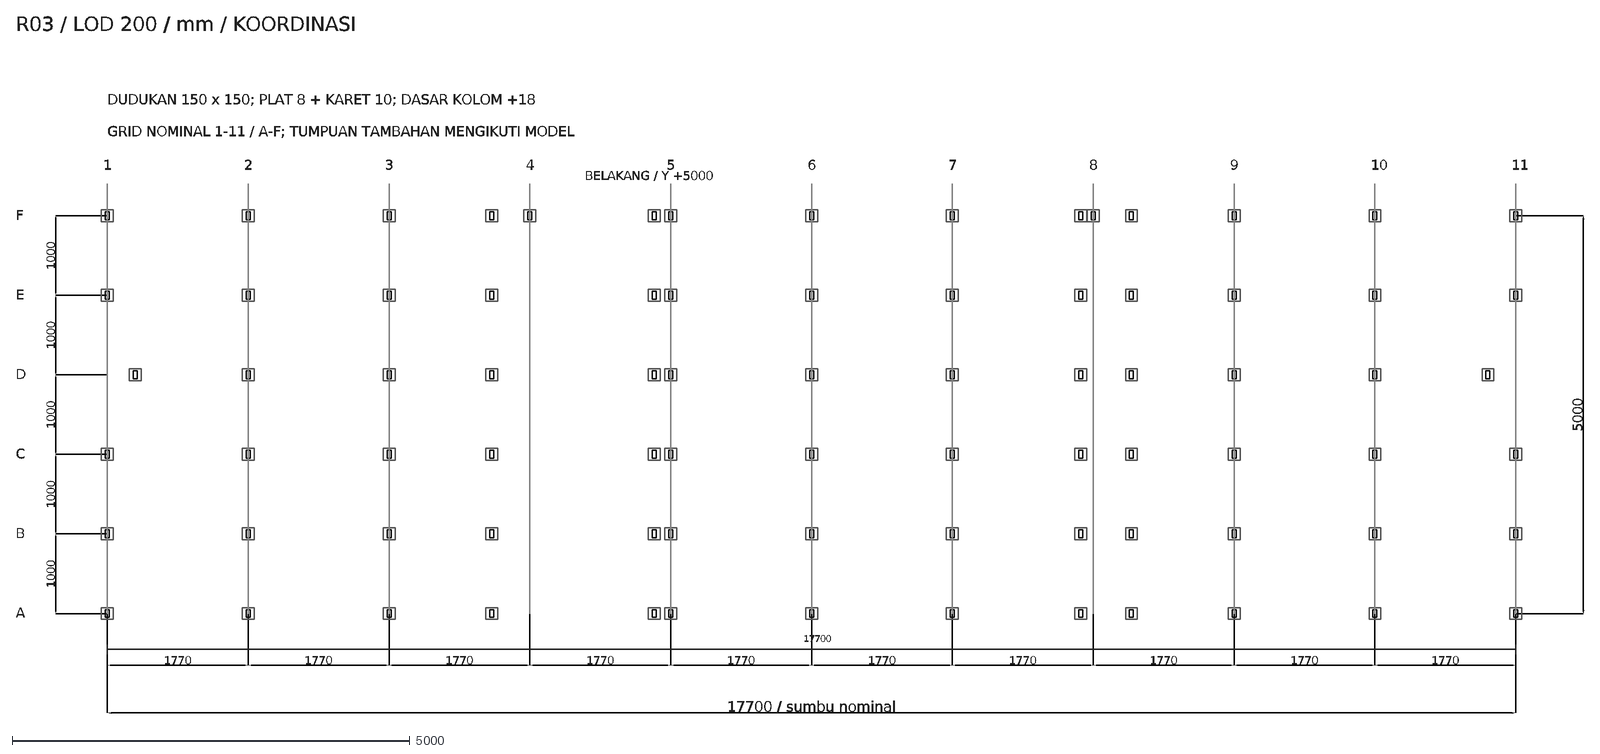
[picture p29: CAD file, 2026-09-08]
assets/technical/S-02.dxf
17700 / sumbu nominal
5000
1770
1000
17700
BELAKANG / Y +5000
1
2
3
4
5
6
7
8
9
10
11
A
B
C
D
E
F
GRID NOMINAL 1-11 / A-F; TUMPUAN TAMBAHAN MENGIKUTI MODEL
DUDUKAN 150 x 150; PLAT 8 + KARET 10; DASAR KOLOM +18
R03 / LOD 200 / mm / KOORDINASI

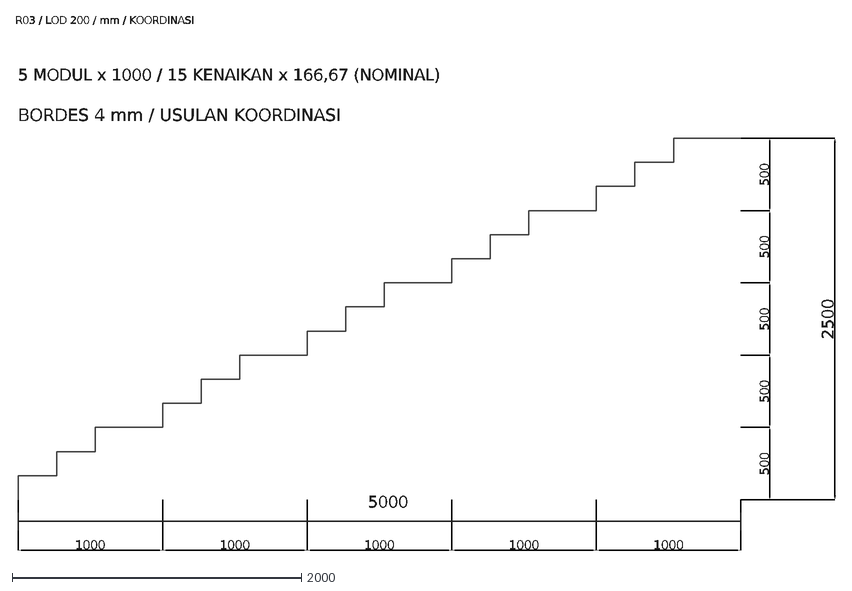
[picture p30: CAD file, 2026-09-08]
assets/technical/S-07.dxf
1000
2500
500
5000
BORDES 4 mm / USULAN KOORDINASI
5 MODUL x 1000 / 15 KENAIKAN x 166,67 (NOMINAL)
R03 / LOD 200 / mm / KOORDINASI

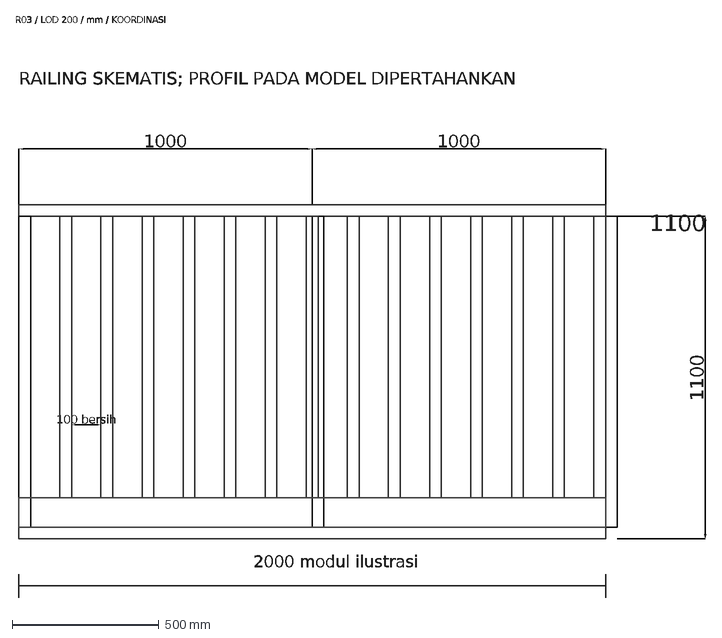
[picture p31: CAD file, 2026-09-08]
assets/technical/S-09.dxf
1000
1100
100 bersih
2000 modul ilustrasi
RAILING SKEMATIS; PROFIL PADA MODEL DIPERTAHANKAN
R03 / LOD 200 / mm / KOORDINASI

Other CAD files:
assets/technical/S-01.dxf
assets/technical/S-03.dxf
assets/technical/S-08.dxf
assets/technical/S-05.dxf

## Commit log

2026-08-27 Perbaiki viewer 3D yang tidak menyala saat halaman dimuat di latar
2026-08-27 Revisi: dek bordes 8 mm, rangka profil tunggal 50x100x2,3, beban SNI 1727:2020 4,79 kPa
2026-08-27 Stempel revisi BOQ: data lama di browser tidak lagi menimpa kuantitas model
2026-08-27 Gamtek: dimensi lengkap semua lembar + penanda material, kolom 50x100, skirt 2 mm tekuk
2026-08-28 Uji tulis lewat connector GitHub
2026-08-28 Hapus berkas uji connector
2026-09-08 Add purchasing-weight fabrication pricing and METTA quotation templates (#1)
    [Daftar-potong-RHS-OPTIMASI-STUDI.csv, S-01.dxf, S-02.dxf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]
2026-09-08 Dimension all METTA technical sheets and document LOD 200 (#2)
    [S-01.dxf, S-02.dxf, S-03.dxf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]
2026-09-09 Update METTA R04 model, drawings and itemized all-in RAB (#4)
    [T-01.dxf, T-02.dxf, T-03.dxf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]
2026-09-09 Add editable execution timeline and detailed fastener RAB (#7)
    * Add editable execution cards/Gantt and itemized fastener suppliers
    * Preserve UTF-8 BOM in exported RAB CSV
    [rab-R04.csv]
2026-09-09 Restore editable offer and payment terms with corporate A4 print layout (#10)
2026-09-09 Add separate material labor and custom-scope offers (#12)
2026-09-11 Add model-based BOQ thickness comparisons and audited stock quantities (#18)
    [pola-pelat6mm.csv, pola-potong-101-batang.csv]
2026-09-11 Add component subtotals and R06 structural/economic study with coordination drawings (#20)
    [perbandingan.csv]
2026-09-11 Reaudit model quantities and correct exact 1200x2400 plate masses (#22)
    [quantity-reaudit.csv]
2026-09-12 Add R07 review package and detailed RAB PDFs (#23)
    * Publish R07 engineering review package and detailed RAB PDFs
    * Fix R07 SVG validation to use standard-library XML parser
    [RAB-review.csv, daftar-potong-review.csv, form-ukur-lapangan.csv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]
2026-09-15 Add R08 middle-panel infill and outer side mesh option (#27)
    * Add R08 central infill and side mesh study with reconciled BOQ
    * Hide mesh controls outside R08 and format Indonesian quantities
    [daftar-potong.csv]
2026-09-15 Replace sketched stair with seating and compare structural A C options (#29)
    [daftar-potong-a.csv, daftar-potong-c.csv, daftar-potong.csv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]
